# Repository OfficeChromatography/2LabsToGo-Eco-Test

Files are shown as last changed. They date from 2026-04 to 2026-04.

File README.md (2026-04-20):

# 2LabsToGo-Eco

# Important Preliminary Note
<b>In our publication (reference 1) we recommended asking our electronic workshop for a quote on the electronic boards. Unfortunately, that turned out to be very difficult. We therefore recommend contacting Chromnil (https://chromnil.com/), a young start-up also providing the electronic boards or even the 2LabsToGo-Eco ready mounted.<br>
<br>

## 2LabsToGo-Eco combines an analytical (high-performance thin-layer chromatography) and a biological (bioassays) laboratory.

### References:  
<ol>
<li>M.C.O. Romero, K. Jakob, J. Schmidt, T. Nimmerfroh, W. Schwack, G.E.
 Morlock, Consolidating two laboratories into the most sustainable lab of the future: 2LabsToGo-Eco,  Analytica Chimica Acta (2025) 1367, 344103 (https://doi.org/10.1016/j.aca.2025.344103).</li>
<li>A. Haase, W. Schwack, G. Morlock, Humidity control for the 2LabsToGo-Eco, 
Analytica Chimica Acta (2026), 1382, 344811 (https://doi.org/10.1016/j.aca.2025.344811).</li>
<li>W. Schwack, J. Morlock, L. Sing, G. Morlock, Faster Operation of 2LabsToGo-Eco 
 Using Debian 13, Django 5, and Raspberry Pi 5, verified via screening of cannabidiol-containing oils,
 Journal of Planar Chromatography (2026), in revision.</(li>
</ol>
This repository contains the folders for the hardware, firmware, and software for 2LabsToGo-Eco.
For details and instructions consult the given references.

### 1. Raspberry Pi operating system (OS)
The recent Raspberry Pi OS is based on Debain 13 (Trixie, https://www.raspberrypi.com/software/operating-systems/) 
that can be used to install 2LabsToGo-Eco on both the Raspberry Pi 4B and 
the Raspberry Pi 5B (see reference 3).

### 2. Clone the 2LabsToGo-Eco repository
The simplest way to clone a git repository (internet access required!) is opening a new terminal being in the home directory.<br>
Then, copy and paste the next command and press enter.
```bash
git clone https://github.com/OfficeChromatography/2LabsToGo-Eco.git
```
### 3. Installing the software
To install the software, consult this [README](https://github.com/OfficeChromatography/2LabsToGo-Eco/blob/main/2LabsToGo-Eco-Software/README.md).

### 4. Flashing the firmware
Instructions to flash the firmware, can be found [here](https://github.com/OfficeChromatography/2LabsToGo-Eco/blob/main/2LabsToGo-Eco-Firmware/README.md).

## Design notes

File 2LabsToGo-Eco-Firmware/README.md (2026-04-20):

# 2LabsToGo-Eco Firmware 
A Marlin 2.0 3D Printer based Firmware

## Marlin 2.0

Marlin 2.0 takes this popular RepRap firmware to the next level by adding support for much faster 32-bit and ARM-based boards while improving support for 8-bit AVR boards. Read about Marlin's decision to use a "Hardware Abstraction Layer" below.

## Building 2LabsToGo-Eco Firmware

To build the firmware, [PlatformIO](http://docs.platformio.org/en/latest/ide.html#platformio-ide) is preferred. 
Detailed instructions are also available in [Instruction Visual Studio Code](https://github.com/OfficeChromatography/2LabsToGo-Eco/blob/main/2LabsToGo-Eco-Firmware/Instruction%20Visual%20Studio%20Code.pdf).

For building the firmware open the folder 2LabsToGo-Eco-Marlin in Visual Studio Code.
The built firmware.hex file is then saved in 2LabsToGo-Eco-Firmware/2LabsToGo-Eco-Marlin/.pio/build/mega2560.

<b>However, building the firmware is only required, if the Marlin codes have been modified.</b><a>

A pre-built firmware file (firmware_2LabsToGo-Eco.hex) is available in this folder, including files for setting the fuses and flashing the bootloader.
To flash the firmware from the Raspberry Pi onto the Arduino chip of the 2LabsToGo-Eco mainboard, 
use the bash script <u>2LabsToGo-Eco-Firmware/Bullseye/flash_firmware_bullseye.sh</u> or 
<u>2LabsToGo-Eco-Firmware/Trixie/flash_firmware_trixie.sh</u>, depending upon the used Raspberry Pi OS.

For more details on flashing, consult the [2LabsToGo-Eco Assembly guide](https://doi.org/10.1016/j.aca.2025.344103) and reference 3 in this [README](https://github.com/OfficeChromatography/2LabsToGo-Eco/blob/main/README.md).
 
## After firmware update
After a firmware update, both PID tunings must be performed again to save the settings in the firmware.<br>
Consult the [2LabsToGo-Eco Assembly guide](https://doi.org/10.1016/j.aca.2025.344103).

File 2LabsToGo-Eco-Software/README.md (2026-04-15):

# 2LabsToGo-Eco-Software
## Installation
The installation process is really simple. 

2LabsToGo-Eco-Software works fine on a Raspberry Pi 4B or 5B with 4GB RAM memory.

As operation system, Raspberry Pi OS (Debian 13, trixie, 64-bit) is recommended,
installed by the [Raspberry Pi Imager](https://www.raspberrypi.com/software/) (see reference 3 in 
this [README](https://github.com/OfficeChromatography/2LabsToGo-Eco/blob/main/README.md)).

Before the next steps, consult the [checklist](https://github.com/OfficeChromatography/2LabsToGo-Eco/blob/main/2LabsToGo-Update-History/checklist.pdf).

To clone the 2LabsToGo-Eco repository, consult this [README](https://github.com/OfficeChromatography/2LabsToGo-Eco/blob/main/README.md).

### Execute 'install.py'
To install 2LabsToGo-Eco-Software, go to the folder that contains the 2LabsToGo-Eco-Software with

```bash
cd /path/to/your/2LabsToGo-Eco-Software
```
Then execute
```bash
sudo python3 install.py |& tee install-py.log
```

This will install:
```
docker and some software packages
```
After some minutes, 2LabsToGo-Eco-Software is installed in your device.

To start the server execute the run.py file with
```
sudo python3 run.py |& tee run-py.log
```
This process takes a while, when executed the first time. The log files can be consulted in case of any problem.<a>

To quit the Django server, press
```
Ctrl+c 
```

2LabsToGo-Eco-Software was intensively tested with both Chromium and Firefox as browser.

To use the software consult the 2LabsToGo-Eco-Software Manual (see reference 1 in 
this [README](https://github.com/OfficeChromatography/2LabsToGo-Eco/blob/main/README.md)).

### Useful guides

[Docker Commands](https://towardsdatascience.com/15-docker-commands-you-should-know-970ea5203421)

[Remove Migrations](https://simpleisbetterthancomplex.com/tutorial/2016/07/26/how-to-reset-migrations.html)

All commands must be executed inside the docker-compose. To enter to the docker-compose running instance:

In a running container:
```sh
sudo docker-compose exec -ti app bash
```
To initialize and enter the terminal
```sh
sudo docker-compose run -ti app bash
```

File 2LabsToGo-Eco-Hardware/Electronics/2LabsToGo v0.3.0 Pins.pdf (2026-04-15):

2LabsToGo V0.3.0 Pinout List

Arduino Pin Malin Analog Marlin Pin Atmega Port Funktion
22 | 22 | A0 | DHT22 Incubator
23 | 23 | A1 | Heater Bed
24 | 24 | A2 | Heater Incubator
25 | 25 | A3 | Expansion
26 | 26 | A4 | Expansion
27 | 27 | A5 | Expansion
28 | 28 | A6 | Expansion
29 | 29 | A7 | Expansion
53 | 53 | B0 | E0-DIR
52 | 52 | B1 | SPI SCLK
51 | 51 | B2 | SPI MOSI
50 | 50 | B3 | SPI MISO
10 | 10 | B4 | Z-EN
11 | 11 | B5 | Z-STEP
12 | 12 | B6 | Z-DIR
13 | 13 | B7 | LED Backlight
37 | 37 | C0 | HF-Valve
36 | 36 | C1 | 3-WAY-Valve
35 | 35 | C2 | Expansion
34 | 34 | C3 | Expansion
33 | 33 | C4 | Expansion
32 | 32 | C5 | Expansion
31 | 31 | C6 | Expansion
30 | 30 | C7 | Expansion
21 | 21 | D0 | I2C SLC
20 | 20 | D1 | I2C SDA
19 | 19 | D2 | NC
18 | 18 | D3 | NC
| 81 | D4 | NC
| 82 | D5 | NC
| 83 | D6 | NC
38 | 38 | D7 | NC
0 | 0 | E0 | UART RX
1 | 1 | E1 | UART TX
| 78 | E2 | NC
5 | 5 | E3 | UV-LED 1 (265)
2 | 2 | E4 | UV-LED 2 (365)
3 | 3 | E5 | Nebulizer
| 79 | E6 | Y-EN
| 80 | E7 | Y-STEP
A0/54 | A0 54 | F0 | Neopixel
A1/55 | A1 55 | F1
A2/56 | A2 56 | F2
A3/57 | A3 57 | F3 | Expansion
A4/58 | A4 58 | F4 | Expansion
A5/59 | A5 59 | F5 | Expansion
A6/60 | A6 60 | F6 | Expansion
A7/61 | A7 61 | F7 | Expansion
41 | 41 | G0 | Case Light

2LabsToGo V0.3.0 Pinout List

40 | 40 | G1 | PUMPE
39 | 39 | G2 | Expansion
| 71 | G3 | NC
| 70 | G4 | NC
4 | 4 | G5 | NC
17 | 17 | H0 | Y-DIR
16 | 16 | H1 | X-EN
| 84 | H2 | X-STEP
6 | 6 | H3 | X-DIR
7 | 7 | H4 | E0-EN
8 | 8 | H5 | E0-STEP
9 | 9 | H6 | Heater External
| 85 | H7
15 | 15 | J0 | Expansion
14 | 14 | J1 | Expansion
| 72 | J2 | Expansion
| 73 | J3 | Expansion
| 75 | J4 | Expansion
| 76 | J5 | Expansion
| 77 | J6 | Expansion
| 74 | J7 | NC
A8/62 | A8 62 | K0 | Expansion
A9/63 | A9 63 | K1 | Expansion
A10/64 | A10 64 | K2 | Expansion
A11/65 | A11 65 | K3 | Expansion
A12/66 | A12 66 | K4 | Expansion
A13/67 | A13 67 | K5 | Termistor Incubator
A14/68 | A14 68 | K6 | Termistor Bed
A15/69 | A15 69 | K7 | Thermistor External
47 | 49 | L0 | Switch Z-Axis to Syringe Pump
48 | 48 | L1 | Z-MIN (switched)
47 | 47 | L2 | X-MAX
46 | 46 | L3 | X-MIN
45 | 45 | L4 | Y-MAX
42 | 44 | L5 | Y-MIN
41 | 43 | L6 | Z-MAX
42 | 42 | L7 | DHT22 Kammer

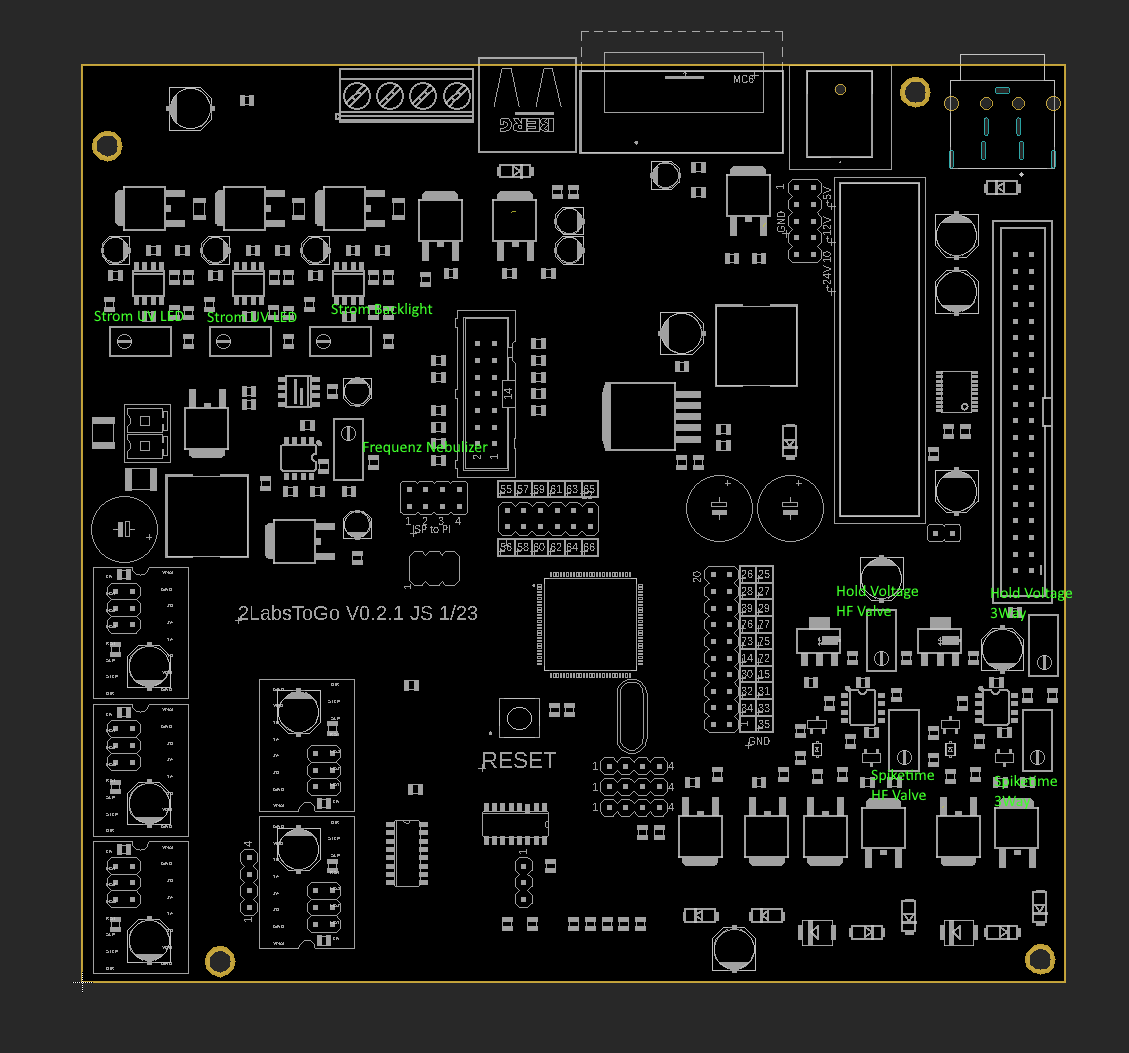
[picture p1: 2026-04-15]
2LabsToGo-Eco-Hardware/Electronics/poti_raw.PNG

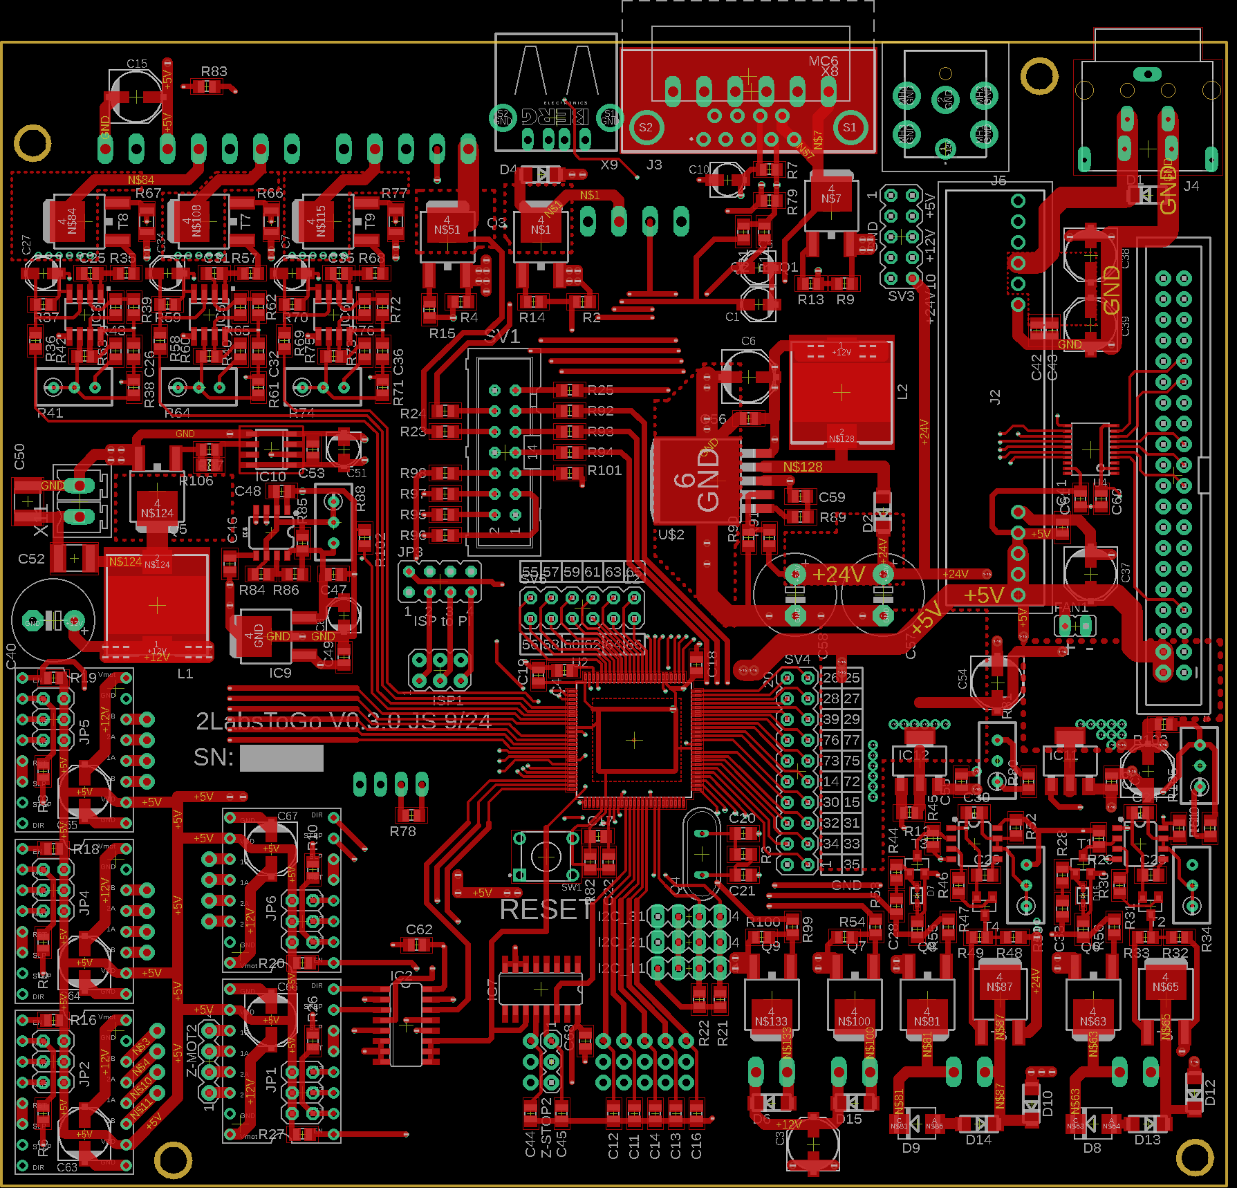
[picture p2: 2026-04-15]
2LabsToGo-Eco-Hardware/Electronics/Mainboard/Layout Top.png

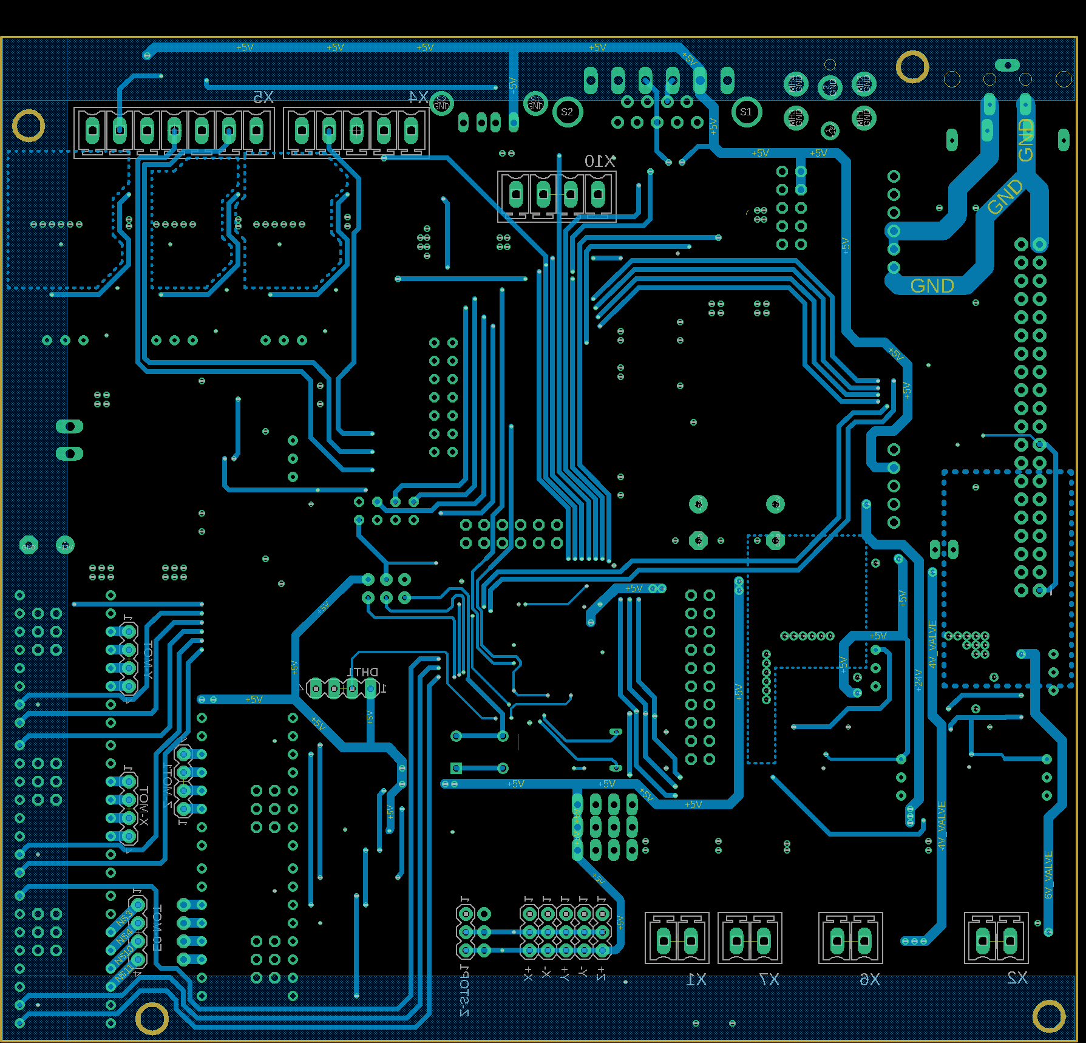
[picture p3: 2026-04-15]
2LabsToGo-Eco-Hardware/Electronics/Mainboard/Layout Bottom.png

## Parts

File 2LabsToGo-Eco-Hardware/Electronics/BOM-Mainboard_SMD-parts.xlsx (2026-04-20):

 | SMD parts
ID | Designator | Qty. | Manufacturer | Manufacturer Part # | Description | Type | Footprint
1 | C2,C3,C6,C15,C37,C38,C39,C54,C63,C64,C65,C66,C67 | 13 | Panasonic | EEE-FK1E101XP | Aluminium Electrolytic Capacitors - SMD 100uF 25V | SMD | PANASONIC_D_334
2 | C9,C11,C12,C13,C14,C16,C17,C18,C19,C23,C24,C25,C26,C29,C31,C32,C35,C36,C4,C41,C42,C43,C44,C45,C47,C49,C53,C55,C56,C60,C61,C62,C68 | 33 | KEMET | C0805C104K5RACTU | Multilayer Ceramic Capacitors MLCC - SMD/SMT 50V 0.1uF X7R 0805 10% | SMD | C0805
3 | C20,C21 | 2 | KEMET | C0805C220K5RACTU | Multilayer Ceramic Capacitors MLCC - SMD/SMT 50V 22pF X7R 0805 10% | SMD | C0805_334
4 | C28,C33 | 2 | KEMET | C0805C681K5RACTU | Multilayer Ceramic Capacitors MLCC - SMD/SMT 50V 680pF X7R 0805 10% | SMD | C0805_334
5 | C30,C46 | 2 | KEMET | C0805C223K5RACTU | Multilayer Ceramic Capacitors MLCC - SMD/SMT 50V 0.022uF X7R 0805 10% | SMD | C0805_334
6 | C1,C5,C7,C8,C10,C27,C34,C51 | 8 | Panasonic | EEE-FK1E100AR | Aluminium Electrolytic Capacitors - SMD 10UF 25V FK SMD | SMD | PANASONIC_B_334
7 | C22,C48 | 2 | KEMET | C0805C101F3HACTU | Multilayer Ceramic Capacitors MLCC - SMD/SMT 25V 100pF X8R 0805 1% | SMD | C0805_334
8 | C50 | 1 | KEMET | C1812C102KHRACTU | Multilayer Ceramic Capacitors MLCC - SMD/SMT 3kV 1000pF X7R 1812 10% | SMD | C1812_334
9 | C52 | 1 | KEMET | C1812C334KCRACTU | Multilayer Ceramic Capacitors MLCC - SMD/SMT 500V 0.33uF X7R 1812 10% | SMD | C1812_334
10 | C59 | 1 | KEMET | C0805C473K5RACTU | Multilayer Ceramic Capacitors MLCC - SMD/SMT 50V 0.047uF X7R 0805 10% | SMD | C0805
11 | D4,D6,D12,D13,D14,D15 | 6 | onsemi | RGF1G | Rectifiers 400V 1a Rectifier Glass Passivated | SMD | DO214AC_210
12 | D7,D16 | 2 | onsemi | 1N4148WS | Small Signal Switching Diodes Small Signal Diode | SMD | SOD-323_11396254
13 | D1,D2,D10 | 3 | Comchip Technology | SS54-HF | Schottky Diodes & Rectifiers DIODE SCHOTTKY 5A 40V SMA | SMD | DO214AC
14 | D8,D9 | 2 | Vishay | SML4757A-E3/61 | Zener Diodes 51 Volt 1.0W 5% | SMD | DO-214AC-2
15 | IC10 | 1 | Microchip Technology | MIC4420ZM-TR | Gate Drivers 8 SOIC 3.90mm(.150in) T/R | SMD | SOIC-8
16 | IC11,IC12 | 2 | onsemi | LM1117MPX-ADJNOPB | LDO Voltage Regulators LM ANA SOT223 800MA LDO | SMD | SOT-223-3
17 | IC2,IC7 | 2 | Nexperia | 74HC4053D,653 | Multiplexer Switch ICs Triple 2-channel analog multiplexer/demultiplexer | SMD | SOIC-16
18 | IC1,IC4 | 2 | Texas Instruments | NE555DR | Timers & Support Products Precision A 595-NE555D | SMD | SOIC-8
19 | IC3,IC5,IC6 | 3 | Texas Instruments | LM358MX/NOPB | Operational Amplifiers - Op Amps LOW PWR DUAL OP AMP A 926-LM358M/NOPB | SMD | SOIC-8
20 | IC8 | 1 | Texas Instruments | SE555DRG4 | Timers & Support Products Prec Timer ALT 595-SE555DR | SMD | SOIC-8
21 | IC9 | 1 | Diodes Incorporated | AS7805ADTR-G1 | Linear Voltage Regulators 1A 3-Term POS Reg Output 1A | SMD | TO-252-2
22 | Q1,Q2,Q3,Q6,Q7,Q8,Q9 | 7 | Infineon Technologies | IRFR3410TRPBF | MOSFETs 100V SINGLE N-CH 39mOhms 37nC | SMD | TO-252-3
23 | Q5 | 1 | Infineon Technologies | IPD60R180P7SAUMA1 | MOSFETs CONSUMER | SMD | TO-252-3
24 | R10,R9,R56,R55,R6,R2,R26,R5,R8,R54,R100,R4,R82 | 13 | YAGEO | RC0805FR-07100KL | Thick Film Resistors - SMD 100 kOhms 125 mW 0805 1% | SMD | R0805_334
25 | R103,R12 | 2 | YAGEO | RC0805FR-13120RL | Thick Film Resistors - SMD 120Ohms 1/8W 0805 1% | SMD | R0805_334
26 | R13,R14,R15,R31,R47,R53,R87,R99,R106 | 9 | YAGEO | RC0805FR-0710RL | Thick Film Resistors - SMD 10 Ohms 125 mW 0805 1% | SMD | R0805_334
27 | R23,R24,R25,R35,R38,R40,R57,R61,R63,R68,R71,R73,R90,R95,R96,R97 | 16 | YAGEO | RC0805FR-071KL | Thick Film Resistors - SMD 1 kOhms 125 mW 0805 1% | SMD | R0805_334
28 | R16,R18,R19,R20,R27,R29,R32,R36,R43,R45,R48,R58,R65,R69,R76,R78,R79 | 17 | YAGEO | RC0805FR-0710KL | Thick Film Resistors - SMD 10 kOhms 125 mW 0805 1% | SMD | R0805_334
29 | R3,R39,R62,R72 | 4 | YAGEO | RC0805FR-071ML | Thick Film Resistors - SMD 1 MOhms 125 mW 0805 1% | SMD | R0805_334
30 | R66,R67,R77 | 3 | YAGEO | RL1206FR-070R1L | Current Sense Resistors - SMD 100 mOhms 250mW 1 % 600 ppm/C | SMD | R1206_334
31 | R1,R7,R11,R21,R22,R33,R37,R49,R59,R70,R102 | 11 | YAGEO | RC0805FR-074K7L | Thick Film Resistors - SMD 4.7 kOhms 125 mW 0805 1% | SMD | R0805_334
32 | R83 | 1 | YAGEO | RC0805FR-07100RL | Thick Film Resistors - SMD 100 Ohms 125 mW 0805 1% | SMD | R0805_334
33 | R84 | 1 | YAGEO | RC0805JR-7W15KL | Thick Film Resistors - SMD 15kOhms 1/8W 0805 5% | SMD | R0805_334
34 | R89 | 1 | YAGEO | RC0805FR-073KL | Thick Film Resistors - SMD 3 kOhms 125 mW 0805 1% | SMD | R0805_334
35 | R91 | 1 | YAGEO | RC0805FR-0718K2L | Thick Film Resistors - SMD 18.2 kOhms 125 mW 0805 1% | SMD | R0805_334
36 | R94,R92,R30,R98,R28,R46,R101,R93,R44 | 9 | YAGEO | RC0805FR-07330RL | Thick Film Resistors - SMD 330 Ohms 125 mW 0805 1% | SMD | R0805_334
37 | T3,T1,T2,T4 | 4 | Nexperia | BC847C,215 | Bipolar Transistors - BJT 45 V, 100 mA NPN general-purpose transistors | SMD | SOT23_3
38 | T5,T6 | 2 | onsemi | MJD128T4G | Darlington Transistors BIP PNP 8A 120V TR | SMD | TO-252-3
39 | T7,T8,T9 | 3 | onsemi | MJD200G | Bipolar Transistors - BJT 5A 25V 12.5W NPN | SMD | TO-252-3
40 | U$2 | 1 | Texas Instruments | LM2577SX-ADJ/NOPB | IC REG BST FLYBACK ADJ 3A TO263 | SMD | TO-263-5
41 | U2 | 1 | Microchip Technology | ATMEGA2560-16AU | AVR AVR® ATmega Mikrocontroller IC 8-Bit 16MHz 256KB (128K x 16) FLASH 100-TQFP (14x14) | SMD | TQFP-100
42 | U4 | 1 | Texas Instruments | TXB0108PWR | Translation - Voltage Levels 8-Bit Bi-directional V-Level Translator A 595-TXB0108PWRG4 | SMD | TSSOP-20
43 | L1 | 1 | Würth Elektronik | 74477020 | FIXED IND 100UH 2.2A 220 MOHM | SMD
44 | L2 | 1 | Würth Elektronik | 744770222 | FIXED IND 220UH 1.3A 390 MOHM | SMD

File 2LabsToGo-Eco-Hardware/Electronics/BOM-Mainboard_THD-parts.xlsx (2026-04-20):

 | Through hole parts (THD)
ID | Designator | Qty. | Manufacturer | Manufacturer Part # | Description | Type | Footprint
1 | C40, C57, C58 | 3 | Panasonic Electronic Components | EEU-FR1V471L | CAP ALUM 470UF 20% 35V RADIAL TH | THD
2 | J4 | 1 | Kycon Inc. | KPJX-4S-S | CONN JACK FMALE 4POS TIN SOLDER | THD
3 | J5 | 2 | Same Sky (Formerly CUI Devices) | PJ-082BH | CONN PWR JACK 2.5X5.5MM SOLDER | THD
4 | J6 | 1 | 3M | Y2540-6002-SH 40P ST HDR 0.112 GF | 3M FOUR-WALL HEADER 2500 SERIES | THD
5 | Q4 | 1 | Abracon LLC | ABL-16.000MHZ-B2 | CRYSTAL 16.0000MHZ 18PF TH | THD
6 | R105 | 1 | Bourns Inc. | 3296W-1-102LF | TRIMMER 1K OHM 0.5W PC PIN TOP | THD
7 | R34, R50 | 2 | Bourns Inc. | 3296W-1-504LF | TRIMMER 500K OHM 0.5W PC PIN TOP | THD
8 | R41, R64, R74 | 3 | Bourns Inc. | 3296W-1-204LF | TRIMMER 200K OHM 0.5W PC PIN TOP | THD
9 | R81 | 1 | Bourns Inc. | 3296W-1-501LF | TRIMMER 500 OHM 0.5W PC PIN TOP | THD
10 | SV1 | 1 | 3M | Y2514-6002-SH 14P ST HDR 0.112 GF | 3M FOUR-WALL HEADER 2500 SERIES | THD
11 | U$1, U$4, U$6, U$7, U$8 | 20 | Amphenol CS (FCI) | 75915-308GLF | CONN RCPT 8POS 0.1 GOLD PCB | THD
12 | X1, X2, X6, X7, X11 | 5 | Phoenix Contact | 1803426 | TERM BLOCK HDR 2POS 3.81MM | THD
13 | X4 | 2 | Phoenix Contact | 1803455 | TERM BLOCK HDR 5POS 3.81MM | THD
14 | X5 | 1 | Phoenix Contact | 1803471 | TERM BLOCK HDR 7POS 3.81MM | THD
15 | X9 | 1 | Amphenol CS (FCI) | 87520-0010BLF | CONN RCPT USB2.0 TYPEA 4POS R/A | THD
16 | I2C_1, I2C_2, I2C_3, Z-MOT1, Z-MOT2, X-MOT, Y-MOT, E0-MOT, Z-STOP1, Z-STOP2, X-, X+, Y-, Y+, Z+, FAN1 | 3 | Amphenol CS (FCI) | 68002-420HLF | CONN HEADER VERT 20POS 2.54MM 1) | THD
17 | JP3 | 1 | Amphenol CS (FCI) | 67996-408HLF | CONN HEADER VERT 8POS 2.54MM | THD
18 | ISP1, JP1, JP2, JP4, JP5, JP6 | 6 | Amphenol CS (FCI) | 67996-406HLF | CONN HEADER VERT 6POS 2.54MM | THD
19 | SV3 | 1 | Amphenol CS (FCI) | 67996-410HLF | CONN HEADER VERT 10POS 2.54MM | THD
20 | SV4 | 1 | Amphenol CS (FCI) | 67996-420HLF | CONN HEADER VERT 20POS 2.54MM | THD
21 | SV5 | 1 | Amphenol CS (FCI) | 67996-412HLF | CONN HEADER VERT 12POS 2.54MM | THD
22 | X8 | 1 | Phoenix Contact | 1876301 | TERM BLOCK HDR 6POS 3.50MM | THD
23 | SW1 | 1 | TE Connectivity ALCOSWITCH Switches | 1825910-6 | SWITCH TACTILE SPST-NO 0.05A 24V | THD
24 | R88 | 1 | Bourns Inc. | 3296W-1-104ALF | TRIMMER 100K OHM 0.5W PC PIN TOP | THD
25 | J2 | 1 | Mean Well USA Inc. | NID65-5 | DC DC CONVERTER 5V 33W | THD
26 | X10 | 1 | Phoenix Contact | 1755752 | TERM BLOCK HDR 4POS 5.08MM | THD
27 | DHT1 | 1 | Molex | 901471104 | CONN RCPT 4POS 0.1 TIN PCB | THD
 | 1) Header to be cut to 2-pin (FAN1), 3-pin (Z-STOP1, Z-STOP2, X-, X+, Y-, Y+, Z+) and 4-pin (I2C_1, I2C_2, I2C_3, Z-MOT1, Z-MOT2, X-MOT, Y-MOT, E0-MOT) parts, respectively

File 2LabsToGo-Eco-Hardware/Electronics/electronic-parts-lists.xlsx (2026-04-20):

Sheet: mainboard
 | SMD parts
ID | Designator | Manufacturer No | Manufacturer | Description | Termination Style | Footprint | Qty.
1 | C2,C3,C6,C15,C37,C38,C39,C54,C63,C64,C65,C66,C67 | EEE-FK1E101XP | Panasonic | Aluminium Electrolytic Capacitors - SMD 100uF 25V | SMD | PANASONIC_D_334 | 13
2 | C9,C11,C12,C13,C14,C16,C17,C18,C19,C23,C24,C25,C26,C29,C31,C32,C35,C36,C4,C41,C42,C43,C44,C45,C47,C49,C53,C55,C56,C60,C61,C62,C68 | C0805C104K5RACTU | KEMET | Multilayer Ceramic Capacitors MLCC - SMD/SMT 50V 0.1uF X7R 0805 10% | SMD | C0805 | 33
3 | C20,C21 | C0805C220K5RACTU | KEMET | Multilayer Ceramic Capacitors MLCC - SMD/SMT 50V 22pF X7R 0805 10% | SMD | C0805_334 | 2
4 | C28,C33 | C0805C681K5RACTU | KEMET | Multilayer Ceramic Capacitors MLCC - SMD/SMT 50V 680pF X7R 0805 10% | SMD | C0805_334 | 2
5 | C30,C46 | C0805C223K5RACTU | KEMET | Multilayer Ceramic Capacitors MLCC - SMD/SMT 50V 0.022uF X7R 0805 10% | SMD | C0805_334 | 2
6 | C1,C5,C7,C8,C10,C27,C34,C51 | EEE-FK1E100AR | Panasonic | Aluminium Electrolytic Capacitors - SMD 10UF 25V FK SMD | SMD | PANASONIC_B_334 | 8
7 | C22,C48 | C0805C101F3HACTU | KEMET | Multilayer Ceramic Capacitors MLCC - SMD/SMT 25V 100pF X8R 0805 1% | SMD | C0805_334 | 2
8 | C50 | C1812C102KHRACTU | KEMET | Multilayer Ceramic Capacitors MLCC - SMD/SMT 3kV 1000pF X7R 1812 10% | SMD | C1812_334 | 1
9 | C52 | C1812C334KCRACTU | KEMET | Multilayer Ceramic Capacitors MLCC - SMD/SMT 500V 0.33uF X7R 1812 10% | SMD | C1812_334 | 1
10 | C59 | C0805C473K5RACTU | KEMET | Multilayer Ceramic Capacitors MLCC - SMD/SMT 50V 0.047uF X7R 0805 10% | SMD | C0805 | 1
11 | D4,D6,D12,D13,D14,D15 | RGF1G | onsemi | Rectifiers 400V 1a Rectifier Glass Passivated | SMD | DO214AC_210 | 6
12 | D7,D16 | 1N4148WS | onsemi | Small Signal Switching Diodes Small Signal Diode | SMD | SOD-323_11396254 | 2
13 | D1,D2,D10 | SS54-HF | Comchip Technology | Schottky Diodes & Rectifiers DIODE SCHOTTKY 5A 40V SMA | SMD | DO214AC | 3
14 | D8,D9 | SML4757A-E3/61 | Vishay | Zener Diodes 51 Volt 1.0W 5% | SMD | DO-214AC-2 | 2
15 | IC10 | MIC4420ZM-TR | Microchip Technology | Gate Drivers 8 SOIC 3.90mm(.150in) T/R | SMD | SOIC-8 | 1
16 | IC11,IC12 | LM1117MPX-ADJNOPB | onsemi | LDO Voltage Regulators LM ANA SOT223 800MA LDO | SMD | SOT-223-3 | 2
17 | IC2,IC7 | 74HC4053D,653 | Nexperia | Multiplexer Switch ICs Triple 2-channel analog multiplexer/demultiplexer | SMD | SOIC-16 | 2
18 | IC1,IC4 | NE555DR | Texas Instruments | Timers & Support Products Precision A 595-NE555D | SMD | SOIC-8 | 2
19 | IC3,IC5,IC6 | LM358MX/NOPB | Texas Instruments | Operational Amplifiers - Op Amps LOW PWR DUAL OP AMP A 926-LM358M/NOPB | SMD | SOIC-8 | 3
20 | IC8 | SE555DRG4 | Texas Instruments | Timers & Support Products Prec Timer ALT 595-SE555DR | SMD | SOIC-8 | 1
21 | IC9 | AS7805ADTR-G1 | Diodes Incorporated | Linear Voltage Regulators 1A 3-Term POS Reg Output 1A | SMD | TO-252-2 | 1
22 | Q1,Q2,Q3,Q6,Q7,Q8,Q9 | IRFR3410TRPBF | Infineon Technologies | MOSFETs 100V SINGLE N-CH 39mOhms 37nC | SMD | TO-252-3 | 7
23 | Q5 | IPD60R180P7SAUMA1 | Infineon Technologies | MOSFETs CONSUMER | SMD | TO-252-3 | 1
24 | R10,R9,R56,R55,R6,R2,R26,R5,R8,R54,R100,R4,R82 | RC0805FR-07100KL | YAGEO | Thick Film Resistors - SMD 100 kOhms 125 mW 0805 1% | SMD | R0805_334 | 13
25 | R103,R12 | RC0805FR-13120RL | YAGEO | Thick Film Resistors - SMD 120Ohms 1/8W 0805 1% | SMD | R0805_334 | 2
26 | R13,R14,R15,R31,R47,R53,R87,R99,R106 | RC0805FR-0710RL | YAGEO | Thick Film Resistors - SMD 10 Ohms 125 mW 0805 1% | SMD | R0805_334 | 9
27 | R23,R24,R25,R35,R38,R40,R57,R61,R63,R68,R71,R73,R90,R95,R96,R97 | RC0805FR-071KL | YAGEO | Thick Film Resistors - SMD 1 kOhms 125 mW 0805 1% | SMD | R0805_334 | 16
28 | R16,R18,R19,R20,R27,R29,R32,R36,R43,R45,R48,R58,R65,R69,R76,R78,R79 | RC0805FR-0710KL | YAGEO | Thick Film Resistors - SMD 10 kOhms 125 mW 0805 1% | SMD | R0805_334 | 17
29 | R3,R39,R62,R72 | RC0805FR-071ML | YAGEO | Thick Film Resistors - SMD 1 MOhms 125 mW 0805 1% | SMD | R0805_334 | 4
30 | R66,R67,R77 | RL1206FR-070R1L | YAGEO | Current Sense Resistors - SMD 100 mOhms 250mW 1 % 600 ppm/C | SMD | R1206_334 | 3
31 | R1,R7,R11,R21,R22,R33,R37,R49,R59,R70,R102 | RC0805FR-074K7L | YAGEO | Thick Film Resistors - SMD 4.7 kOhms 125 mW 0805 1% | SMD | R0805_334 | 11
32 | R83 | RC0805FR-07100RL | YAGEO | Thick Film Resistors - SMD 100 Ohms 125 mW 0805 1% | SMD | R0805_334 | 1
33 | R84 | RC0805JR-7W15KL | YAGEO | Thick Film Resistors - SMD 15kOhms 1/8W 0805 5% | SMD | R0805_334 | 1
34 | R89 | RC0805FR-073KL | YAGEO | Thick Film Resistors - SMD 3 kOhms 125 mW 0805 1% | SMD | R0805_334 | 1
35 | R91 | RC0805FR-0718K2L | YAGEO | Thick Film Resistors - SMD 18.2 kOhms 125 mW 0805 1% | SMD | R0805_334 | 1
36 | R94,R92,R30,R98,R28,R46,R101,R93,R44 | RC0805FR-07330RL | YAGEO | Thick Film Resistors - SMD 330 Ohms 125 mW 0805 1% | SMD | R0805_334 | 9
37 | T3,T1,T2,T4 | BC847C,215 | Nexperia | Bipolar Transistors - BJT 45 V, 100 mA NPN general-purpose transistors | SMD | SOT23_3 | 4
38 | T5,T6 | MJD128T4G | onsemi | Darlington Transistors BIP PNP 8A 120V TR | SMD | TO-252-3 | 2
39 | T7,T8,T9 | MJD200G | onsemi | Bipolar Transistors - BJT 5A 25V 12.5W NPN | SMD | TO-252-3 | 3
40 | U$2 | LM2577SX-ADJ/NOPB | Texas Instruments | Switching Voltage Regulators Step-Up Vtg Reg A 926-LM2577S-ADJ/NOPB | SMD | TO-263-5 | 1
41 | U2 | ATMEGA2560-16AU | Microchip Technology | AVR AVR® ATmega Mikrocontroller IC 8-Bit 16MHz 256KB (128K x 16) FLASH 100-TQFP (14x14) | SMD | TQFP-100 | 1
42 | U4 | TXB0108PWR | Texas Instruments | Translation - Voltage Levels 8-Bit Bi-directional V-Level Translator A 595-TXB0108PWRG4 | SMD | TSSOP-20 | 1
43 | L1 | 74477020 | Wurth Electronic | Power Inductors - SMD WE-PD 100uH 2.2A DCR=220mOhms AEC-Q200 | surface mount | WE-CHSA_1212_14076700 | 1
44 | L2 | 744770222 | Wurth Electronic | Power Inductors - SMD WE-PD 220uH 1.3A DCR=390mOhms AEC-Q200 | surface mount | WE-CHSA_1212_14076700 | 1
 | Through hole parts
ID | Designator | Manufacturer No | Manufacturer | Description | Termination Style | Footprint | Qty.
1 | C40,C58,C57 | EEU-FR1V471L | Panasonic | Aluminium Electrolytic Capacitors - Radial Leaded 35VDC 470uF 8x20mm LS5mm | Through Hole | E5-10,5_334 | 3
2 | J2 | NID65-5 | MEAN WELL | Non-Isolated DC/DC Converters 32.5W 24Vin 5Vout Non-Iso Reg SIP | Through Hole | SIP-11 | 1
3 | J4 | KPJX-4S-S | Kycon | DC Power Connectors 4P JACK SKT SHIELDED SNAP AND LOCK | Through Hole | KYCON_KPJX-4S-S | 1
4 | J5 | PJ-082BH | Same Sky (https://www.mouser.de/manufacturer/same-sky/) | DC Power Connectors 2.5mm x 5.5mm horz | Through Hole | PJ082BH_vf.QJzKeZqrQ1Gobk2092XC6w | 1
5 | J6 | Y2540-6002-SH 40P ST HDR 0.112 GF | 3M | Headers & Wire Housings 3M Four-Wall Header 2500 Series, 40 Pin Straight Header, 0.112 Tail Length, Gold Flash | Through Hole | 2X20_SHROUDED_513 | 1
6 | Q4 | ABL-16.000MHZ-B2 | ABRACON | Crystals Xtal HC-49/US 3.5mm Height 16MHz Tol +/-20ppm Stab +/-50ppm -20°C ~ 70°C 18pF 40 Ohms | Through Hole | QS_367 | 1
7 | R105 | 3296W-1-102LF | Bourns | Trimmer Resistors - Through Hole 3/8" 1Kohms Sealed Vertical Adjust | Through Hole | RTRIM3296W | 1
8 | R34,R50 | 3296W-1-504LF | Bourns | Trimmer Resistors - Through Hole 3/8" 500Kohms Sealed Vertical Adjust | Through Hole | RTRIM3296W | 2
9 | R74,R64,R41 | 3296W-1-204LF | Bourns | Trimmer Resistors - Through Hole 3/8" 200Kohms Sealed Vertical Adjust | Through Hole | RTRIM3296W | 3
10 | R81 | 3296W-1-501LF | Bourns | Trimmer Resistors - Through Hole 3/8IN 500 OHM Sealed Vertical Adjust | Through Hole | RTRIM3296W | 1
11 | R88 | 3296W-1-104ALF | YAGEO | Trimmer Resistors - Through Hole 3/8" 100Kohms Sealed Vertical Adjust | Through Hole | RTRIM3296W | 1
12 | SV1 | Y2514-6002-SH 14P ST HDR 0.112 GF | 3M | Headers & Wire Housings 3M Four-Wall Header 2500 Series, 14 Pin Straight Header, 0.112 Tail Length, Gold Flash | Through Hole | ML14_149 | 1
13 | SW1 | 1825910-6 | TE Connectivity | Tactile Switches FSM4JH=6MM TACT SWITCH, HIGH TEMP | Through Hole | 1825910-6_11396471 | 1
14 | U$4,U$1,U$6,U$8,U$7 | 535541-6 | TE Connectivity | Headers & Wire Housings VERT RECPT 8 POS | Through Hole | A4988BREAKOUT | 5x2
15 | X10 | 1757268 | Phoenix Contact | Pluggable Terminal Blocks 4 Pos 5.08mm pitch Through Hole Header | Through Hole | MCV4 | 1
16 | X11,X2,X7,X1,X6 | 1803426 | Phoenix Contact | Pluggable Terminal Blocks 2 Pos 3.81mm pitch Through Hole Header | Through Hole | MCV2 | 5
17 | X4 | 1803455 | Phoenix Contact | Pluggable Terminal Blocks 5 Pos 3.81mm pitch Through Hole Header | Through Hole | MCV5 | 1
18 | X5 | 1803471 | Phoenix Contact | Pluggable Terminal Blocks 7 Pos 3.81mm pitch Through Hole Header | Through Hole | MCV7 | 1
19 | X8 | 1876301 | Phoenix Contact | Pluggable Terminal Blocks 6 Pos 3.5mm pitch Through Hole Header | Through Hole | MC6 | 1
20 | X9 | 87520-0010BLF | Amphenol FCI | USB Connectors USB S/D RECEPT | Through Hole | PN87520-S_130 | 1
21 | I2C_3,I2C_1,I2C_2 | 68002-420HLF | Amphenol FCI | Headers & Wire Housings 20P SR UNSHRD HRD TIN OVER NI | Through Hole | MA04-1 | 3
22 | FAN1 | see 21 |  |  | Through Hole | Ma02-1
23 | Z-MOT2,Y-MOT0,X-MOT0,E0-MOT0,Z-MOT1 | see 21 |  |  | Through Hole | MA04-1
24 | Z-STOP2,Y-0,X-0,X+0,Z-STOP1,Z+0,Y+0 | see 21 |  |  | Through Hole | MA03-1
25 | JP3 | 67996-408HLF | Amphenol FCI | Headers & Wire Housings 8P DR UNSHRD HRD TIN OVER NI | Through Hole | MA04_2, 2x4 pins | 1
26 | SV3 | 67996-410HLF | Amphenol FCI | Headers & Wire Housings 10P DR UNSHRD HRD TIN OVER NI | Through Hole | MA05-2, 2x5 pins | 1
27 | SV4 | 67996-420HLF | Amphenol FCI | Headers & Wire Housings 20P DR UNSHRD HRD TIN OVER NI | Through Hole | MA10-2, 2x10 pins | 1
28 | SV5 | 67996-412HLF | Amphenol FCI | Headers & Wire Housings 12P DR UNSHRD HRD TIN OVER NI | Through Hole | MA06-2, 2x6 pins | 1
 | DHT1?
 | Extern buttom??

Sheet: mainboard-smd
 | SMD parts
ID | Designator | Manufacturer No | Manufacturer | Description | Termination Style | Footprint | Qty.
1 | C2,C3,C6,C15,C37,C38,C39,C54,C63,C64,C65,C66,C67 | EEE-FK1E101XP | Panasonic | Aluminium Electrolytic Capacitors - SMD 100uF 25V | SMD | PANASONIC_D_334 | 13
2 | C9,C11,C12,C13,C14,C16,C17,C18,C19,C23,C24,C25,C26,C29,C31,C32,C35,C36,C4,C41,C42,C43,C44,C45,C47,C49,C53,C55,C56,C60,C61,C62,C68 | C0805C104K5RACTU | KEMET | Multilayer Ceramic Capacitors MLCC - SMD/SMT 50V 0.1uF X7R 0805 10% | SMD | C0805 | 33
3 | C20,C21 | C0805C220K5RACTU | KEMET | Multilayer Ceramic Capacitors MLCC - SMD/SMT 50V 22pF X7R 0805 10% | SMD | C0805_334 | 2
4 | C28,C33 | C0805C681K5RACTU | KEMET | Multilayer Ceramic Capacitors MLCC - SMD/SMT 50V 680pF X7R 0805 10% | SMD | C0805_334 | 2
5 | C30,C46 | C0805C223K5RACTU | KEMET | Multilayer Ceramic Capacitors MLCC - SMD/SMT 50V 0.022uF X7R 0805 10% | SMD | C0805_334 | 2
6 | C1,C5,C7,C8,C10,C27,C34,C51 | EEE-FK1E100AR | Panasonic | Aluminium Electrolytic Capacitors - SMD 10UF 25V FK SMD | SMD | PANASONIC_B_334 | 8
7 | C22,C48 | C0805C101F3HACTU | KEMET | Multilayer Ceramic Capacitors MLCC - SMD/SMT 25V 100pF X8R 0805 1% | SMD | C0805_334 | 2
8 | C50 | C1812C102KHRACTU | KEMET | Multilayer Ceramic Capacitors MLCC - SMD/SMT 3kV 1000pF X7R 1812 10% | SMD | C1812_334 | 1
9 | C52 | C1812C334KCRACTU | KEMET | Multilayer Ceramic Capacitors MLCC - SMD/SMT 500V 0.33uF X7R 1812 10% | SMD | C1812_334 | 1
10 | C59 | C0805C473K5RACTU | KEMET | Multilayer Ceramic Capacitors MLCC - SMD/SMT 50V 0.047uF X7R 0805 10% | SMD | C0805 | 1
11 | D4,D6,D12,D13,D14,D15 | RGF1G | onsemi | Rectifiers 400V 1a Rectifier Glass Passivated | SMD | DO214AC_210 | 6
12 | D7,D16 | 1N4148WS | onsemi | Small Signal Switching Diodes Small Signal Diode | SMD | SOD-323_11396254 | 2
13 | D1,D2,D10 | SS54-HF | Comchip Technology | Schottky Diodes & Rectifiers DIODE SCHOTTKY 5A 40V SMA | SMD | DO214AC | 3
14 | D8,D9 | SML4757A-E3/61 | Vishay | Zener Diodes 51 Volt 1.0W 5% | SMD | DO-214AC-2 | 2
15 | IC10 | MIC4420ZM-TR | Microchip Technology | Gate Drivers 8 SOIC 3.90mm(.150in) T/R | SMD | SOIC-8 | 1
16 | IC11,IC12 | LM1117MPX-ADJNOPB | onsemi | LDO Voltage Regulators LM ANA SOT223 800MA LDO | SMD | SOT-223-3 | 2
17 | IC2,IC7 | 74HC4053D,653 | Nexperia | Multiplexer Switch ICs Triple 2-channel analog multiplexer/demultiplexer | SMD | SOIC-16 | 2
18 | IC1,IC4 | NE555DR | Texas Instruments | Timers & Support Products Precision A 595-NE555D | SMD | SOIC-8 | 2
19 | IC3,IC5,IC6 | LM358MX/NOPB | Texas Instruments | Operational Amplifiers - Op Amps LOW PWR DUAL OP AMP A 926-LM358M/NOPB | SMD | SOIC-8 | 3
20 | IC8 | SE555DRG4 | Texas Instruments | Timers & Support Products Prec Timer ALT 595-SE555DR | SMD | SOIC-8 | 1
21 | IC9 | AS7805ADTR-G1 | Diodes Incorporated | Linear Voltage Regulators 1A 3-Term POS Reg Output 1A | SMD | TO-252-2 | 1
22 | Q1,Q2,Q3,Q6,Q7,Q8,Q9 | IRFR3410TRPBF | Infineon Technologies | MOSFETs 100V SINGLE N-CH 39mOhms 37nC | SMD | TO-252-3 | 7
23 | Q5 | IPD60R180P7SAUMA1 | Infineon Technologies | MOSFETs CONSUMER | SMD | TO-252-3 | 1
24 | R10,R9,R56,R55,R6,R2,R26,R5,R8,R54,R100,R4,R82 | RC0805FR-07100KL | YAGEO | Thick Film Resistors - SMD 100 kOhms 125 mW 0805 1% | SMD | R0805_334 | 13
25 | R103,R12 | RC0805FR-13120RL | YAGEO | Thick Film Resistors - SMD 120Ohms 1/8W 0805 1% | SMD | R0805_334 | 2
26 | R13,R14,R15,R31,R47,R53,R87,R99,R106 | RC0805FR-0710RL | YAGEO | Thick Film Resistors - SMD 10 Ohms 125 mW 0805 1% | SMD | R0805_334 | 9
27 | R23,R24,R25,R35,R38,R40,R57,R61,R63,R68,R71,R73,R90,R95,R96,R97 | RC0805FR-071KL | YAGEO | Thick Film Resistors - SMD 1 kOhms 125 mW 0805 1% | SMD | R0805_334 | 16
28 | R16,R18,R19,R20,R27,R29,R32,R36,R43,R45,R48,R58,R65,R69,R76,R78,R79 | RC0805FR-0710KL | YAGEO | Thick Film Resistors - SMD 10 kOhms 125 mW 0805 1% | SMD | R0805_334 | 17
29 | R3,R39,R62,R72 | RC0805FR-071ML | YAGEO | Thick Film Resistors - SMD 1 MOhms 125 mW 0805 1% | SMD | R0805_334 | 4
30 | R66,R67,R77 | RL1206FR-070R1L | YAGEO | Current Sense Resistors - SMD 100 mOhms 250mW 1 % 600 ppm/C | SMD | R1206_334 | 3
31 | R1,R7,R11,R21,R22,R33,R37,R49,R59,R70,R102 | RC0805FR-074K7L | YAGEO | Thick Film Resistors - SMD 4.7 kOhms 125 mW 0805 1% | SMD | R0805_334 | 11
32 | R83 | RC0805FR-07100RL | YAGEO | Thick Film Resistors - SMD 100 Ohms 125 mW 0805 1% | SMD | R0805_334 | 1
33 | R84 | RC0805JR-7W15KL | YAGEO | Thick Film Resistors - SMD 15kOhms 1/8W 0805 5% | SMD | R0805_334 | 1
34 | R89 | RC0805FR-073KL | YAGEO | Thick Film Resistors - SMD 3 kOhms 125 mW 0805 1% | SMD | R0805_334 | 1
35 | R91 | RC0805FR-0718K2L | YAGEO | Thick Film Resistors - SMD 18.2 kOhms 125 mW 0805 1% | SMD | R0805_334 | 1
36 | R94,R92,R30,R98,R28,R46,R101,R93,R44 | RC0805FR-07330RL | YAGEO | Thick Film Resistors - SMD 330 Ohms 125 mW 0805 1% | SMD | R0805_334 | 9
37 | T3,T1,T2,T4 | BC847C,215 | Nexperia | Bipolar Transistors - BJT 45 V, 100 mA NPN general-purpose transistors | SMD | SOT23_3 | 4
38 | T5,T6 | MJD128T4G | onsemi | Darlington Transistors BIP PNP 8A 120V TR | SMD | TO-252-3 | 2
39 | T7,T8,T9 | MJD200G | onsemi | Bipolar Transistors - BJT 5A 25V 12.5W NPN | SMD | TO-252-3 | 3
40 | U$2 | LM2577SX-ADJ/NOPB | Texas Instruments | Switching Voltage Regulators Step-Up Vtg Reg A 926-LM2577S-ADJ/NOPB | SMD | TO-263-5 | 1
41 | U2 | ATMEGA2560-16AU | Microchip Technology | AVR AVR® ATmega Mikrocontroller IC 8-Bit 16MHz 256KB (128K x 16) FLASH 100-TQFP (14x14) | SMD | TQFP-100 | 1
42 | U4 | TXB0108PWR | Texas Instruments | Translation - Voltage Levels 8-Bit Bi-directional V-Level Translator A 595-TXB0108PWRG4 | SMD | TSSOP-20 | 1
43 | L1 | 74477020 | Wurth Electronic | Power Inductors - SMD WE-PD 100uH 2.2A DCR=220mOhms AEC-Q200 | surface mount | WE-CHSA_1212_14076700 | 1
44 | L2 | 744770222 | Wurth Electronic | Power Inductors - SMD WE-PD 220uH 1.3A DCR=390mOhms AEC-Q200 | surface mount | WE-CHSA_1212_14076700 | 1

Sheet: status led board
ID | Designator | Manufacturer No | Manufacturer | Description | Termination Style | Footprint | Qty.
1 | LED1, LED2, LED3 | APT2012SGC | Kingbright | LED green | SMD | CHIP-LED0805 | 3
2 | LED4, LED5, LED6, LED8, LED9, LED10 | APT2012SURCK | Kingbright | LED red | SMD | CHIP-LED0805 | 6
3 | LED7, LED11 | APT2012SYCK | Kingbright | LED yellow | SMD | CHIP-LED0805 | 3
4 | SV1 | Y2514-6002-SH 14P ST HDR 0.112 GF | 3M |  | Through Hole | ML14_149 | 1

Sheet: UV led boards
UV led board 265 nm
ID | Designator | Manufacturer No | Manufacturer | Seller | Description | Termination Style | Footprint | Qty.
1 | R1206 | ERJ-8BQF4R3V | Panasonic | Mouser, Digikey | Current Sense Resistors - SMD 1206 4.3ohm 1% Curr Sense AEC-Q200 | SMD |  | 4
2 | UV-LED | PKC-H10-F35 | Photon Wave | Lasercomponents | UVC-LED, 265nm +/-5nm, typ. 18mW, SMD3535 | SMD3535 |  | 4
UV led board 365 nm
ID | Designator | Manufacturer No | Manufacturer | Seller | Description | Termination Style | Footprint | Qty.
1 | R1206 | CRM1206-FX-20R0ELF | Bourns | Mouser, Digikey | Current Sense Resistors - SMD CHIP RESISTOR Low Value | SMD |  | 4
2 | UV-LED | IN-C33CTNU2 | Inolux | Digikey | Ultraviolet (UV) Emitter 365nm ~ 370nm 3.5V 1A 120° 1414 (3535 Metric) | SMD3535 |  | 4

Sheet: plugs and cables
Plugs and cables
ID | Designator | Manufacturer No | Manufacturer | Description | Qty.
1 | jumper 2x3, motor driver ports | 69145-206LF | Amphenol FCI | 6 (2 x 3) Position Shunt Connector Black Open Top 0.100" (2.54mm) Gold or Gold, GXT™ | 5
2 | jumper 2x4, ISP to Pi | 69145-108LF | Amphenol FCI | 8 (2 x 4) Position Shunt Connector Black Open Top 0.100" (2.54mm) Gold or Gold, GXT™ | 1
3 | Raspberry Pi GPIO cable | IDSD-20-D-02.00 | Samtec | 40 Position Cable Assembly Rectangular Socket to Socket 0.167' (50.80mm, 2.00") | 1
4 | cable status LED board | IDSS-14-D-05.00 | Samtec | 14 Position Cable Assembly Rectangular Socket to Socket | 1
5 | plug external port | TJ0451560000G | Amphenol Anytek | 4 Position Terminal Block Plug, Female Sockets 0.200" (5.08mm) 180° Free Hanging (In-Line) | 1
6 | plug plate holder power | 1803604 | Phoenix Contact | 5 Position Terminal Block Plug, Female Sockets 0.150" (3.81mm) 180° Free Hanging (In-Line) | 1
7 | plug LED's power | 1803620 | Phoenix Contact | 7 Position Terminal Block Plug, Female Sockets 0.150" (3.81mm) 180° Free Hanging (In-Line) | 1
8 | plug micro pump, 3-way valve, dispensing valve, case light, nebulizer | 1803578 | Phoenix Contact | 2 Position Terminal Block Plug, Female Sockets 0.150" (3.81mm) 180° Free Hanging (In-Line) | 5
9 | plug mini-incubator | 1840405 | Phoenix Contact | 6 Position Terminal Block Plug, Female Sockets 0.138" (3.50mm) 180° Free Hanging (In-Line) | 1

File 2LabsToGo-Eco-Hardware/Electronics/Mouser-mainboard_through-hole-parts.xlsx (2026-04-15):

SHOPPING BASKET
This is not an invoice
02-Jun-25 07:16:33
 | Mouser No | Mfr. No | Manufacturer | Customer No | Description | RoHS | Lifecycle | Order Qty. | Price (EUR) | Ext.: (EUR)
1 | 667-EEU-FR1V471L | EEU-FR1V471L | Panasonic |  | Aluminium Electrolytic Capacitors - Radial Leaded 35VDC 470uF 8x20mm LS5mm | RoHS Compliant |  | 3 | 0,684 € | 2,05 €
2 | 709-NID65-5 | NID65-5 | MEAN WELL |  | Non-Isolated DC/DC Converters 32.5W 24Vin 5Vout Non-Iso Reg SIP | RoHS Compliant |  | 1 | 12,42 € | 12,42 €
3 | 651-1876301 | 1876301 | Phoenix Contact |  | Pluggable Terminal Blocks 6 Pos 3.5mm pitch Through Hole Header | RoHS Compliant |  | 2 | 2,22 € | 4,44 €
4 | 806-KPJX-4S-S | KPJX-4S-S | Kycon |  | DC Power Connectors 4P JACK SKT SHIELDED SNAP AND LOCK | RoHS Compliant |  | 1 | 2,22 € | 2,22 €
5 | 490-PJ-082BH | PJ-082BH | Same Sky |  | DC Power Connectors 2.5mm x 5.5mm horz | RoHS Compliant |  | 1 | 1,69 € | 1,69 €
6 | 517-2540-600240ST112 | Y2540-6002-SH 40P ST HDR 0.112 GF | 3M |  | Headers & Wire Housings 3M Four-Wall Header 2500 Series, 40 Pin Straight Header, 0.112 Tail Length, Gold Flash | RoHS Compliant | New Product | 1 | 2,31 € | 2,31 €
7 | 710-74477020 | 74477020 | Wurth Elektronik |  | Power Inductors - SMD WE-PD 100uH 2.2A DCR=220mOhms AEC-Q200 | RoHS Compliant |  | 1 | 1,91 € | 1,91 €
8 | 710-744770222 | 744770222 | Wurth Elektronik |  | Power Inductors - SMD WE-PD 220uH 1.3A DCR=390mOhms AEC-Q200 | RoHS Compliant |  | 2 | 2,20 € | 4,40 €
9 | 815-ABL-16-B2 | ABL-16.000MHZ-B2 | ABRACON |  | Crystals Xtal HC-49/US 3.5mm Height 16MHz Tol +/-20ppm Stab +/-50ppm -20°C ~ 70°C 18pF 40 Ohms | RoHS Compliant |  | 1 | 0,304 € | 0,30 €
10 | 652-3296W-1-102LF | 3296W-1-102LF | Bourns |  | Trimmer Resistors - Through Hole 3/8" 1Kohms Sealed Vertical Adjust | RoHS Compliant By Exemption |  | 1 | 1,95 € | 1,95 €
11 | 652-3296W-1-504LF | 3296W-1-504LF | Bourns |  | Trimmer Resistors - Through Hole 3/8" 500Kohms Sealed Vertical Adjust | RoHS Compliant By Exemption |  | 2 | 1,95 € | 3,90 €
12 | 652-3296W-1-204LF | 3296W-1-204LF | Bourns |  | Trimmer Resistors - Through Hole 3/8" 200Kohms Sealed Vertical Adjust | RoHS Compliant By Exemption |  | 3 | 1,95 € | 5,85 €
13 | 652-3296W-1-501LF | 3296W-1-501LF | Bourns |  | Trimmer Resistors - Through Hole 3/8IN 500 OHM Sealed Vertical Adjust | RoHS Compliant |  | 1 | 1,95 € | 1,95 €
14 | 652-3296W-1-104ALF | 3296W-1-104ALF | Bourns |  | Trimmer Resistors - Through Hole 3/8" 100Kohms Sealed Vertical Adjust | RoHS Compliant By Exemption |  | 1 | 3,11 € | 3,11 €
15 | 517-2514-600214ST112 | Y2514-6002-SH 14P ST HDR 0.112 GF | 3M |  | Headers & Wire Housings 3M Four-Wall Header 2500 Series, 14 Pin Straight Header, 0.112 Tail Length, Gold Flash | RoHS Compliant | New Product | 1 | 1,25 € | 1,25 €
16 | 650-1825910-6 | 1825910-6 | TE Connectivity |  | Tactile Switches FSM4JH=6MM TACT SWITCH, HIGH TEMP | RoHS Compliant By Exemption | New At Mouser | 1 | 0,124 € | 0,12 €
17 | 571-5355416 | 535541-6 | TE Connectivity |  | Headers & Wire Housings VERT RECPT 8 POS | No |  | 10 | 1,42 € | 14,20 €
18 | 651-1757268 | 1757268 | Phoenix Contact |  | Pluggable Terminal Blocks 4 Pos 5.08mm pitch Through Hole Header | RoHS Compliant |  | 1 | 1,20 € | 1,20 €
19 | 651-1803426 | 1803426 | Phoenix Contact |  | Pluggable Terminal Blocks 2 Pos 3.81mm pitch Through Hole Header | RoHS Compliant |  | 5 | 0,713 € | 3,57 €
20 | 651-1803455 | 1803455 | Phoenix Contact |  | Pluggable Terminal Blocks 5 Pos 3.81mm pitch Through Hole Header | RoHS Compliant |  | 1 | 1,91 € | 1,91 €
21 | 651-1803471 | 1803471 | Phoenix Contact |  | Pluggable Terminal Blocks 7 Pos 3.81mm pitch Through Hole Header | RoHS Compliant |  | 1 | 2,57 € | 2,57 €
22 | 649-87520-0010BLF | 87520-0010BLF | Amphenol |  | USB Connectors USB S/D RECEPT | RoHS Compliant |  | 1 | 0,941 € | 0,94 €
23 | 649-68002-420HLF | 68002-420HLF | Amphenol |  | Headers & Wire Housings 20P SR UNSHRD HRD TIN OVER NI | RoHS Compliant |  | 3 | 0,922 € | 2,77 €
24 | 649-67996-408HLF | 67996-408HLF | Amphenol |  | Headers & Wire Housings 8P DR UNSHRD HRD TIN OVER NI | RoHS Compliant |  | 1 | 0,295 € | 0,30 €
25 | 649-67996-410HLF | 67996-410HLF | Amphenol |  | Headers & Wire Housings 10P DR UNSHRD HRD TIN OVER NI | RoHS Compliant |  | 1 | 1,25 € | 1,25 €
26 | 649-67996-420HLF | 67996-420HLF | Amphenol |  | Headers & Wire Housings 20P DR UNSHRD HRD TIN OVER NI | RoHS Compliant |  | 1 | 0,675 € | 0,68 €
27 | 649-67996-412HLF | 67996-412HLF | Amphenol |  | Headers & Wire Housings 12P DR UNSHRD HRD TIN OVER NI | RoHS Compliant |  | 1 | 0,295 € | 0,30 €
By submitting your order you agree to these terms and conditions. (https://www.mouser.de/saleterms) |  |  |  |  |  |  |  |  | Merchandise: | 79,56 €
Prices are reflected at the date and time shown. |  |  |  |  |  |  |  |  | Delivery Charge: | 0,00 €
 |  |  |  |  |  |  |  |  | Back-order Delivery: | 0,00 €

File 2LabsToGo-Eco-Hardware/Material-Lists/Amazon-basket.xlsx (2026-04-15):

Amazon products
 | Amazon Product No. | Quantity | Unit price | Net
Nema16 Linear Stepper Motor 16HSL3404 12 V 0.01 Step 100 mm |  | 2 | 14.44 | 28.88
https://www.amazon.de/gp/product/B072JGWTG6/ref=ppx_yo_dt_b_asin_title_o01_s00?ie=UTF8&psc=1 | B072JGWTG6
UPERFECT Portable Monitor, 15.6 Inch Portable Monitor Display 1920 x 1080P Full HD |  | 1 | 126.04 | 126.04
https://www.amazon.de/gp/product/B09P143FD6/ref=ppx_yo_dt_b_asin_title_o02_s03?ie=UTF8&psc=1 | B09P143FD6
Logitech MK220 Wireless Keyboard and Mouse set |  | 1 | 21.46 | 21.46
https://www.amazon.de/gp/product/B006YYNGNY/ref=ppx_yo_dt_b_asin_title_o01_s00?ie=UTF8&psc=1 | B006YYNGNY
SBS® Neodymium Magnets, Pack of 20, Super Magnets with Extreme Hold Disc Magnet 8 x 3 mm |  | 1 | 4.95 | 4.95
https://www.amazon.de/gp/product/B0187JGP1I/ref=ppx_yo_dt_b_asin_title_o02_s02?ie=UTF8&psc=1 | B0187JGP1I
15 x cube magnets, neodymium magnet in 5 mm x 5 mm |  | 1 | 3.78 | 3.78
https://www.amazon.de/gp/product/B005PKWZVW/ref=ppx_yo_dt_b_asin_title_o00_s00?ie=UTF8&psc=1 | B005PKWZVW
3D Printer Mechanical Limit Switch, MakerBot 4 pins, pack of 6, with cables |  | 1 | 5.56 | 5.56
https://www.amazon.de/gp/product/B097436BBZ/ref=ppx_yo_dt_b_asin_title_o02_s01?ie=UTF8&psc=1 | B097436BBZ
3D Printer Optical Limit Switch, pack of 5, with cables |  | 1 | 5.64 | 5.64
https://www.amazon.de/gp/product/B07CQWPLWB/ref=ppx_yo_dt_b_asin_title_o02_s02?ie=UTF8&psc=1 | B07CQWPLWB
60mm bubble spirit level |  | 1 | 7.13 | 7.13
https://www.amazon.de/gp/product/B08882Y16G/ref=ox_sc_act_title_1?smid=A21312XZUBAZON&psc=1 | B08882Y16G
3M 9088 Double-Sided Tape, 6 mm |  | 1 | 5.63 | 5.63
https://www.amazon.de/-/en/Double-Sided-Extra-Sticky-Polyethylene-Terephthalate-Available/dp/B00G6SCZ9Y/ | B00G6SCZ9Y
 |  |  | total | 209.07
 |  |  | incl. VAT | 248.80

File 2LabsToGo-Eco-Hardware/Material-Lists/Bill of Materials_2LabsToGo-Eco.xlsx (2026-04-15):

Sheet: publication
Instuction S2 - Bill of materials
Mechanics1 | Amount | Exemplary seller | Net costs (Euro)
Aluminum Profile 20x20L - 1N - I-Type Groove 5, 270 mm, machining both sides M5 (70502-Z) | 2 | www.dold-mechatronik.de | 7.60
Aluminum Profile 20x20L - 1N - I-Type Groove 5, 215 mm, , machining both sides M5 (70502-Z) | 3 | www.dold-mechatronik.de | 10.44
Aluminum Profile 20x20L - 1N - I-Type Groove 5, 210 mm, , machining both sides M5 (70502-Z) | 2 | www.dold-mechatronik.de | 6.89
Aluminum Profile 20x20L - 2N-90° - I-Type Groove 5, 270 mm, machining both sides M5 (70526-Z) | 2 | www.dold-mechatronik.de | 7.60
Aluminum Profile 20x20L - 2N-90° - I-Type Groove 5, 215 mm, machining both sides M5 (70526-Z) | 2 | www.dold-mechatronik.de | 6.96
Aluminum Profile 20x20L - 2N-90° - I-Type Groove 5, 210 mm, machining both sides M5 (70526-Z) | 4 | www.dold-mechatronik.de | 13.78
Aluminum Profile 20x20L I-Type Groove 5, 270 mm (62002-Z) | 1 | www.dold-mechatronik.de | 1.61
Aluminum Profile 20x20L I-Type Groove 5, 210 mm (62002-Z) | 1 | www.dold-mechatronik.de | 1.30
Corner angle 20 I-type groove 5 and cover square (61395-AE) | 8 | www.dold-mechatronik.de | 33.19
Angle 20 I-type groove 5 (F093W203N05S03) | 2 | www.dold-mechatronik.de | 1.50
Bright steel, round 8mm, 290 mm (C45+SL-h6-D8-Z) | 2 | www.dold-mechatronik.de | 4.74
Bright steel, round 8mm, 205 mm (C45+SL-h6-D8-Z) | 2 | www.dold-mechatronik.de | 3.60
Bright steel round 6mm, 97 mm (C45+SL-h6-D6-Z) | 1 | www.dold-mechatronik.de | 1.08
Bright steel round 6mm, 93 mm (C45+SL-h6-D6-Z) | 2 | www.dold-mechatronik.de | 2.08
drylin® R Slide bearings without housing RJ4JP-01-08 / d1 = 8 / d2 = 15 / B = 24 (RJ4JP-01-08) | 4 | www.dold-mechatronik.de | 11.73

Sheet: workshop
Parts | Amount | Exemplary seller | Euro (+VAT)
Mechanics
Project 2LabsToGo (aluminum profiles, connectors, bearings, rods, screws and nuts, screwing tools) | 1 | dold-mechatronik.de/ | 221.04
Parts for movements
Pololu Stepper Motor Nema 14 Bipolar 200 Steps/Rev 35x36mm 2.7V 1A/Phase (Pololu No. 1209) | 2 | www.pololu.com, www.exp-tech.de/en | 50.82
Stepper motor driver Stepsticks A4988, black edition (Pololu No. 2981) | 4 | www.pololu.com, www.exp-tech.de/en | 62.40
Mechanical endstop boards kit, 39 x 15 mm, 2 needed (pack of 6) | 1 | Amazon | 7.00
Optical endstop boards, 32 x 10 mm, 2 needed (pack of 5) | 1 | Amazon | 7.00
Stepper motor Nema 17 with integrated lead screw (Tr8x8, 300 mm), MK3 stepper motor Z-axis Right | 1 | www.prusa3D.com | 32.68
Trapezoidal leadscrew nut - TR 8x8, POM, Prusa Trapezoid nut (i3, MK4) (1 needed) | 1 | www.prusa3D.com | 5.86
Timing belt 2GT Y-axis MK3S, 650 mm | 1 | www.prusa3D.com | 4.87
Timing belt 2GT X-axis MINI | 1 | www.prusa3D.com | 3.35
Timing pulley T16-2GT | 2 | www.prusa3D.com | 5.18
Linear stepper motor ACT 16HSL3404 (new ACT product number: 39BYGHL) | 2 | act-motor.com or Amazon | 28.87
Magnets, Ø 8 mm x 3 mm, pack of 20 | 1 | Amazon | 6.00
cube magnets, neodymium magnet in 5 mm x 5 mm, paxk of 15 | 1 | Amazon | 3.78
Multifunctional plateholder
aluminum plate, 100 x 95 x 2 mm | 1 | xometry.eu/en/ | 5.90
TRU COMPONENTS Polymide heating foil, 12 V/DC, 48 W, 60 mm x 60 mm | 1 | conrad.de | 7.13
NTC Thermistor, 100 kΩ, DigiKey No. 495-2143-ND | 1 | Digikey | 3.00
screws + nuts (included in Dold project)
Magnets, Ø 8 mm x 3 mm, 4 needed (see Parts for movements)
Cubic magnets, 5 mm x 5 mm x 5 mm, 4 needed (see Parts for movements)
Glass plates 200 mm x 200 mm x 1 mm | 1 | ebay (glasludwig) | 4.20
60mm bubble spirit level | 1 | Amazon | 7.13
Backlight plateholder
Inspired LED 12V-MB-CW-12M, cool white, cut tape, DigiKey No. 1647-12V-MB-CW-12MCT-ND | 8 | Digikey | 2.56
Plexiglas Satinice CLEAR 0D010 DF, 200 x 100 x 3 mm | 1 | www.plexiglas-shop.com | 10.30
Plexiglas LED CLEAR 0E010 SM for edge lighting, 200 x 100 x 4 mm | 1 | www.plexiglas-shop.com | 10.30
Magnets, Ø 8 mm x 3 mm, 4 needed (see parts for movements)
cubic magnets, 5 mm x 5 mm x 5 mm, 4 needed (see parts for movement)
Panels - Alupanel aluminum brushed 3 mm
10.2 cm x 21.0 cm (sides front), upload dxf file | 2 | www.kunststoffplattenonline.de | 10.00
14.8 cm x 21.0 cm (sides back), upload dxf file | 2 | www.kunststoffplattenonline.de | 10.00
21.5 cm x 19.0 cm (back), upload dxf file | 1 | www.kunststoffplattenonline.de | 5.41
10.2 cm x 21.5 cm (top front), upload dxf file | 1 | www.kunststoffplattenonline.de | 5.00
21.5 cm x 19.0 cm (front), upload dxf file | 1 | www.kunststoffplattenonline.de | 5.40
bottom plate, upload dxf file | 1 | www.kunststoffplattenonline.de | 11.76
Raspberry Pi
Raspberry Pi 4 Model B, 4 GB SDRAM (8 or 4 GB??) | 1 | www.rasppishop.de | 56.22
Raspberry Pi 4 heat sinks | 1 | www.rasppishop.de | 3.10
SanDisk Ultra A1 microSD 64GB | 1 | www.rasppishop.de | 9.80
Raspberry Pi HDMI cable, 2 m | 1 | www.rasppishop.de | 8.50
Raspberry Pi 12 MP HQ Camera?? | 1 | www.rasppishop.de | 53.12
Wide Angle Lens for Raspberry Pi HQ Camera?? | 1 | www.rasppishop.de | 25.00
Raspberry Pi Camera Module 3 (option) | 1 | www.rasppishop.de |  | 24.50
Camera cable 500 mm | 1 | www.rasppishop.de | 2.93
UPERFECT Portable Monitor, 15.6 Inch, 5 V | 1 | Amazon | 126.04
Wireless keyboard and mouse, Logitech MK220 | 1 | Amazon | 25.97
Philips screw M2.5x6 (for Raspberry Pi and HQ Camera) | 8 | local workshop/ebay | 2.00 | rc-schrauben!
Philips screw M2x6 (for the optional Model 3 Camera) | 4 | local workshop/ebay |  | rc-schrauben!
Power supply
Power supply, Meanwell GST160A12-R7B, 12 V, 160 W | 1 | https://www.meanwell-web.com | 49.90
Power Cord Black CEE 7/7 To IEC 320-C13, 18 AWG (0.8 mm2), Digikey No. 993-1038-ND | 1 | Digikey | 5.49
Cables
Premium Jumper Wires, 30 cm, black, pack of 10, Pololu item #: 1840 | 2 | www.pololu.com, www.exp-tech.de/en | 3.00
Premium Jumper Wires, 30 cm, blue, pack of 10, Pololu item #: 1846 | 1 | www.pololu.com, www.exp-tech.de/en | 3.00
Premium Jumper Wires, 30 cm, red, pack of 10, Pololu item #: 1842 | 2 | www.pololu.com, www.exp-tech.de/en | 3.00
Premium Jumper Wires, 30 cm, green, pack of 10, Pololu item #: 1845 | 1 | www.pololu.com, www.exp-tech.de/en | 3.00
0.1" (2.54mm) Crimp Connector Housing: 1x12-Pin, pack of 5, Pololu item #: 1919 | 1 | www.pololu.com, www.exp-tech.de/en | 2.45
Fluidics
Force Sensor FX29K0-100A-0010-L | 1 | DigiKey | 40.50
Screw M2x10 DIN 912, stain less steel | 4 | rc-schrauben.de
Screw M2x25 DIN 912, stain less steel | 2 | rc-schrauben.de
Lee components |  |  |  |  |  | x 105%
LFR Series solenoid valve 3-way, FFKM, Manifold Mount ( LFRA1252370D) | 1 | www.theleeco.com/products/ | 213.41 | 213.41 | 213.41 | 224.0805
062 Female MINSTAC – Female Luer Lock Adapter, PEEK ( TMDA3203950Z) | 1 | www.theleeco.com/products/ | 18.05 | 18.05 | 18.05 | 18.9525
125/156 Female MINSTAC – Male Luer Lock Adapter, PEEK (TMRA9503950Z) | 1 | www.theleeco.com/products/ | 21.30 | 21.3 | 21.3 | 22.365
Safety Screen - 062 MINSTAC, 12 µm, PEEK ( INMX0350000A) | 4 | www.theleeco.com/products/ | 181.44 | 45.36 | 181.44 | 190.512
Torque Wrench ( TTTA3201243A) | 1 | www.theleeco.com/products/ | 28.03 | 28.03 | 28.03 | 29.4315
VHS Series solenoid valve, FFKM (INKX0514100A) | 1 | www.theleeco.com/products/ | 397.89 | 397.89 | 397.89 | 417.7845
Micropump LPL2, 50 µL, 12V, EPDM ( LPLX0509650B) | 1 | www.theleeco.com/products/ | 159.44 | 159.44 | 159.44 | 167.412
062 Female MINSTAC – Female Luer Lock Adapter, PEEK ( TMRA3202950Z) | 2 | www.theleeco.com/products/ | 36.10 | 18.05 | 36.1 | 37.905
062 Male MINSTAC – Female Luer Lock Adapter, PEEK ( TMRA3201950Z) | 1 | www.theleeco.com/products/ | 18.05 | 18.05 | 18.05 | 18.9525
062 MINSTAC nozzle with jeweled orifice, orifice ID 0.002" (0.05 mm) (INZA4620928T) | 1 | www.theleeco.com/products/ | 45.87 | 45.87 | 45.87 | 48.1635
062 MINSTAC nozzle with jeweled orifice, orifice ID 0.003" (0.08 mm) (INZA4630912T) | 1 | www.theleeco.com/products/ | 45.87 | 45.87 | 45.87 | 48.1635
062 MINSTAC airless atomizing nozzle (IAZA1200167K) | 1 | www.theleeco.com/products/ | 57.28 | 57.28 | 57.28 | 60.144
PTFE tubing, 2 fittings 062 MINSTAC, ID 0.8 mm, L 20 cm (TUTC3216920L) | 1 | www.theleeco.com/products/ | 32.86 | 32.86 | 32.86 | 34.503
PTFE tubing, 2 fittings 062 MINSTAC, ID 0.8 mm, L 15 cm (TUTC3216915L) | 3 | www.theleeco.com/products/ | 97.71 | 32.57 | 97.71 | 102.5955
Hotend PTFE tube | 1 | www.prusa3D.com | 2.58
Timing pulley T16-2GT | 2 | www.prusa3D.com | 6.16
Timing belt 2GT, MK3 X-axis, 850 mm | 1 | www.prusa3D.com | 5.80
Timing belt 2GT, MINI X-axis, 650 mm | 1 | www.prusa3D.com | 5.80
LED illumination
PCB for UV 265 nm LEDs (see Eagle files) | 2 | ibr-leiterplatten.de | 6.40
PCB for UV 365 nm LEDs (see Eagle files) | 2 | ibr-leiterplatten.de | 8.00
UV 265 nm LED PKC-H10-F35, 18 mW, SMD3535 | 4 | www.lasercomponents.com/de-en/ | 13.28
UV 365 nm LED, Inolux IN-C33CTNU2, SMD3535 | 4 | Digikey | 25.48
NeoPixel Stick - 8 x 5050 RGBW LEDs - Cool White, DigiKey No. 1528-1595-ND | 2 | DigiKey | 15.08
Screw M2x10 DIN 912, stain less steel (Neopixel) | 4 | local workshop/ebay/rc-schrauben.de
Hebo-Filter
Hebo-Filter
Inspired LED 12V-MB-CW-12M, cool white, cut tape, DigiKey No. 1647-12V-MB-CW-12MCT-ND | 8 | Digikey | 2.56 | case light
Electronics
Electronic board (see Eagle file) | 1 | Elektronik Werkstatt JLU | 300.00
DHT22 AM2302 Temperature and humidity sensor | 1 | az-delivery.de/en | 6.71
6 (2 x 3) Position Shunt Connector Black Open Top 0.100" (2.54mm) Gold | 5 | Digikey | 4.50
8 (2 x 4) Position Shunt Connector Black Open Top 0.100" (2.54mm) Gold | 1 | Digikey | 1.22
Motor driver heatsinks | 5 | Amazon | 1.50
Mini-Incubator
Aluminum plates, 110 x 110 x 2 mm | 2 | xometry.eu/en/ | 4.72
Thermo TECH Polyester Heating foil self-adhesive, 12 V/DC, 12 V/AC, 15 W, Ø 90 mm | 2 | www.conrad.de | 30.24
NTC Thermistor, 100 kΩ, DigiKey No. 495-2143-ND | 1 | Digikey | 2.61
DHT22 AM2302 Temperature and humidity sensor | 1 | az-delivery.de/en | 6.71
7 Leiter Mehrleiter Kabel Schwarz 22 AWG 3,28' (1,00m), DigiKey No. T1422-1-ND | 1 | Digikey | 4.71
6-Position terminal block plug, pitch 0.138" (3.50 mm), Plug Wire Entry 180°, DigiKey No. WM7736-ND | 1 | Digikey | 2.26
JST XH crimp socket, DigiKey No. 455-1135-1-ND | 3 | Digikey | 0.27
JST XHP-4 female socket, DigiKey No. 455-2268-ND | 1 | Digikey | 0.10
Through connector max. 4 mm², 2 conductors (Reichelt No. WAGO 221-2411) | 2 | www.reichelt.de | 0.94
 |  |  | 52.56
Nebulizer
Glass plate 200 mm x 100 mm x 1 mm | 1 | used HPTLC plate
Ultrasonic Piezo Atomizer 16 mm 108 kHz 5 µm pore size | 50 | piezoelements.com1) | 130 | MOQ of 50
Ultrasonic Piezo Atomizer 16 mm 108 kHz 11 µm pore size | 50 | piezoelements.com1) | 130
JST PH 2 Pin cable male header 2, DigiKey-No. 1528-2617-ND | 1 | DigiKey | 0.69
 |  |  | 260.69
3D Print
Filaments |  |  | 124.00
Print service |  |  | 540.00
 |  | Total | 4008.85
 |  |  | 4770.53 | incl. Tax
Options
Mini-Shaker |  |  |  |  |  | Teilnehmer
Modelcraft gear motor RB350050-0A101R, 12 V 1:50, 120 rpm (Conrad No. 227552) | 1 | conrad.de | 17.64
TRU COMPONENTS 1587515 rocker switch TC-R13-66A-02 (Conrad No. 857475210) | 1 | conrad.de | 0.39
DC Chassis Mount Socket, 5.5/2.5 mm (Digikey No. CP-6-ND) | 1 | Digikey | 1.67
Screw M3x8, DIN 7984 | 15 | dold-mechatronik.de/ local workshop | 2.65 | genug da aus Dold-Paket? |  | Nein!
Screw M3x10, DIN 7984 | 14 | dold-mechatronik.de / local workshop | 2.47 | genug da aus Dold-Paket? |  | Nein!
Screw M3x16, DIN 7984 | 4 | dold-mechatronik.de / local workshop | 1.11 | genug da aus Dold-Paket? |  | Nein!
Nut M3 | 6 | dold-mechatronik.de / local workshop | 0.48
Ball bearings 8 mm x 22 mm x 7 mm, pack of 10 (Amazon No. B07XHTFJ3V), 5 needed | 1 | amazon.de | 6.55
Extension spring, 50 mm => 200 mm (Sodemann No. E02400182000S) | 2 | sodemann-federn.de | 11.40
3M Self-adhesive device foot (Ø x H) 8 mm x 2.8 mm, Conrad No. 525731 | 4 | conrad.de | 0.72
Heatable hood
Thermo TECH Polyester Heizfolie selbstklebend 12 V/DC, 12 V/AC 15 W Schutzart IPX4 (Ø) 90 mm (Conrad No. 189177 ) | 1 | www.conrad.de | 15.12
DEBO XH-W1209 T Developer Boards - Thermostat, 12 V, digital, W1209 | 1 | www.reichelt.de | 3.15
ONPIRA Power distributor, 8 A, 2 x 6 positions (Amazon No. B077BQW5Q5) | 1 | amazon.de | 3.25
SUN EE40101S1-1 Axial fan, 40x40x10 mm, 12V, 13,9m³/h, 28,2dBA | 1 | www.reichelt.de | 1.60
Receptacle, 5 poles female to 22 AWG leads 50 cm (Digikey No. WM21514-ND) | 1 | Digikey | 5.98
5-Pin plug male to 22 AWG wire leads 50 cm (Digikey No. 839-10-04495-ND) | 1 | Digikey | 10.05
Eurostyle terminal strip with screws, 12 positions, 0.5 - 1.5 mm2 | 1 | conrad.de / local workshop | 2.09
 |  | Total | 86.32
 |  |  | 102.72 | incl. Tax
2 Circuit 0.315" (8.00mm) Eurostyle Terminal Strip Connector Screws (Digikey No. ED2995-ND) | 1 |  | 0.77
3 Circuit 0.315" (8.00mm) Eurostyle Terminal Strip Connector Screws Digikey No. ED2996-ND) | 1 |  | 0.90
Parcel for shipping | 1
Attachments
DigiKey basket
Dold basket
Amazon basket
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

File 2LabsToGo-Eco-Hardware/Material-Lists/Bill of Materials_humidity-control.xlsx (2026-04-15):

Parts | Amount | Exemplary seller | Euro (+VAT)
Fan MECHATRONICS MD4028V12B-RSR, 12VDC, 40mm L x 40mm H, 24.3cfm (0.680m³/min) (Digikey No. 1570-1126-ND) | 1 | Digikey | 11.31
Jumper Wire Male to Female 12.00" (304.80mm) 26 AWG, pack of 10, diff. colors (Digikey No. 2183-4567-ND) | 1 | Digikey | 2.81
Plexiglas 215 mm x 190 mm x 3 mm (front_215x190.dxf) | 1 | kunstoffplattenonline.de | 5.00
Round magnets, Ø 8 mm x 3 mm | 10 | supermagnete.de | 4.45
Superglue | 1 | local workshop | 4.90
Screw M3x40 | 4 | local workshop | 0.80
Nut M3 | 4 | local workshop | 0.60
Double-Sided Adhesive Tape tape, 6 mm, 50 cm needed | 1 | local workshop | 6.50
Eurostyle terminal strip with screws, 0.5 - 1.5 mm2 | 1 | local workshop | 2.00
 |  |  | 38.37

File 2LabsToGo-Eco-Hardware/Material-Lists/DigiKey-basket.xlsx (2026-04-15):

Quantity | DigiKey Part number | Manufacturer | Manufacturer part number | Short description | Unit price | Amount | Total price EUR
2 | 495-2143-ND | EPCOS - TDK Electronics | B57861S0104F040V24 | THERM NTC 100KOHM 4540K BEAD | 2.61 | 2 | 5.22 | mini-incubator
16 | 1647-12V-MB-CW-12MCT-ND | Inspired LED, LLC | 12V-MB-CW-12M | LED ENG CW 3LEDS 6000K 12M REEL | 0.33 | 16 | 5.28 | 8 for backlight, 8 for caselight
1 | 223-FX29K0-100A-0010-L-ND | TE Connectivity Measurement Specialties | FX29K0-100A-0010-L | 10LBF COMPRESSION LOAD CELL, I2C | 40.42 | 1 | 40.42
4 | 1830-1187-1-ND | Inolux | IN-C33CTNU2 | TOP VIEW 3535 3.5X3.5X2.0 | 6.36 | 4 | 25.44
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

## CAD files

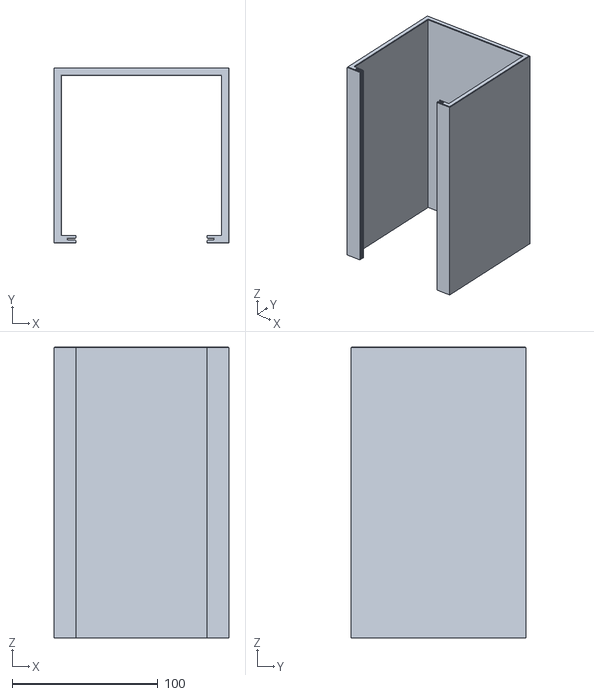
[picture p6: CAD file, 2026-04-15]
2LabsToGo-Eco-Hardware/3D-Parts/STL/nebulizer/nebulizer_chamber_main.stl
120.0 x 120.0 x 200.0

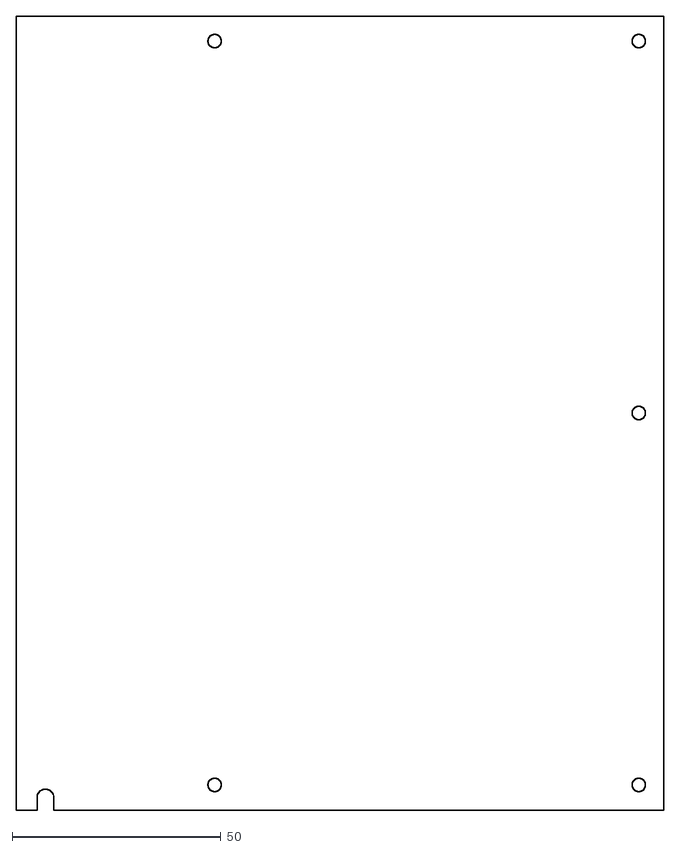
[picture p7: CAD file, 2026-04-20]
2LabsToGo-Eco-Hardware/3D-Parts/DXF-panels/back_humidity-control.dxf
155.0 x 190.0

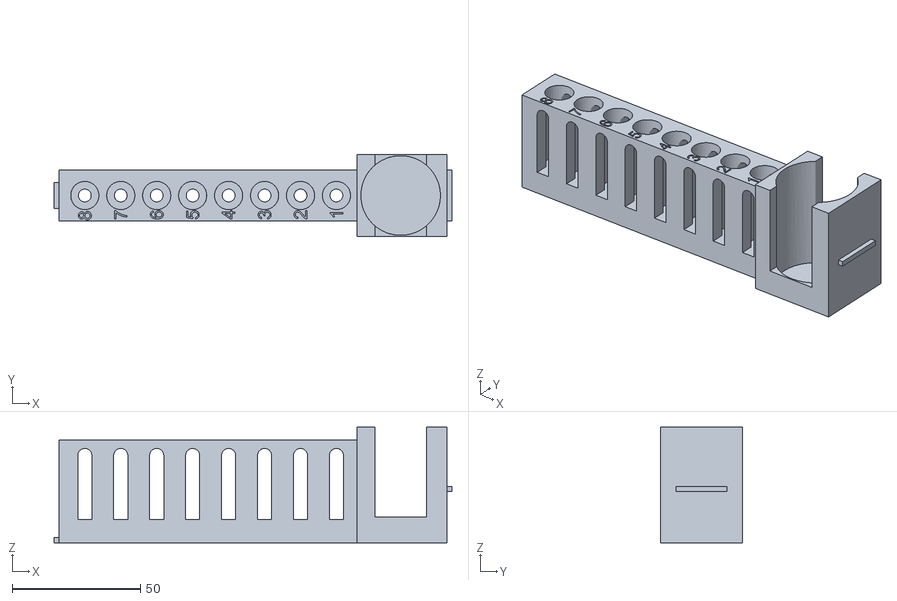
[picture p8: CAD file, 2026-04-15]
2LabsToGo-Eco-Hardware/3D-Parts/STL/autosampler/autosampler_vialrack_ver2.stl
155.0 x 32.0 x 45.0

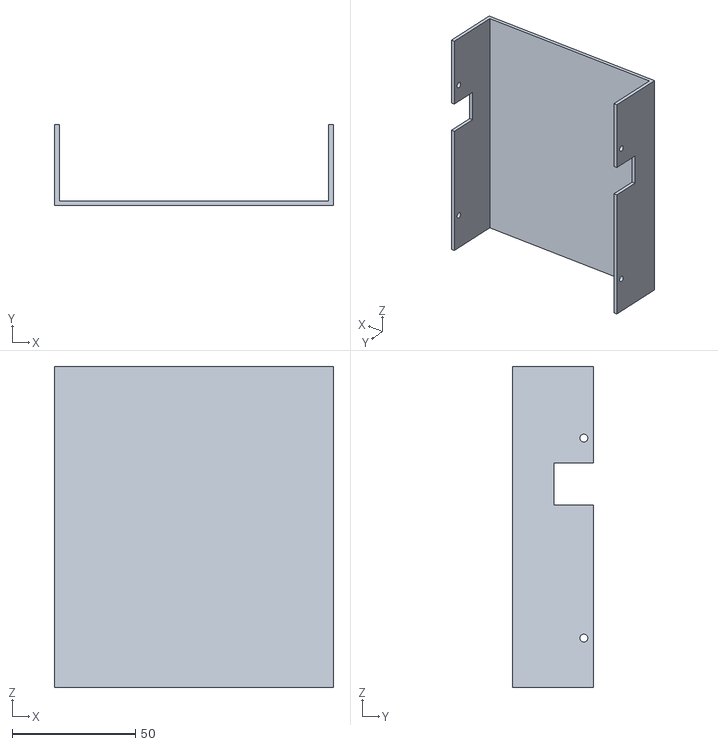
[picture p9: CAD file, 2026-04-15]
2LabsToGo-Eco-Hardware/3D-Parts/STL/camera_cabinet/camera_cabinet_facing.stl
113.0 x 33.0 x 130.0

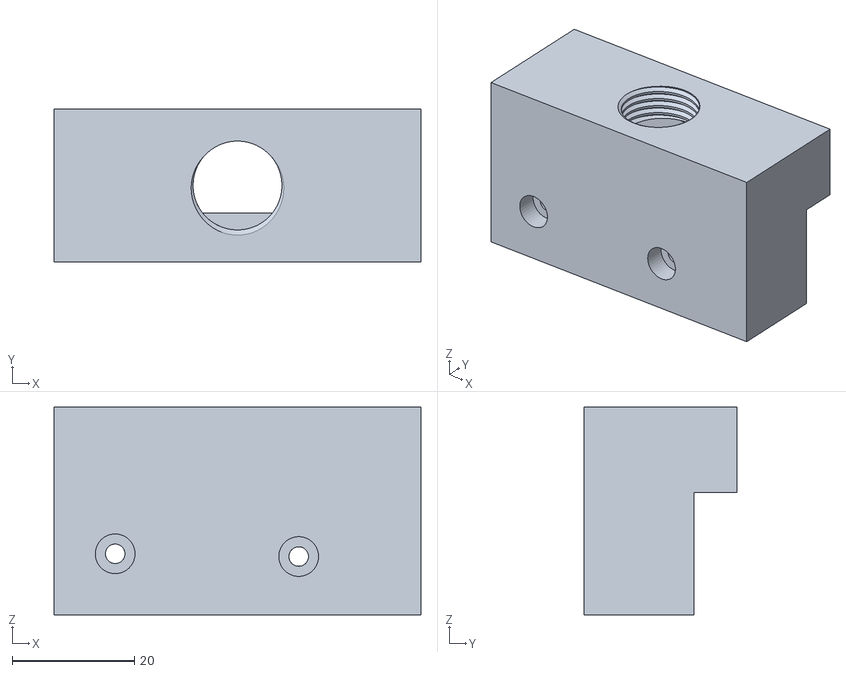
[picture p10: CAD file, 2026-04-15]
2LabsToGo-Eco-Hardware/3D-Parts/STL/DC-power-jacket_housing/Dc-power-jacket-housing.stl
60.0 x 25.0 x 34.0

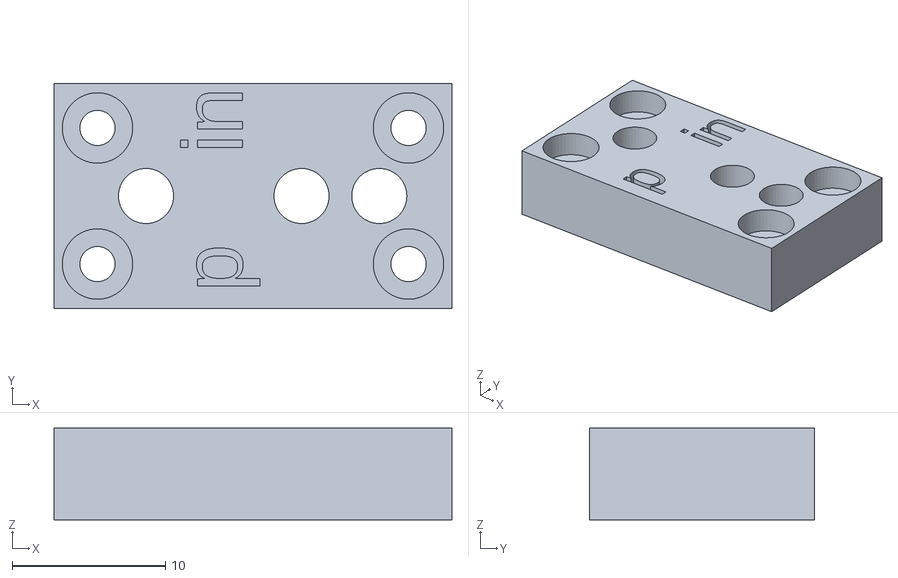
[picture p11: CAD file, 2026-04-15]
2LabsToGo-Eco-Hardware/3D-Parts/STL/e-axis/3way-valve_manifold_drill-aid.stl
26.0 x 14.7 x 6.00

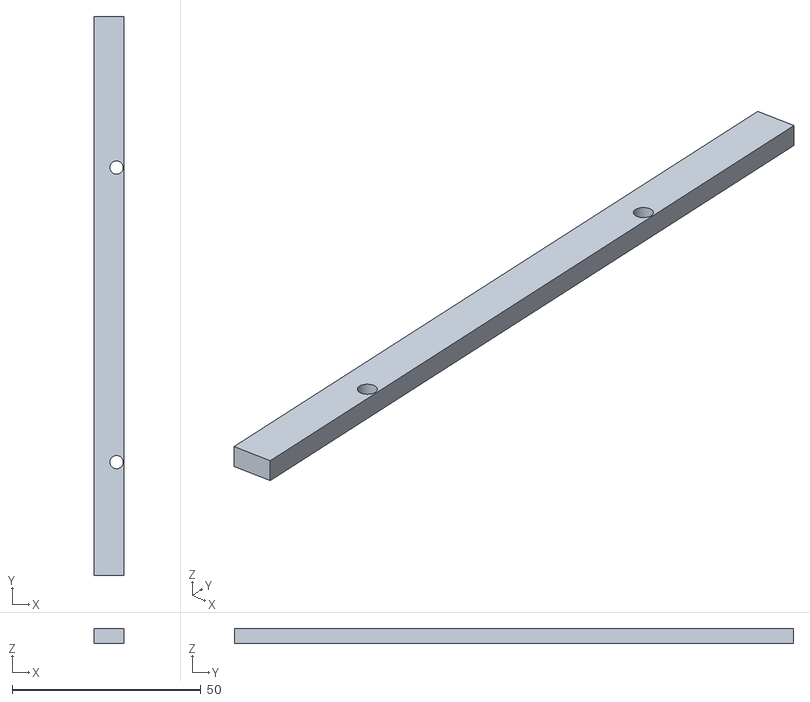
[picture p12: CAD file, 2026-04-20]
2LabsToGo-Eco-Hardware/3D-Parts/STL/electronic-box/electronic_box_frame-part2.stl
8.00 x 148.0 x 4.00

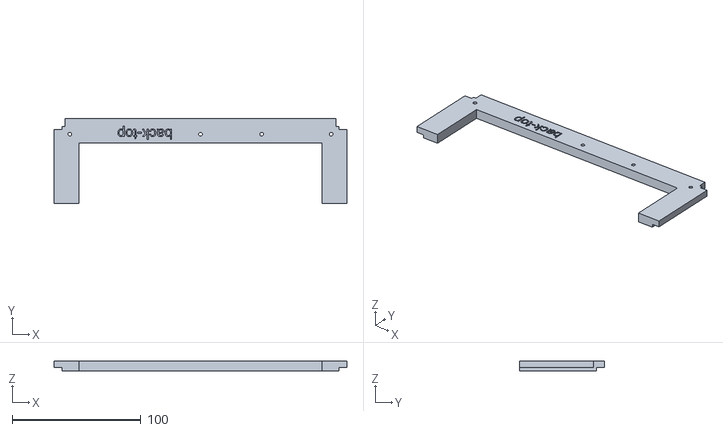
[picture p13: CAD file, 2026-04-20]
2LabsToGo-Eco-Hardware/3D-Parts/STL/frames/frame_back_top.stl
227.6 x 66.3 x 7.50

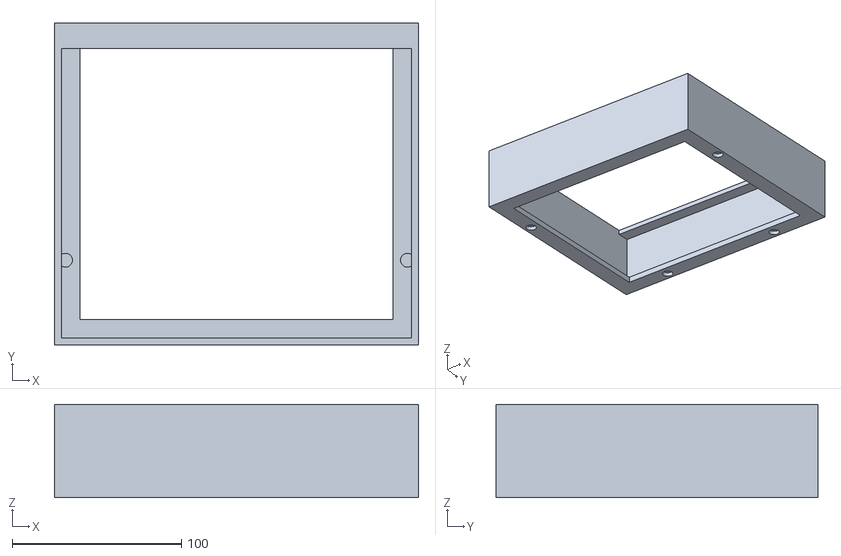
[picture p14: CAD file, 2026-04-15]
2LabsToGo-Eco-Hardware/3D-Parts/STL/humidity-control/front-extension.stl
215.0 x 190.0 x 55.0

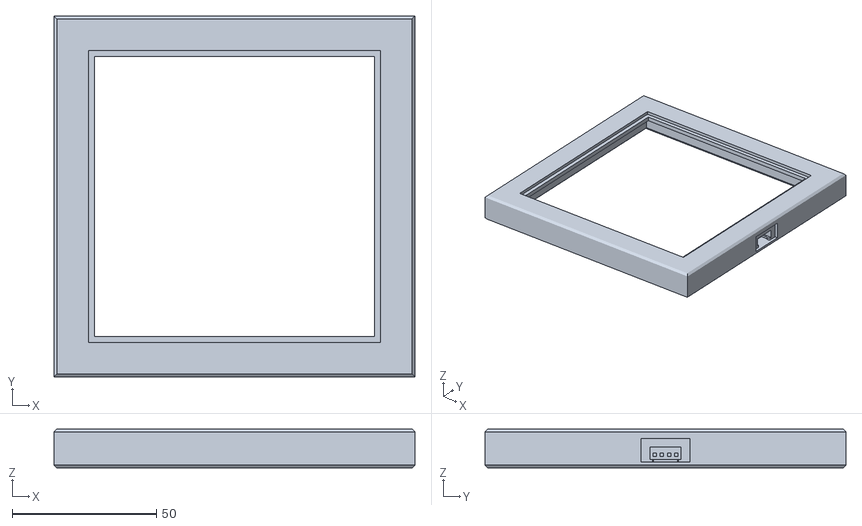
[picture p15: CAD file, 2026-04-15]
2LabsToGo-Eco-Hardware/3D-Parts/STL/mini-incubator/mini-incubator_inner_bottom.stl
125.0 x 125.0 x 13.5

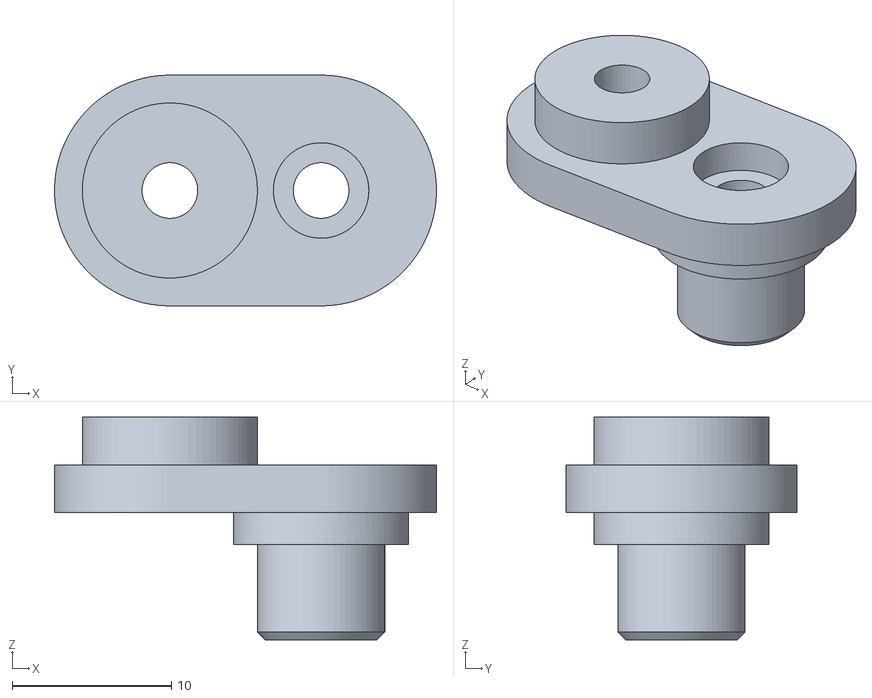
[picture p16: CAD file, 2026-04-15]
2LabsToGo-Eco-Hardware/3D-Parts/STL/mini-shaker/mini-shaker_excenter.stl
24.0 x 14.5 x 14.0

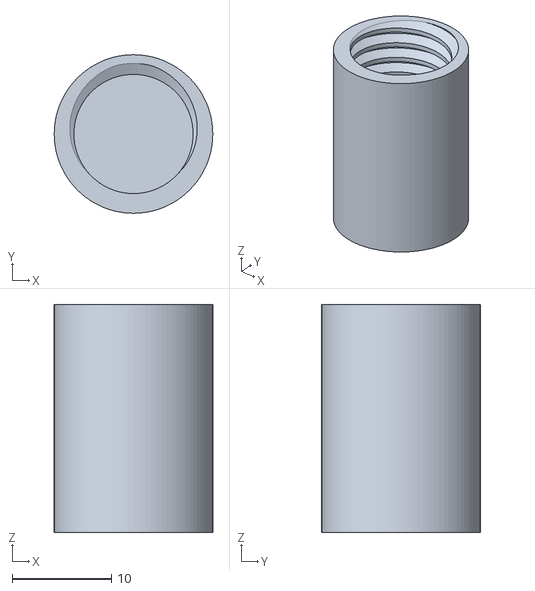
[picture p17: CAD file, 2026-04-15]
2LabsToGo-Eco-Hardware/3D-Parts/STL/panels/leg_outside.stl
16.0 x 16.0 x 23.0

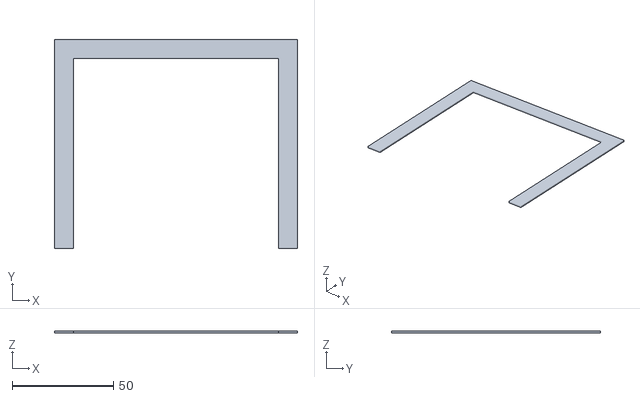
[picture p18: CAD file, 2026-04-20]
2LabsToGo-Eco-Hardware/3D-Parts/STL/plate-holder/multifunctional_plate_holder-cover_development_glass-plate_cover.stl
120.0 x 103.4 x 1.00

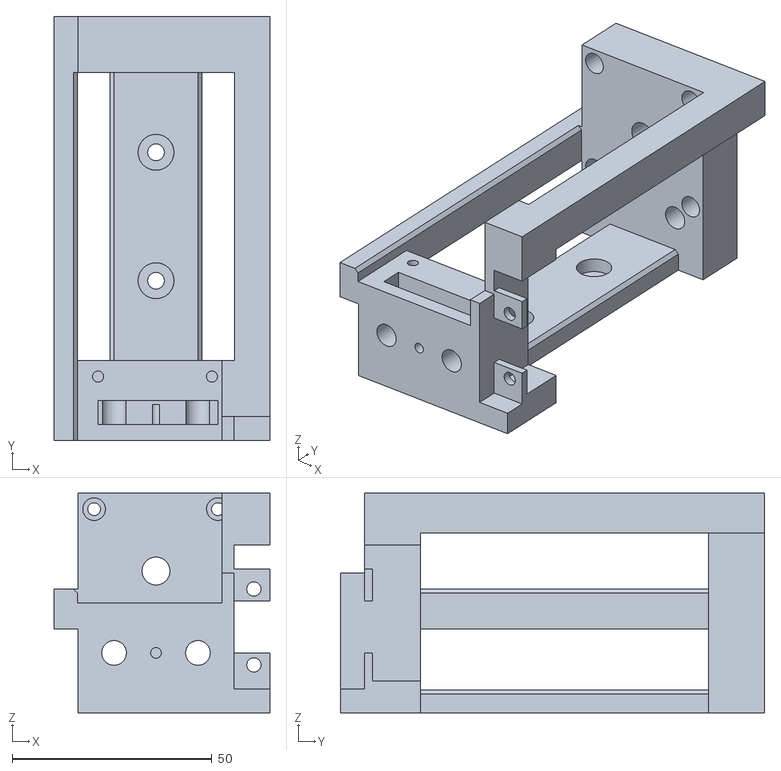
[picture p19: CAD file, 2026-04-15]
2LabsToGo-Eco-Hardware/3D-Parts/STL/syringe-pump/syringe-pump_body.stl
54.0 x 106.2 x 55.0

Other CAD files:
2LabsToGo-Eco-Hardware/3D-Parts/STL/tools/tool_ miniature_ball_ bearings.stl
2LabsToGo-Eco-Hardware/3D-Parts/STL/x-axis/x-axis_cart-tensioner.stl
2LabsToGo-Eco-Hardware/3D-Parts/STL/y-axis/y-axis_tensioner.stl
2LabsToGo-Eco-Hardware/3D-Parts/openSCAD/DC-power-housing/DC-power-jacket-housing_5pin-socket.scad
2LabsToGo-Eco-Hardware/3D-Parts/openSCAD/electronic_box/electronic-box_mainboard.scad
2LabsToGo-Eco-Hardware/3D-Parts/openSCAD/autosampler/motor_holder_mounting_profile.scad
2LabsToGo-Eco-Hardware/3D-Parts/openSCAD/e-axis/e-axis_motor_holder.scad
2LabsToGo-Eco-Hardware/3D-Parts/Aluminum-plates/alu-plate_plate-holder.step
2LabsToGo-Eco-Hardware/3D-Parts/Autodesk Fusion/DC-power-jacket-housing.f3d
2LabsToGo-Eco-Hardware/3D-Parts/Autodesk Fusion/atomizer.f3d
2LabsToGo-Eco-Hardware/3D-Parts/Autodesk Fusion/autosampler.f3d
2LabsToGo-Eco-Hardware/3D-Parts/Autodesk Fusion/e-axis.f3d
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

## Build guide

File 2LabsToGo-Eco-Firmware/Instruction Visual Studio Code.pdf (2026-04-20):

Instruction Visual Studio Code

On the Raspberry Pi, start Visual Studio Code.
Therefore, click the raspberry (top left) and select Programming -> Visual Studio Code

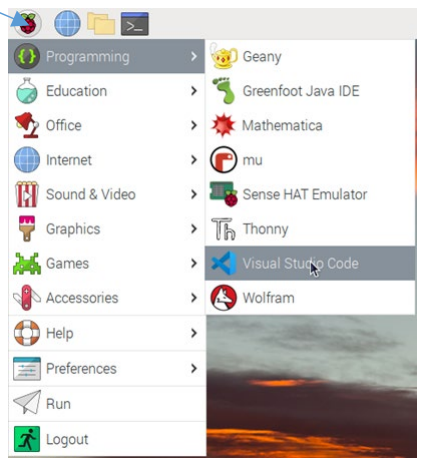
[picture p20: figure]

In Visual Studio Code, install Platformio IDE, if not already done. Click “Extensions”, search for platformio, and install Platformio IDE.

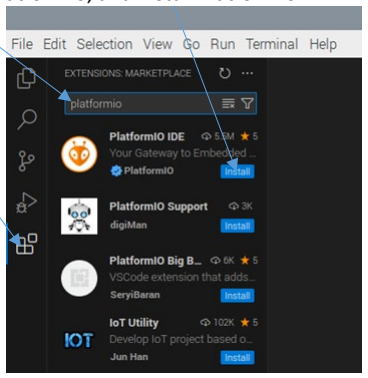
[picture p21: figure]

On the Welcome page, click Open Folder

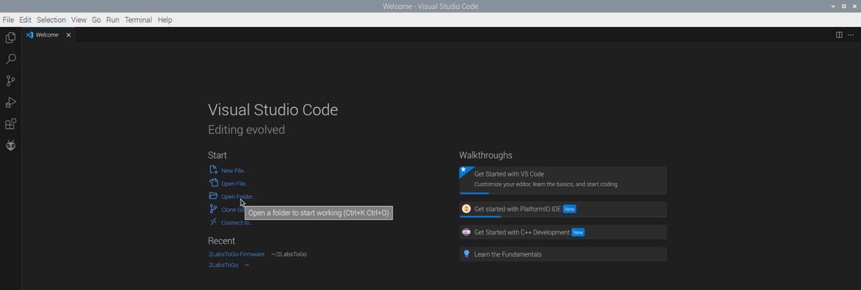
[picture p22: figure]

and select the folder .../2LabsToGo-Eco/2LabsToGo-Eco-Firmware/2LabsToGo-Eco-Marlin.

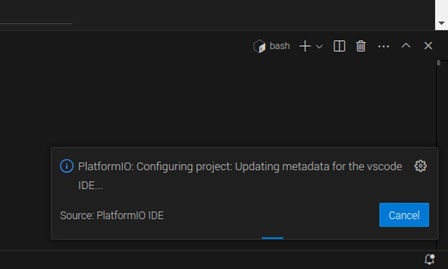
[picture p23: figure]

Wait for finishing the Platformio configuration (bottom right).

Click PlatformIO.

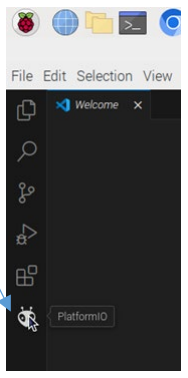
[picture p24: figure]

In the new menu PROJECT TASKS, expand “mega2560” and “General”, and click “Build”.

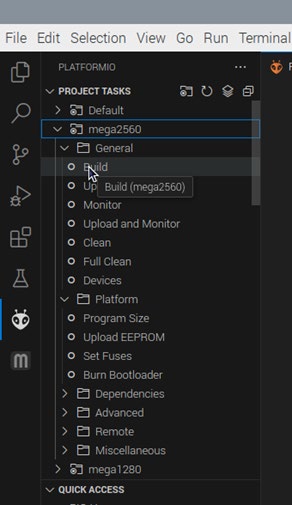
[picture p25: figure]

Building the firmware will start and will take some minutes. The progress can be followed in the terminal and should end with a “Success” message.

The firmware.hex file can be found in …/2LabsToGo-Eco/2LabsToGo-Eco-Firmware/2LabsToGo-Eco-Marlin/.pio/build/mega2560.

Open a new Linux Terminal and copy the firmware.hex file to the folder …/2LabsToGo-Eco/2LabsToGo-Eco-Firmware, while renaming it, for example, to my-firmware.hex:
cd ~/2LabsToGo-Eco/2LabsToGo-Eco-Firmware/2LabsToGo-Eco-Marlin
ls -a [to make the hidden files visible]
sudo cp .pio/build/mega2560/firmware.hex ~/2LabsToGo-Eco/2LabsToGo-Eco-Firmware/my-firmware.hex

Then open the file …/2LabsToGo-Eco-Firmware/flash_firmware.sh with Geany (right click) and correct the firmware filename:
#!/bin/bash

#read -p "Enter your username: " user

#echo "You entered $user"

#sudo avrdude -p atmega2560 -C avrdude_gpio.conf -c 2LabsToGo -v -U lfuse:w:0xff:m -U hfuse:w:0xd8:m -U efuse:w:0xfd:m

sudo avrdude -p atmega2560 -C avrdude_gpio.conf -c 2LabsToGo -v -U lfuse:w:0xff:m -U hfuse:w:0xd8:m -U efuse:w:0xfd:m
#sudo avrdude -p atmega2560 -C avrdude_gpio.conf -c 2LabsToGo -v -U flash:w:ArduinoISP.ino.hex:i

sudo avrdude -p atmega2560 -C avrdude_gpio.conf -c 2LabsToGo -v -U flash:w:ArduinoISP.ino.hex:i
#sudo avrdude -p atmega2560 -C avrdude_gpio.conf -c 2LabsToGo -v -U flash:w:firmware_2LabsToGo-Eco.hex:i sudo avrdude -p atmega2560 -C avrdude_gpio.conf -c 2LabsToGo -v -U flash:w:firmware_2LabsToGo-Eco.hex:i as to my-firmware. Keep the extension “.hex:i”(!) and save the file.

To flash the firmware, place the 4x2 jumper onto the ISP To Pi pins (center of the mainboard).
In the still open Linux Terminal (folder 2LabsToGo-Eco-Marlin), type
sudo chmod +x flash_firmware.sh [to make the file executable, if not done already before] and start flashing with
./flash_firmware.sh

The caselight will be switched off, and the flashing process will take some minutes, ending with the message “Thank you!”.

Remove the 4x2 jumper from the mainboard, when the firmware starts immediately (caselight on and homing the x-axis).

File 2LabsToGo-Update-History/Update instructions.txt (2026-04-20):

Update instructions

1. Firmware update
Follow the instructions under 2LabsToGo-Eco-Firmware/ReadMe

2. Software update
The following instructions assume that the folder 2LabsToGo-Eco is located in the home directory.

2.1. Perform a back-up of the software folder!

2.2. Update procedure
* Disconnect the board (“Connection” tab in browser) and close all tabs.
* Stop the server with “Ctrl+c” in the running terminal.
* In the terminal, change to the 2LabsToGo-Eco directory
	cd ~/2LabsToGo-Eco
[The following commands require internet connection!]
* Then type
	git config pull.rebase false
  followed by
	git pull
=> All changes in the GitHub repository will be merged with the local Installation, but locally modified files will be maintained.

2.3 Start the software
* In the terminal, change to the software directory
	cd ~/2LabsToGo-Eco/2LabsToG-Eco-Software
  followed by 
    python3 run.py (or use the defined alias)

2.4 Open the browser and delete the cache to prevent loading old Java scripts.
* Open the browser’s menu and click on “Settings”.
* Search for “cache” and select ”Delete browsing data”.
* Select “All time” and “Cached images and files”.
* Click “Delete data”.

2.5 In a new browser tab, open the software (address: 127.0.0.1:8000).

3. Updates concern gcodegenerator.py and/or detections.js
If the update concerns the file GcodeGenerator.py, copy the data INIT_POINT_X and INIT_POINT_Y and the vial positions from the old software (back-up) to the updated software.
If the update concerns the file detection.js, copy the photo position from the old software (back-up) to the updated software.

3.1 INIT_POINT_X, INIT_POINT_Y points, and vial positions
To correct INIT_POINT_X and INIT_POINT_Y and the vial positions, open the file
	2LabsToGo-Software/app/finecontrol/gcode/GcodeGenerator.py
with Geany, overwrite the below exemplarily listed values by the values of the back-up file and save the file.

	INIT_POINT_X = 20
	INIT_POINT_Y = 3.5

	class GcodeGenerator:
		# set these values according to each machine!!!
		pos_common= "G0Z"
		vial_9= "145" #rinse bottle
		vial_8= "267.5" #vial 8
		vial_7= "253.5" #vial 7
		vial_6= "239.5" #vial 6
		vial_5= "225.5" #vial 5
		vial_4= "211.5" #vial 4
		vial_3= "197.5" #vial 3
		vial_2= "183.5" #vial 2
		vial_1= "169.5" #vial 1
		rin_bot= "145" #rinse bottle

3.2 Photo position 
To correct the photo position, open the file
	2LabsToGo-Software/app/templates/js/oclab/detection.js
with Geany and overwrite the Y value by the value of the back-up file and save the file.

	gcode = 'G1X90\nG28YZ\nG1Y158Z270F3000' //Y value depends on each system

4. In case of a complete new 2LabsToGo-Eco Installation (install.py and run.py have been executed), import the old database (methods and images) and the media folder (images, gcode files).
* Disconnect the board (“Connection” tab in browser) and close all tabs.
* Stop the server with “Ctrl+c” in the running terminal.
* Then execute in the terminal 
	cd app  (change to the directory 2LabsToGo-Eco/2LabsToGoEco-Software/app)
  followed by the next command
	python3 db-import.py
	
The Python script will rename the newly created and empty database db.sqlite3 to db-new.sqlite3	and rename the media folder to media-new.
Additionally, the Python script will delete all 0001_initial.py in migrations of sampleapp, finecontrol, development, and detection.

* From the backup, copy the old database (/app/db.sqlite3) and the media folder (/app/media) to the 2LabsToGo-Eco-Software/app folder of the new installation.

Executing python3 run.py will now perform the new migrations and load the old database.
	cd ..  (go back to the folder 2LabsToGo-Eco-Software)
	python3 run.py  (or type the created alias)

5. Special upgrade procedure if the database structure was modified
For this purpose, a Python script (update_db.py) will be available in the app folder, to be executed with 
	cd 2LabsToGo-Eco/2LabsToGo-Eco-Software/app
followed by
	python3 update_db.py
	
In Update history.txt, information concerning the changes are given.
The Python script will modify the database and also will delete all 0001_initial.py in migrations of sampleapp, finecontrol, development, and detection.

Executing python3 run.py will now perform the new migrations and load the modified database.
	cd ..  (go back to the folder 2LabsToGo-Eco-Software)
	python3 run.py  (or type the created alias)

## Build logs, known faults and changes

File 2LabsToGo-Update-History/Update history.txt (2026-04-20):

Update history

Date: 05-10-2025
Done: General software update
Concerned: many files

Date: 06-03-2025
Done: Update for humidity-control
Concerned: 
2LabsToGo-Eco-Hardware/3D-parts (openSCAD, STL), 
2LabsToGo-Eco-Hardware/Materials-Lists (Bill of Materials_humidity-control, additional baskets),
2LabsToGo-Eco-Firmware (Marlin, firmware hex file)

Date: 07-25-2025
Done: Sample tables updated (application pattern changes without erasing the sample table)
Concerned:
2LabsToGo-Eco-Software/app/templates/js/oclab/sample.js
2LabsToGo-Eco-Software/app/templates/js/oclab/samplesp.js
2LabsToGo-Eco-Software/app/templates/modules/loadlist/loadlist.js
2LabsToGo-Eco-Software/app/templates/modules/sampleapp/table/table.js
2LabsToGo-Eco-Software/app/templates/modules/sampleappsp/tablesp/tablesp.js

Date: 08-22-2025
Done: Method Finecontrol/Dispensing valve corrected
Concerned:
2LabsToGo-Eco-Software/app/templates/modules/dispensevalve/dispensevalve.js

Date: 09-08-2025
Done: Electronic box modified for humidity Control; two-parted frame added to support the old model
Concerned:
2LabsToGo-Eco-Hardware/3D-Parts/Autodesk Fusion/electronic box.3fd
2LabsToGo-Eco-Hardware/3D-Parts/STL/electronic-box/electronic_box.stl
2LabsToGo-Eco-Hardware/3D-Parts/STL/electronic-box/electronic_box_frame-part1.stl
2LabsToGo-Eco-Hardware/3D-Parts/STL/electronic-box/electronic_box_frame-part2.stl

Date: 09-20-2025
Done: README in main updated
Done: Instruction Visual Studio Code corrected

Date: 09-22-205
Done: Humidity Control updated (Firmware and Software), now allowing both drying and humidifying the 2LabsToGo-Eco before development.
Concerned:
2LabsToGo-Eco-Firmware (Marlin; firmware_2LabsToGo-Eco.hex)
2LabsToGo-Eco-Software/app/templates/modules/humiditycontrol/humiditycontrol.html
2LabsToGo-Eco-Software/app/templates/modules/humiditycontrol/humiditycontrol.js

Date: 10-13-2025
Done: README in main updated
Concerned: Raspberry Pi operating system "bullseye" 

Date: 11-18-2025
Done: Some files have been cleaned up.
Concerned: migrations, update is not required

Date: 12-02-2025
Done:  Java scripts updated, now better working
Concerned: drypump.js, dispensvalve.js, wayvalve.js

Date: 03-03-2026
Done: Updates to Django 5, Debian 13 (Trixie), and Raspberry Pi 5B
Concerned: Man files, but not GcodeGenerator.py and detection.js

Date: 03-03-2026
Done: 3D files atomizer optimized
Concerned: atomizer.f3d (Fusion file), nebulizer_atomizer_part-1.stl, nebulizer_atomizer_part-2.stl, nebulizer_atomizer_washer.stl

Date: 04-03-2026
Done: Operational qualification updated
Concerned: Different folders Operational_qualificaction added (Pi4-bullseye, P4-trixie, P5-trixie)

Date: 04-05-2026
Done: Electronics updated
Concerned: 2LabsToGo-Eco-Hardware/Electronics

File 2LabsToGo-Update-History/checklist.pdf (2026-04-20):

### checklist

Before installing the software, please note the following points.

Git clone, updates and installation of software packages require internet access!

- Static IP address for LAN connection was entered in the Raspberry Pi (ask your IT service how to apply for an IP address).

[Alternatively, wireless LAN was configured: Connect Raspberry Pi to WiFi: Step-by-Step Guide.] (https://linuxconfig.org/connecting-your-raspberry-pi-to-wi-fi-a-how-to)

- Firmware was successfully flashed.

Then open a Linux terminal

and execute the follwing commands:

cd /home/to-my-folder/2LabsToGo-Eco/2LabsToGo-Eco-Software

sudo python3 install.py |& tee install-py.txt

This will update and upgrade the operating system, follwed by the installation of software packages. All procedures are logged in install-py.txt.

sudo python3 run.py |& tee run-py.txt

- The first run.py takes a while!

This will install the docker image and create the docker containers, perform the Django migrations and connect to the Django server.
With the terminal message “Quit the server with CONTROL-C.”, the software is ready to go.
- Open a browser and enter “127.0.0.1:8000” in the address field.

The connection tab will be opened followed by opening the user management.

- Register a new user.

Thereafter, the software is ready to be used.

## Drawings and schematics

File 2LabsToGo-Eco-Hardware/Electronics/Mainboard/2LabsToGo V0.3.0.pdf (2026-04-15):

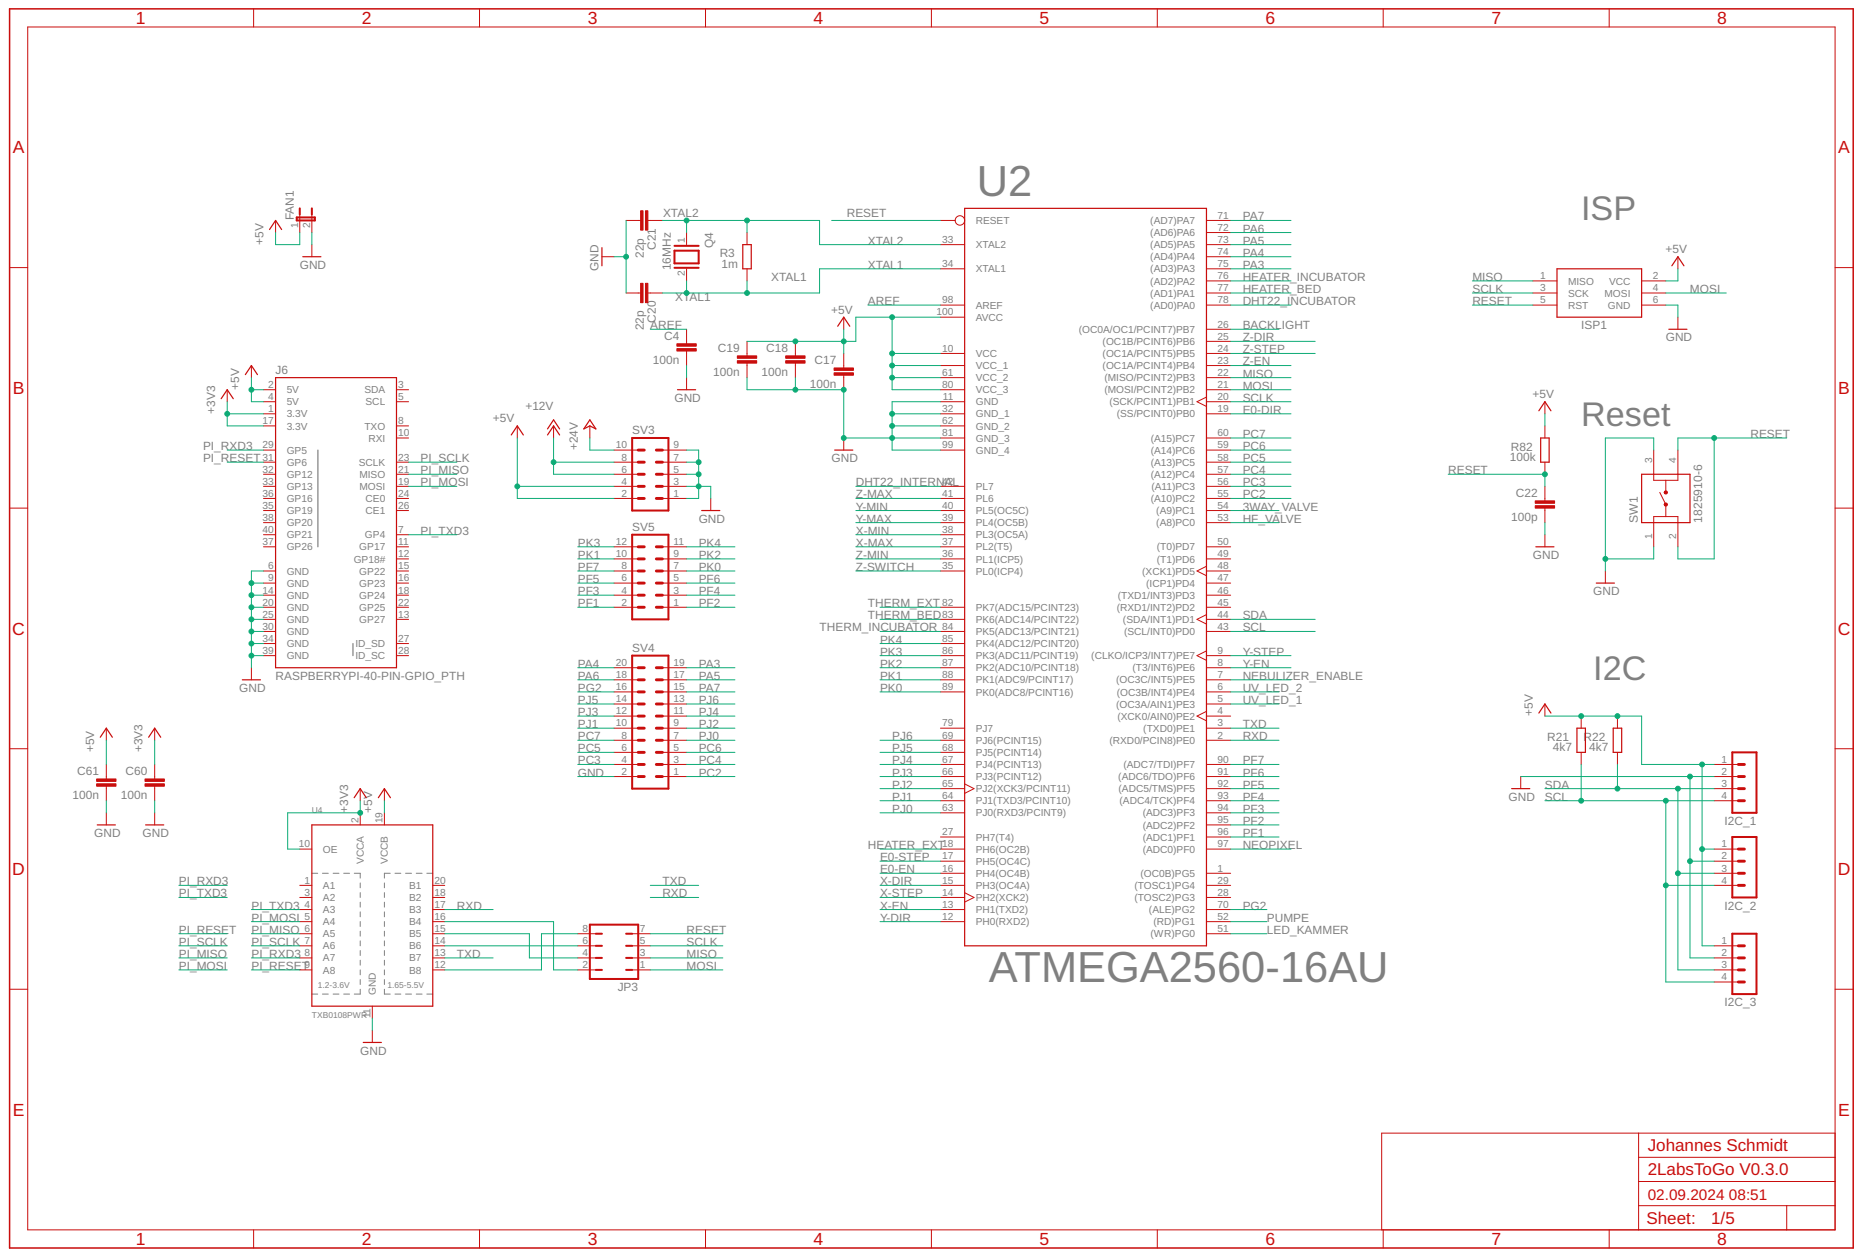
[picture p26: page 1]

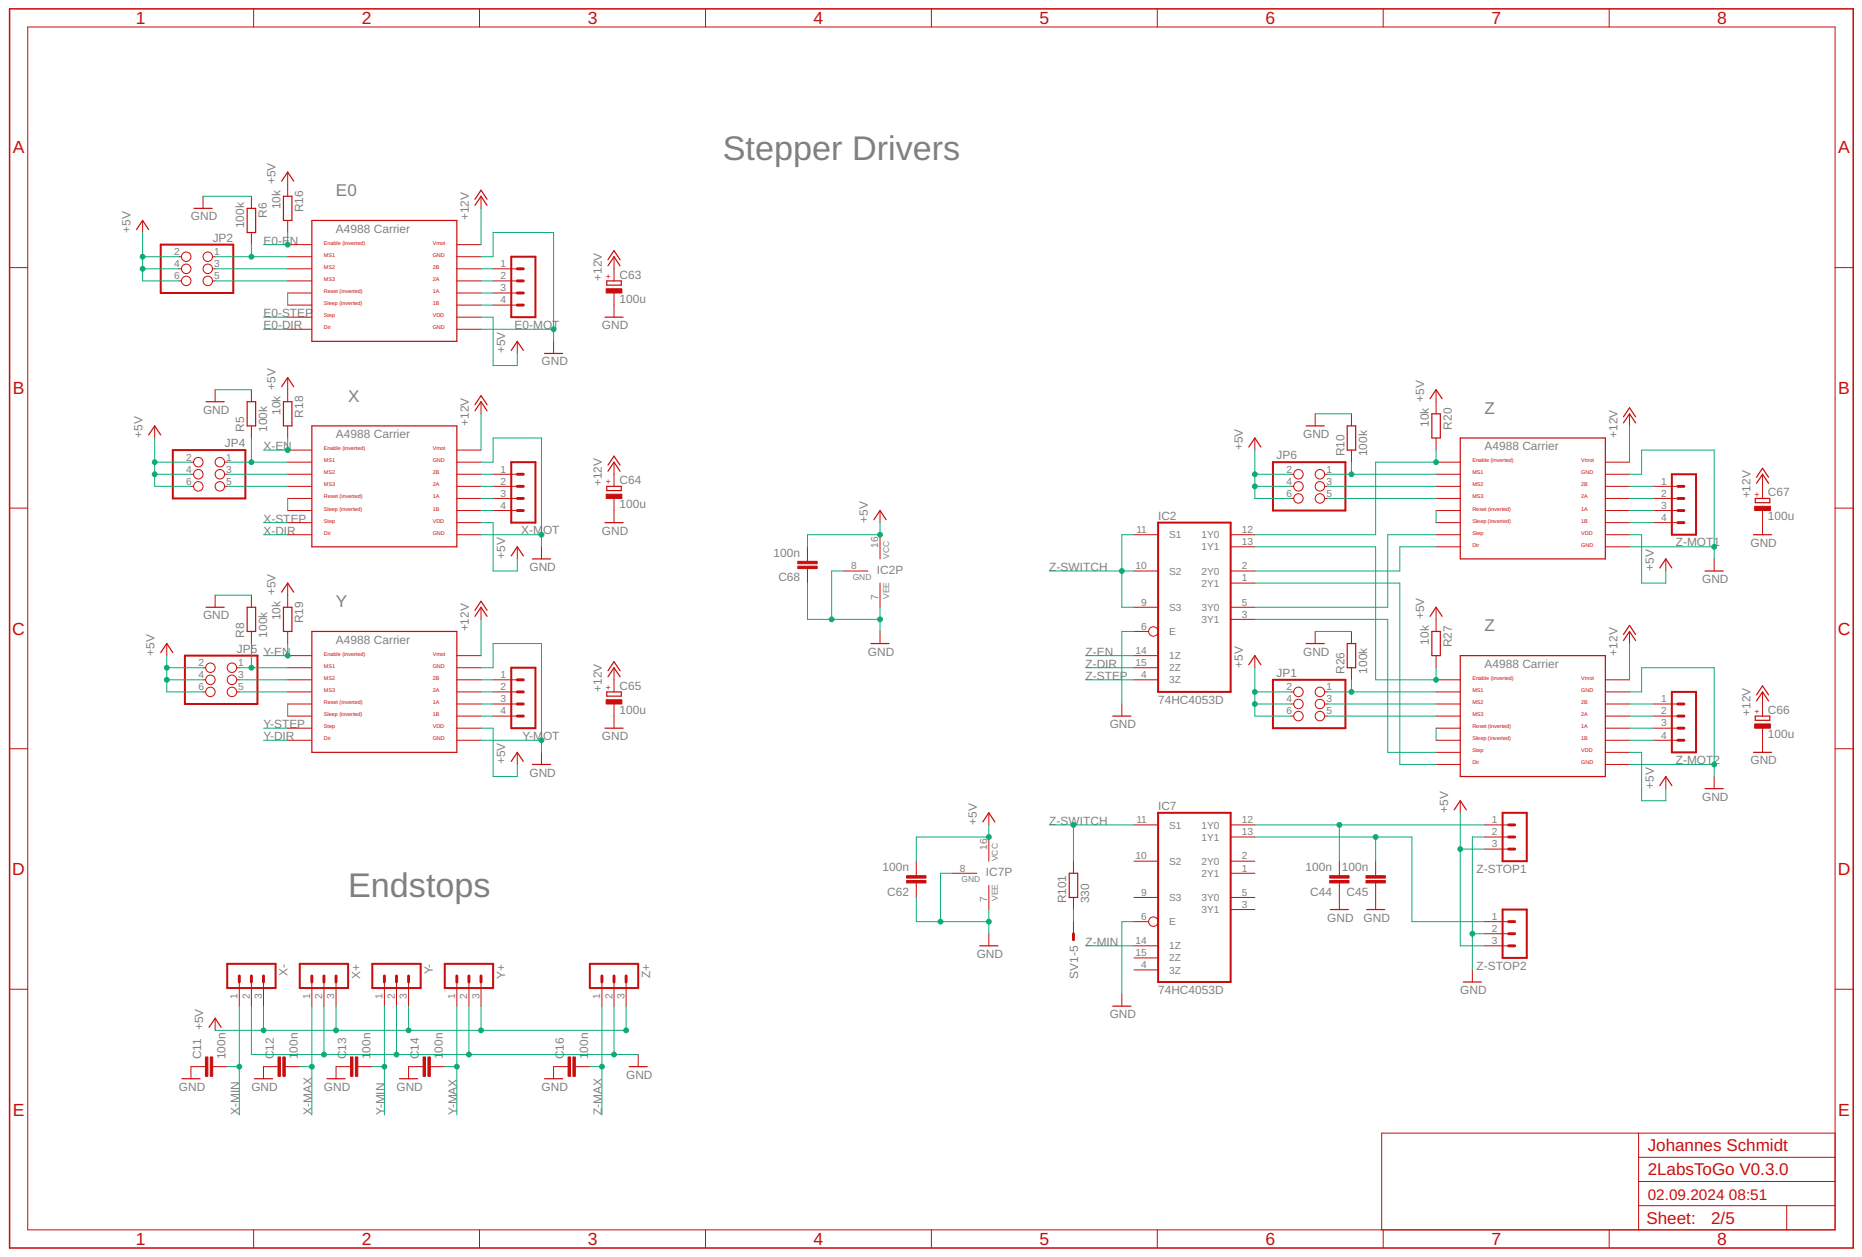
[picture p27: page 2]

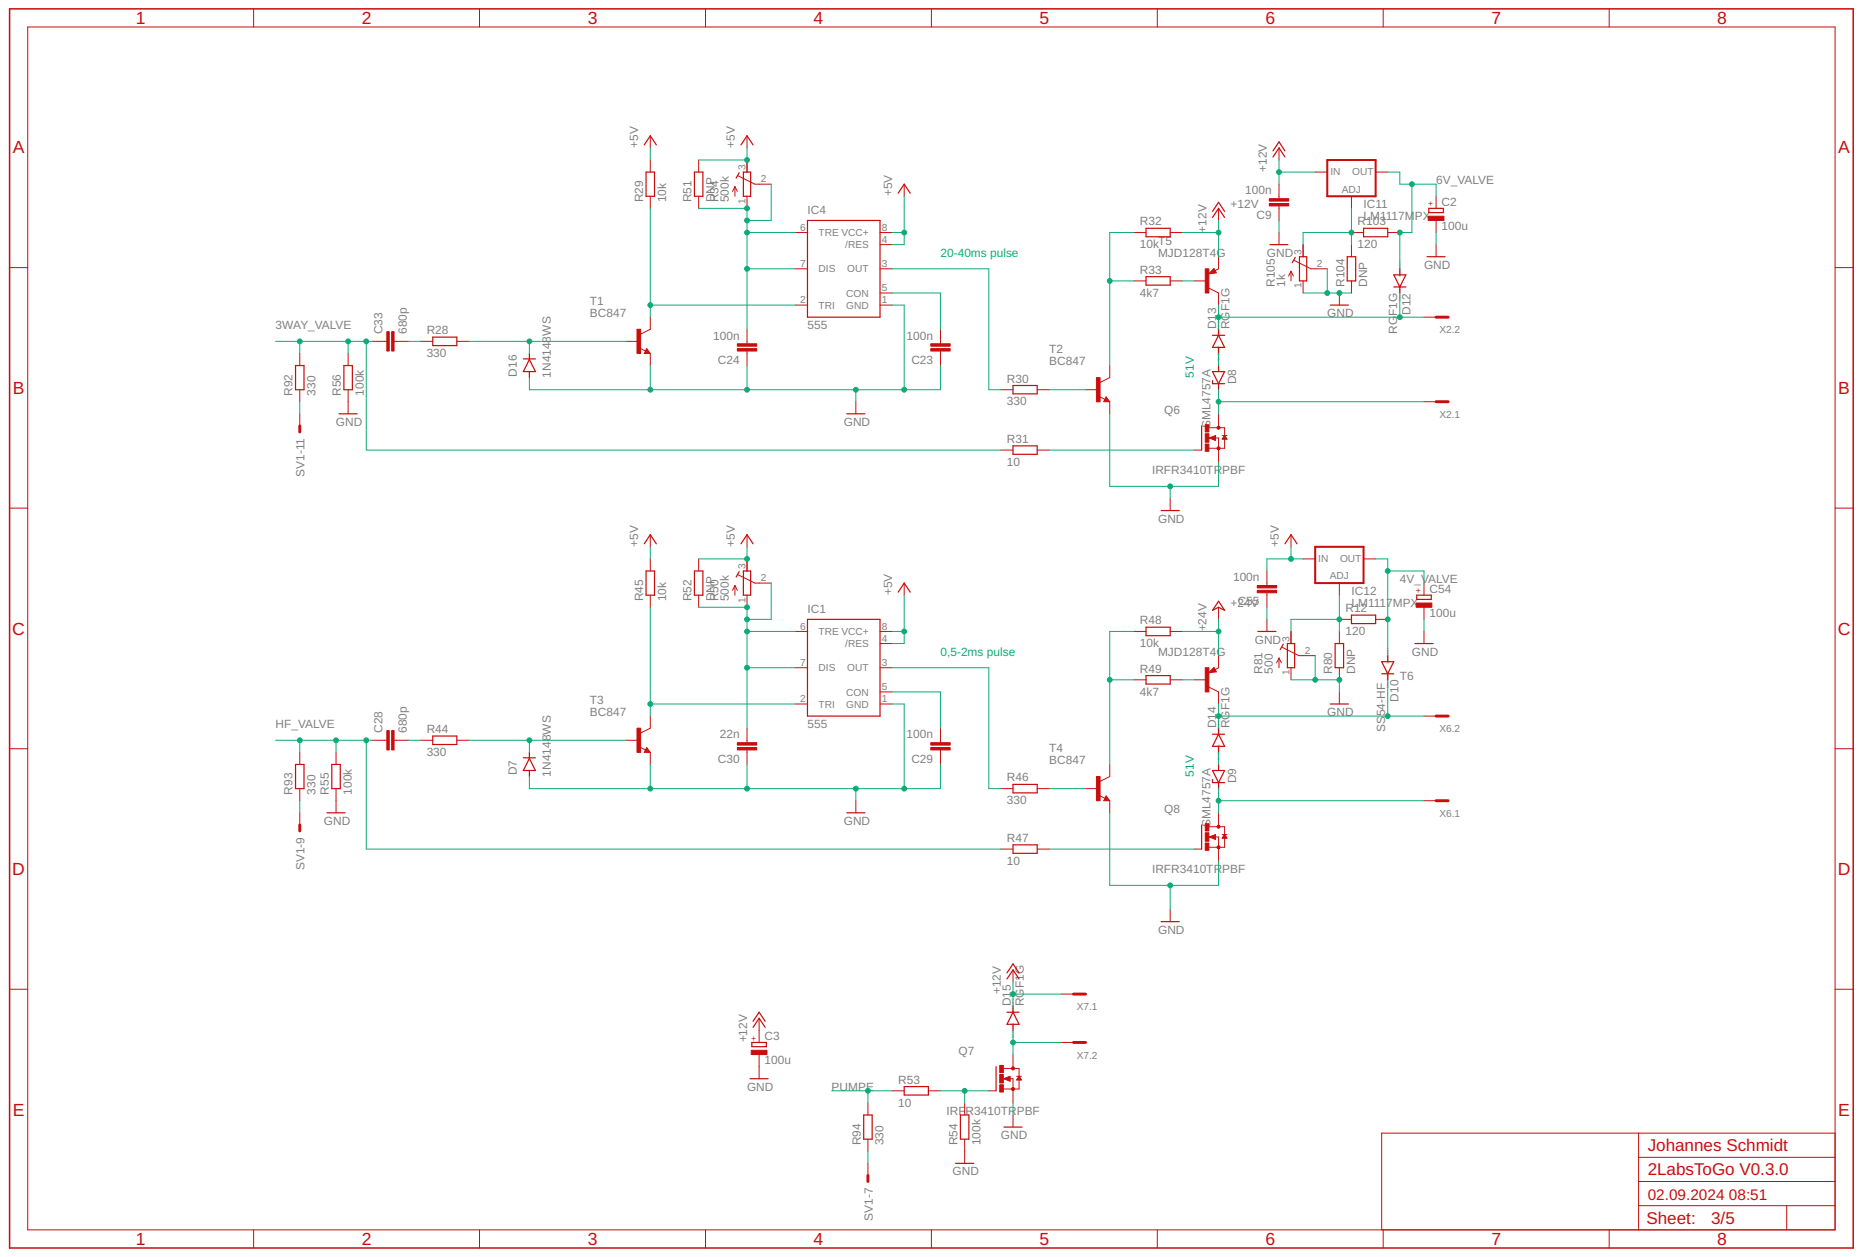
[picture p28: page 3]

SpiceOrder 1 SpiceOrder 2 SpiceOrder 1 SpiceOrder 2 SpiceOrder 1 SpiceOrder 2 SpiceOrder 1 SpiceOrder 2 SpiceOrder 1 SpiceOrder 2 330 10k 330 10 10k 4k7 680p 100n 100n GND GND 500k +5V +5V +5V IRFR3410TRPBF BC847 BC847 555 +12V 330 10k 330 10 10k 4k7 680p 22n 100n GND GND 500k +5V +5V +5V IRFR3410TRPBF BC847 BC847 555 +24V MJD128T4G MJD128T4G DNP DNP IRFR3410TRPBF 10 100k 100k 100k GND GND GND GND +12V +5V 120DNP 500 GND SML4757A SML4757A SS54-HF RGF1G RGF1G RGF1G RGF1G 330 330 330 +12V GND100u 100u GND 100nGND 1N4148WS 1N4148WS 120DNP 1k 100u GND 100nGND GND +12V LM1117MPX LM1117MPX R28 R29 R30 R31 R32 R33 C33 C24 C23 1 3 2 R34 Q6 T1 T2 TRE 6 OUT 3 DIS 7 TRI 2 VCC+ 8 GND 1 CON 5 /RES 4 IC4 R44 R45 R46 R47 R48 R49 C28 C30 C29 1 3 2 R50 Q8 T3 T4 TRE 6 OUT 3 DIS 7 TRI 2 VCC+ 8 GND 1 CON 5 /RES 4 IC1 T5 T6 R51 R52 Q7 R53 R54 R55 R56 R12 R80 1 3 2 R81 D8 D9 D10 D12 D13 D14 D15 R92 R93 R94 C3 SV1-11 X2.1 X2.2 X6.1 X6.2 X7.1 X7.2 C54 C55 D7 D16 SV1-9 SV1-7 R103 R104 1 3 2 R105 C2 C9 ADJ IN OUTIC11 ADJ IN OUTIC12 +12V 3WAY_VALVE +24V PUMPE 4V_VALVE HF_VALVE 6V_VALVE Johannes Schmidt Sheet: ABCDE 1 2 3 4 5 6 7 8 ABCDE 1 2 3 4 5 6 7 8 2LabsToGo V0.3.0 02.09.2024 08:51 3/5 + + + 0,5-2ms pulse 20-40ms pulse 51V 51V

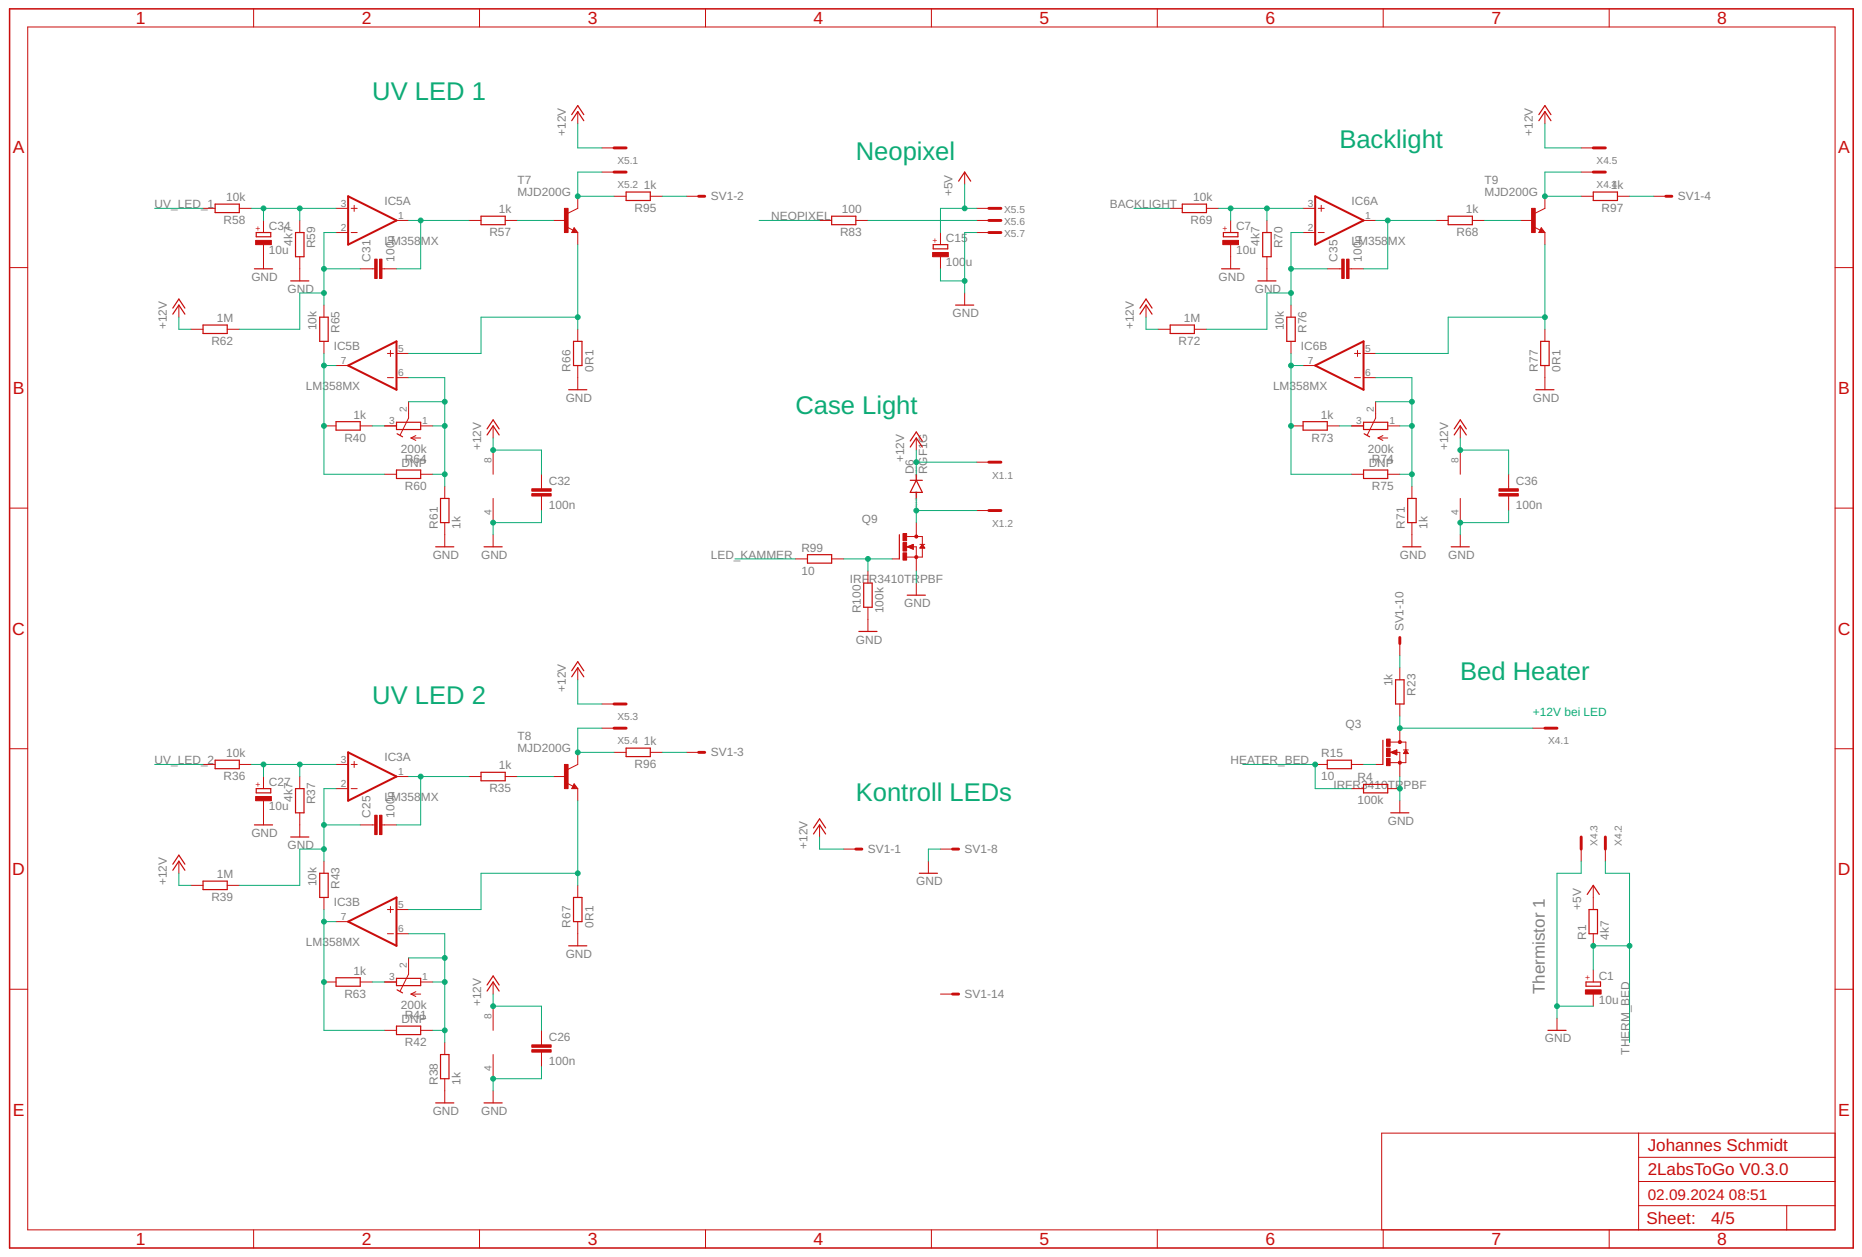
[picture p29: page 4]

SpiceOrder 1 SpiceOrder 2 LM358MX LM358MX 100n 100n 1k 10k 4k7 1k 1M GND 200k DNP 10k +12V 10uGND GND GND +12V 0R1 MJD200GGND +12V LM358MX LM358MX 100n 100n 1k 10k 4k7 1k 1M GND 200k DNP 10k +12V 10uGND GND GND +12V 0R1 MJD200GGND +12V LM358MX LM358MX 100n 100n 1k 10k 4k7 1k 1M GND 200k DNP 10k +12V GND GND GND +12V 0R1 MJD200GGND +12V 100 GND +5V 100u 1k1k 1k IRFR3410TRPBF 10 100k GND GND +12V RGF1G +12V GND GND 100k 10 1k 4k7 GND 10u 10u IRFR3410TRPBF +5V 1k1k 1k 23 1 IC5A65 7 IC5B C31 C32 R57 R58 R59 R61 R62 3 1 2 R64 R60 R65 C34 8 4 R66 T7 23 1 IC3A65 7 IC3B C25 C26 R35 R36 R37 R38 R39 3 1 2 R41 R42 R43 C27 8 4 R67 T8 23 1 IC6A65 7 IC6B C35 C36 R68 R69 R70 R71 R72 3 1 2 R74 R75 R76 8 4 R77 T9 R83 C15 R95 R96 R97 Q9 R99 R100 D6 SV1-1 SV1-2 SV1-3 SV1-4 SV1-8 SV1-14 R4 R15 R23 R1 C1 X5.1 X5.2 X5.3 X5.4 X5.5 X5.6 X5.7 X1.1 X1.2 X4.1 X4.2 X4.3 X4.4 X4.5 C7 Q3 SV1-10 R40 R63 R73 UV_LED_1 UV_LED_2 NEOPIXEL LED_KAMMER HEATER_BED THERM_BED BACKLIGHT Johannes Schmidt + + Sheet: ABCDE 1 2 3 4 5 6 7 8 ABCDE 1 2 3 4 5 6 7 8 2LabsToGo V0.3.0 02.09.2024 08:51 4/5 + + + UV LED 1 UV LED 2 Backlight Neopixel Case Light Kontroll LEDs +12V bei LED Bed Heater Thermistor 1

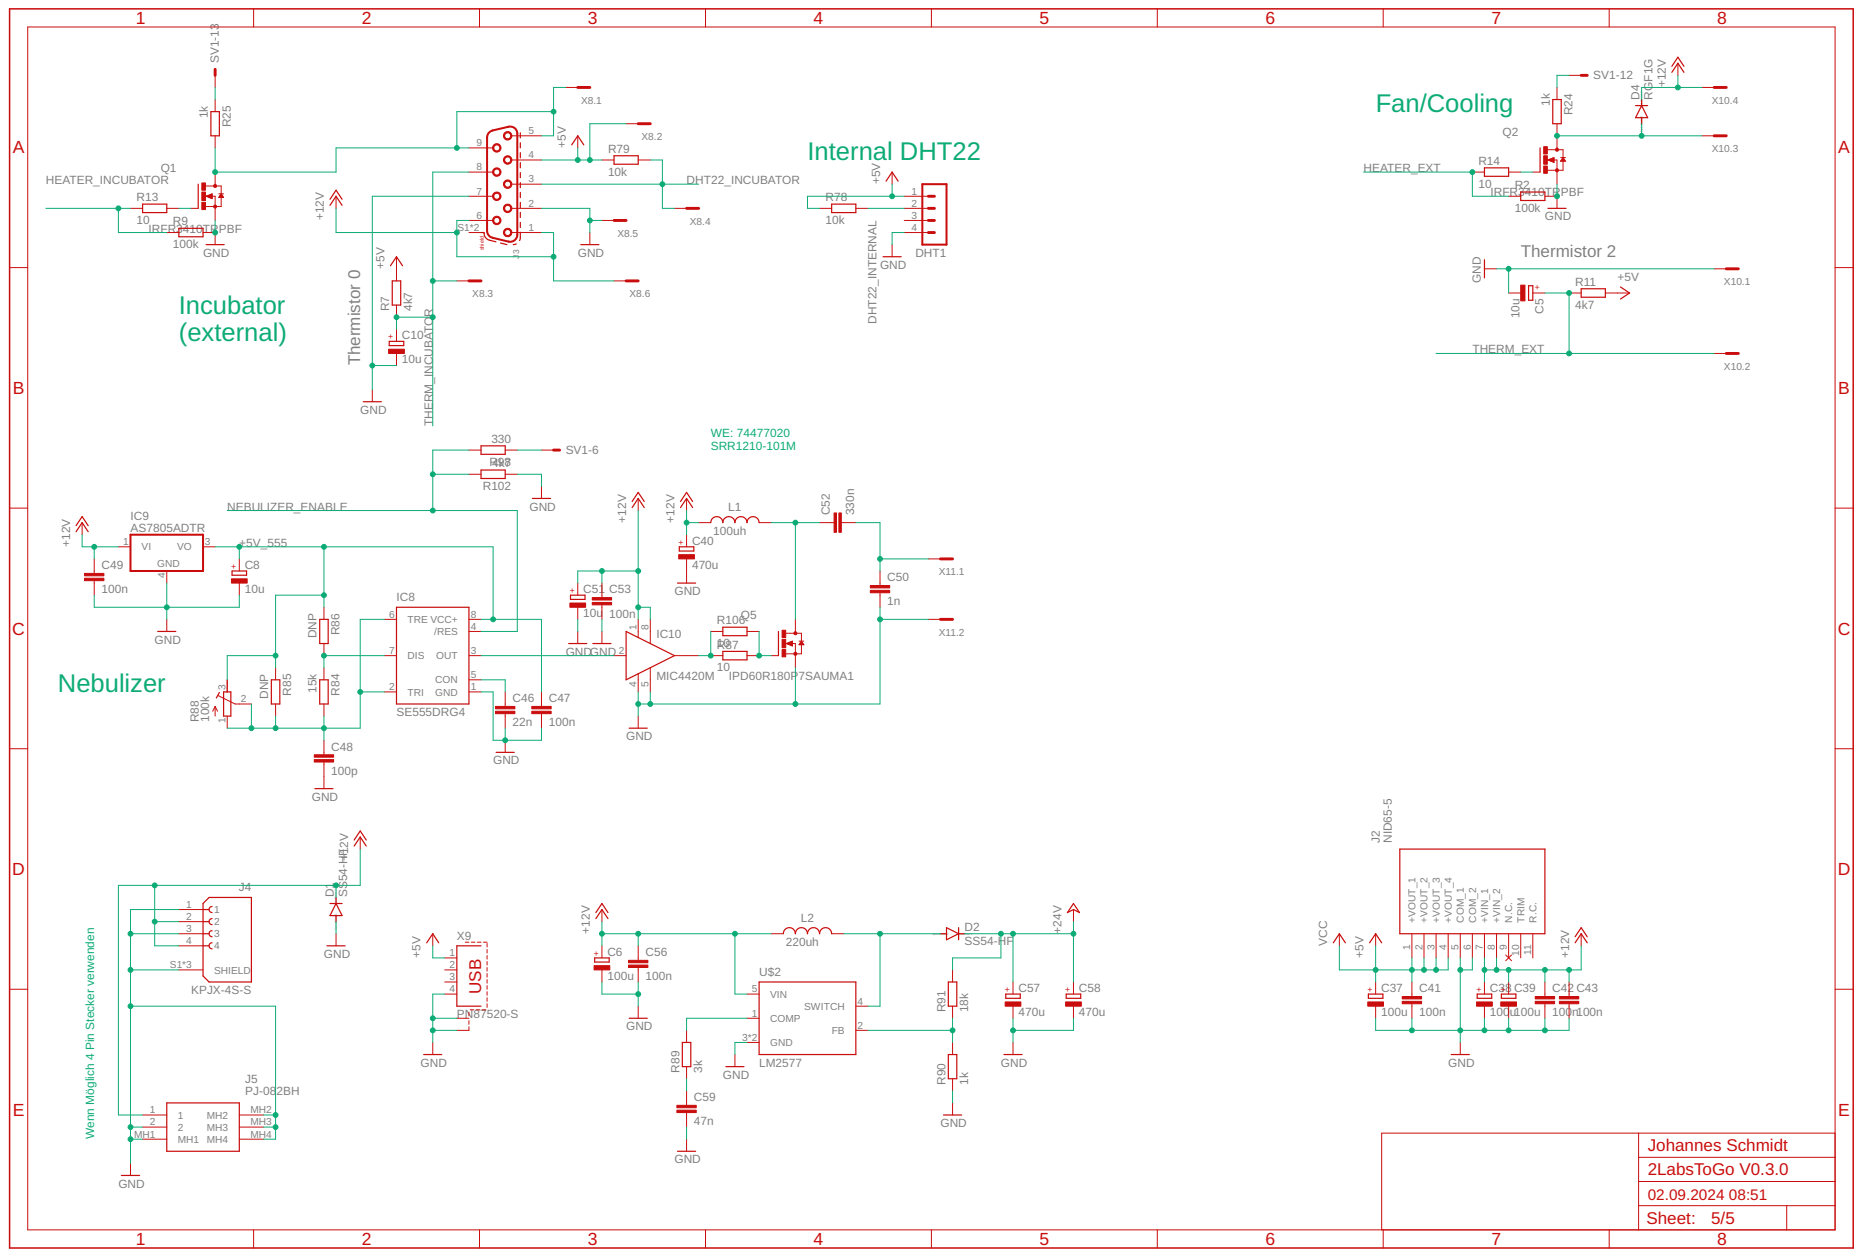
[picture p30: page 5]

Wenn Möglich 4 Pin Stecker verwenden

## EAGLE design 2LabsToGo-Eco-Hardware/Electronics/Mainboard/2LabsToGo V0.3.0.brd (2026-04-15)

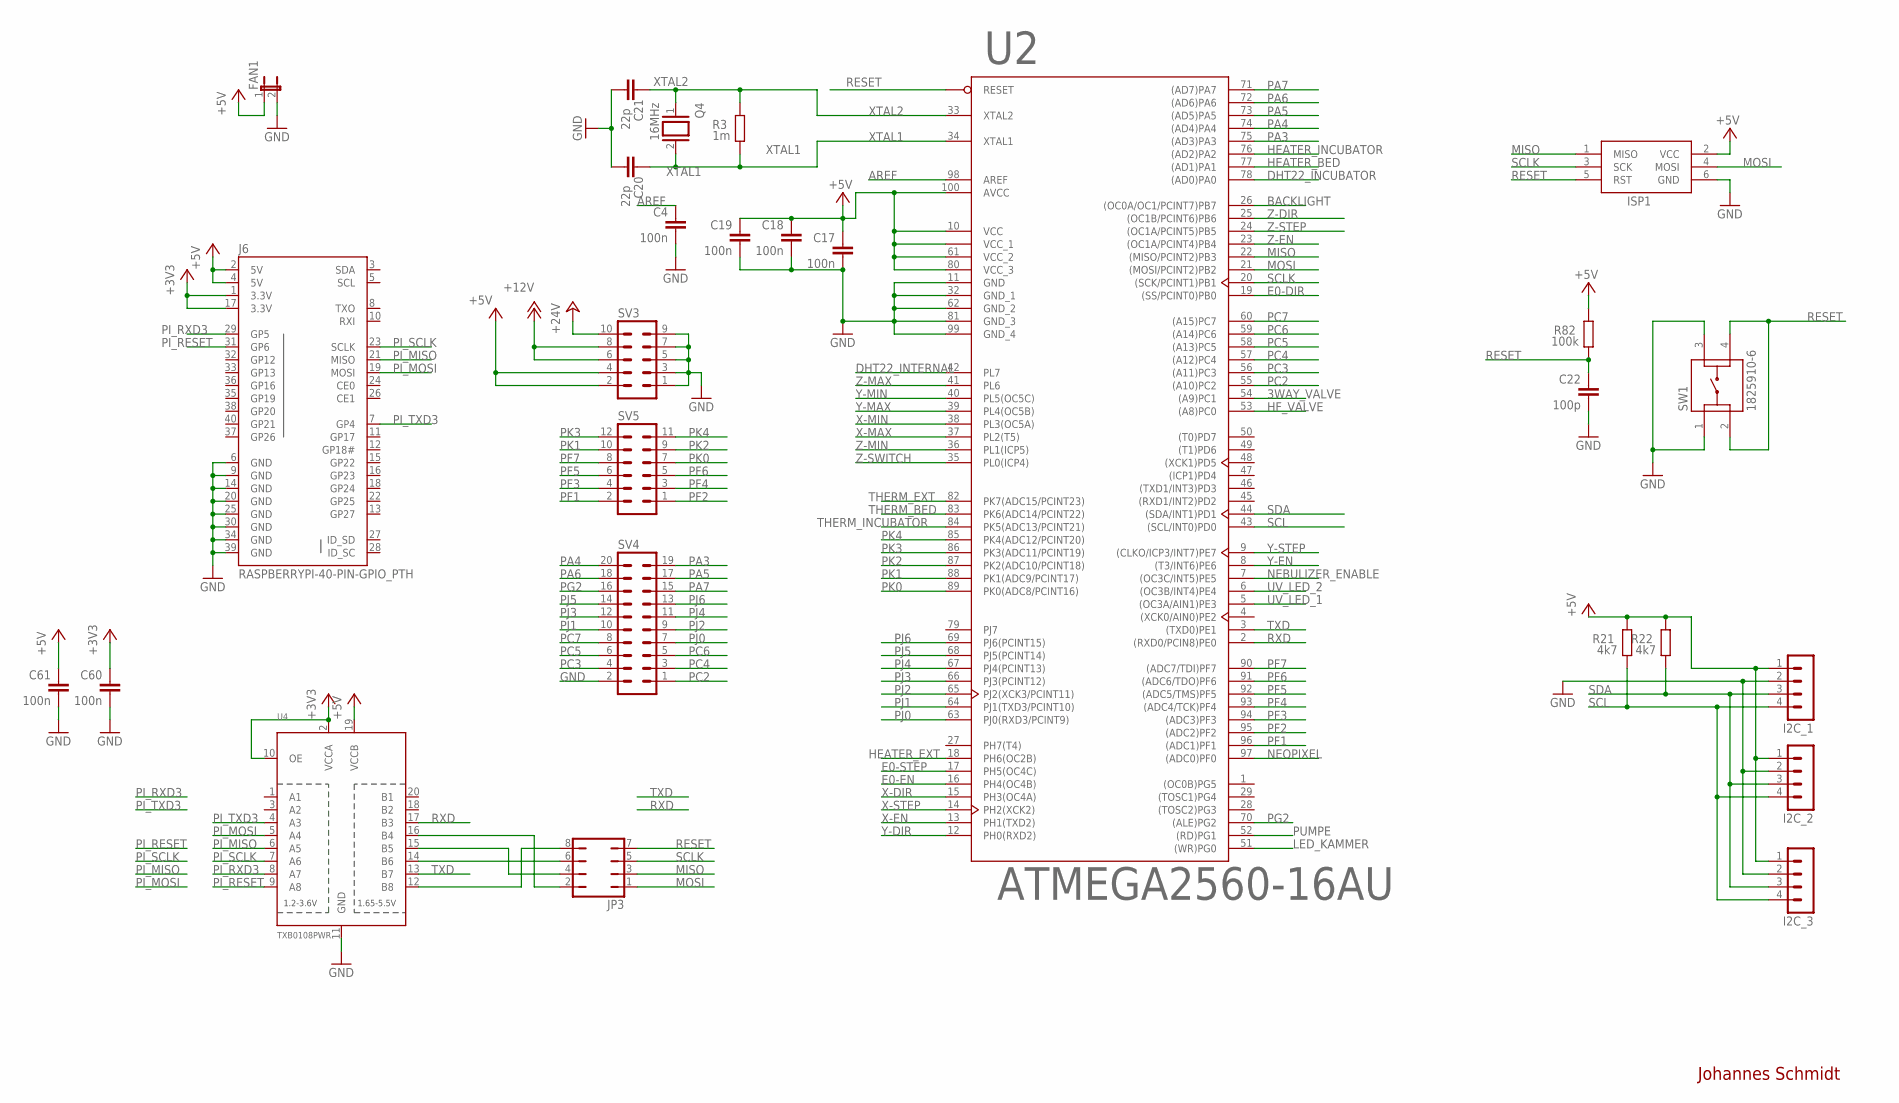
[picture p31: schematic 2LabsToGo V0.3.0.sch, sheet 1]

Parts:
C4, C17, C18, C19, C60, C61: 100n; C0805
C20, C21: 22p; C0805
C22: 100p; C0805
FAN1: JP1E; JP1
I2C_1, I2C_2, I2C_3: MA04-1
ISP1: AVRISP-6; AVRISP
J6: RASPBERRYPI-40-PIN-GPIO_PTH; 2X20_SHROUDED
JP3: JP4Q
Q4: 16MHz; QS
R3: 1m; R0805
R21, R22: 4k7; R0805
R82: 100k; R0805
SV3: MA05-2
SV4: MA10-2
SV5: MA06-2
SW1: 1825910-6
U2: ATMEGA2560-16AU; TQFP-100
U4: TXB0108PWR; TSSOP20

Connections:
3WAY_VALVE: U2.54 ((A9)PC1); also elsewhere on the board
+3V3: C60.1, J6.1 (3.3V), J6.17 (3.3V), U4.2 (VCCA), U4.10 (OE)
+5V: C17.1, C18.1, C19.1, C61.1, FAN1.1, I2C_1.1, I2C_2.1, I2C_3.1, ISP1.2 (VCC), J6.2 (5V), J6.4 (5V), R21.2, R22.2, R82.2, SV3.2, SV3.4, U2.10 (VCC), U2.31 (VCC_1), U2.61 (VCC_2), U2.80 (VCC_3), U2.100 (AVCC), U4.19 (VCCB); also elsewhere on the board
+12V: SV3.6, SV3.8; also elsewhere on the board
+24V: SV3.10; also elsewhere on the board
AREF: C4.1, U2.98 (AREF)
BACKLIGHT: U2.26 ((OC0A/OC1/PCINT7)PB7); also elsewhere on the board
DHT22_INCUBATOR: U2.78 ((AD0)PA0); also elsewhere on the board
DHT22_INTERNAL: U2.42 (PL7); also elsewhere on the board
E0-DIR: U2.19 ((SS/PCINT0)PB0); also elsewhere on the board
E0-EN: U2.16 (PH4(OC4B)); also elsewhere on the board
E0-STEP: U2.17 (PH5(OC4C)); also elsewhere on the board
GND: C4.2, C17.2, C18.2, C19.2, C20.1, C21.1, C22.2, C60.2, C61.2, FAN1.2, I2C_1.2, I2C_2.2, I2C_3.2, ISP1.6 (GND), J6.6 (GND), J6.9 (GND), J6.14 (GND), J6.20 (GND), J6.25 (GND), J6.30 (GND), J6.34 (GND), J6.39 (GND), SV3.1, SV3.3, SV3.5, SV3.7, SV3.9, SV4.2, SW1.1, SW1.3, U2.11 (GND), U2.32 (GND_1), U2.62 (GND_2), U2.81 (GND_3), U2.99 (GND_4), U4.11 (GND); also elsewhere on the board
HEATER_BED: U2.77 ((AD1)PA1); also elsewhere on the board
HEATER_EXT: U2.18 (PH6(OC2B)); also elsewhere on the board
HEATER_INCUBATOR: U2.76 ((AD2)PA2); also elsewhere on the board
HF_VALVE: U2.53 ((A8)PC0); also elsewhere on the board
LED_KAMMER: U2.51 ((WR)PG0); also elsewhere on the board
MISO: ISP1.1 (MISO), JP3.3, U2.22 ((MISO/PCINT2)PB3)
MOSI: ISP1.4 (MOSI), JP3.1, U2.21 ((MOSI/PCINT2)PB2)
unnamed: JP3.2, U4.16 (B4)
unnamed: JP3.8, U4.12 (B8)
unnamed: JP3.6, U4.14 (B6)
unnamed: JP3.4, U4.15 (B5)
NEBULIZER_ENABLE: U2.7 ((OC3C/INT5)PE5); also elsewhere on the board
NEOPIXEL: U2.97 ((ADC0)PF0); also elsewhere on the board
PA3: SV4.19, U2.75 ((AD3)PA3)
PA4: SV4.20, U2.74 ((AD4)PA4)
PA5: SV4.17, U2.73 ((AD5)PA5)
PA6: SV4.18, U2.72 ((AD6)PA6)
PA7: SV4.15, U2.71 ((AD7)PA7)
PC2: SV4.1, U2.55 ((A10)PC2)
PC3: SV4.4, U2.56 ((A11)PC3)
PC4: SV4.3, U2.57 ((A12)PC4)
PC5: SV4.6, U2.58 ((A13)PC5)
PC6: SV4.5, U2.59 ((A14)PC6)
PC7: SV4.8, U2.60 ((A15)PC7)
PF1: SV5.2, U2.96 ((ADC1)PF1)
PF2: SV5.1, U2.95 ((ADC2)PF2)
PF3: SV5.4, U2.94 ((ADC3)PF3)
PF4: SV5.3, U2.93 ((ADC4/TCK)PF4)
PF5: SV5.6, U2.92 ((ADC5/TMS)PF5)
PF6: SV5.5, U2.91 ((ADC6/TDO)PF6)
PF7: SV5.8, U2.90 ((ADC7/TDI)PF7)
PG2: SV4.16, U2.70 ((ALE)PG2)
PI_MISO: J6.21 (MISO), U4.6 (A5)
PI_MOSI: J6.19 (MOSI), U4.5 (A4)
PI_RESET: J6.31 (GP6), U4.9 (A8)
PI_RXD3: J6.29 (GP5), U4.8 (A7)
PI_SCLK: J6.23 (SCLK), U4.7 (A6)
PI_TXD3: J6.7 (GP4), U4.4 (A3)
PJ0: SV4.7, U2.63 (PJ0(RXD3/PCINT9))
PJ1: SV4.10, U2.64 (PJ1(TXD3/PCINT10))
PJ2: SV4.9, U2.65 (PJ2(XCK3/PCINT11))
PJ3: SV4.12, U2.66 (PJ3(PCINT12))
PJ4: SV4.11, U2.67 (PJ4(PCINT13))
PJ5: SV4.14, U2.68 (PJ5(PCINT14))
PJ6: SV4.13, U2.69 (PJ6(PCINT15))
PK0: SV5.7, U2.89 (PK0(ADC8/PCINT16))
PK1: SV5.10, U2.88 (PK1(ADC9/PCINT17))
PK2: SV5.9, U2.87 (PK2(ADC10/PCINT18))
PK3: SV5.12, U2.86 (PK3(ADC11/PCINT19))
PK4: SV5.11, U2.85 (PK4(ADC12/PCINT20))
PUMPE: U2.52 ((RD)PG1); also elsewhere on the board
RESET: C22.1, ISP1.5 (RST), JP3.7, R82.1, SW1.2, SW1.4, U2.30 (RESET)
RXD: U2.2 ((RXD0/PCIN8)PE0), U4.17 (B3)
SCL: I2C_1.4, I2C_2.4, I2C_3.4, R21.1, U2.43 ((SCL/INT0)PD0)
SCLK: ISP1.3 (SCK), JP3.5, U2.20 ((SCK/PCINT1)PB1)
SDA: I2C_1.3, I2C_2.3, I2C_3.3, R22.1, U2.44 ((SDA/INT1)PD1)
THERM_BED: U2.83 (PK6(ADC14/PCINT22)); also elsewhere on the board
THERM_EXT: U2.82 (PK7(ADC15/PCINT23)); also elsewhere on the board
THERM_INCUBATOR: U2.84 (PK5(ADC13/PCINT21)); also elsewhere on the board
TXD: U2.3 ((TXD0)PE1), U4.13 (B7)
UV_LED_1: U2.5 ((OC3A/AIN1)PE3); also elsewhere on the board
UV_LED_2: U2.6 ((OC3B/INT4)PE4); also elsewhere on the board
X-DIR: U2.15 (PH3(OC4A)); also elsewhere on the board
X-EN: U2.13 (PH1(TXD2)); also elsewhere on the board
X-MAX: U2.37 (PL2(T5)); also elsewhere on the board
X-MIN: U2.38 (PL3(OC5A)); also elsewhere on the board
X-STEP: U2.14 (PH2(XCK2)); also elsewhere on the board
XTAL1: C20.2, Q4.2, R3.1, U2.34 (XTAL1)
XTAL2: C21.2, Q4.1, R3.2, U2.33 (XTAL2)
Y-DIR: U2.12 (PH0(RXD2)); also elsewhere on the board
Y-EN: U2.8 ((T3/INT6)PE6); also elsewhere on the board
Y-MAX: U2.39 (PL4(OC5B)); also elsewhere on the board
Y-MIN: U2.40 (PL5(OC5C)); also elsewhere on the board
Y-STEP: U2.9 ((CLKO/ICP3/INT7)PE7); also elsewhere on the board
Z-DIR: U2.25 ((OC1B/PCINT6)PB6); also elsewhere on the board
Z-EN: U2.23 ((OC1A/PCINT4)PB4); also elsewhere on the board
Z-MAX: U2.41 (PL6); also elsewhere on the board
Z-MIN: U2.36 (PL1(ICP5)); also elsewhere on the board
Z-STEP: U2.24 ((OC1A/PCINT5)PB5); also elsewhere on the board
Z-SWITCH: U2.35 (PL0(ICP4)); also elsewhere on the board

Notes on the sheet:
Johannes Schmidt

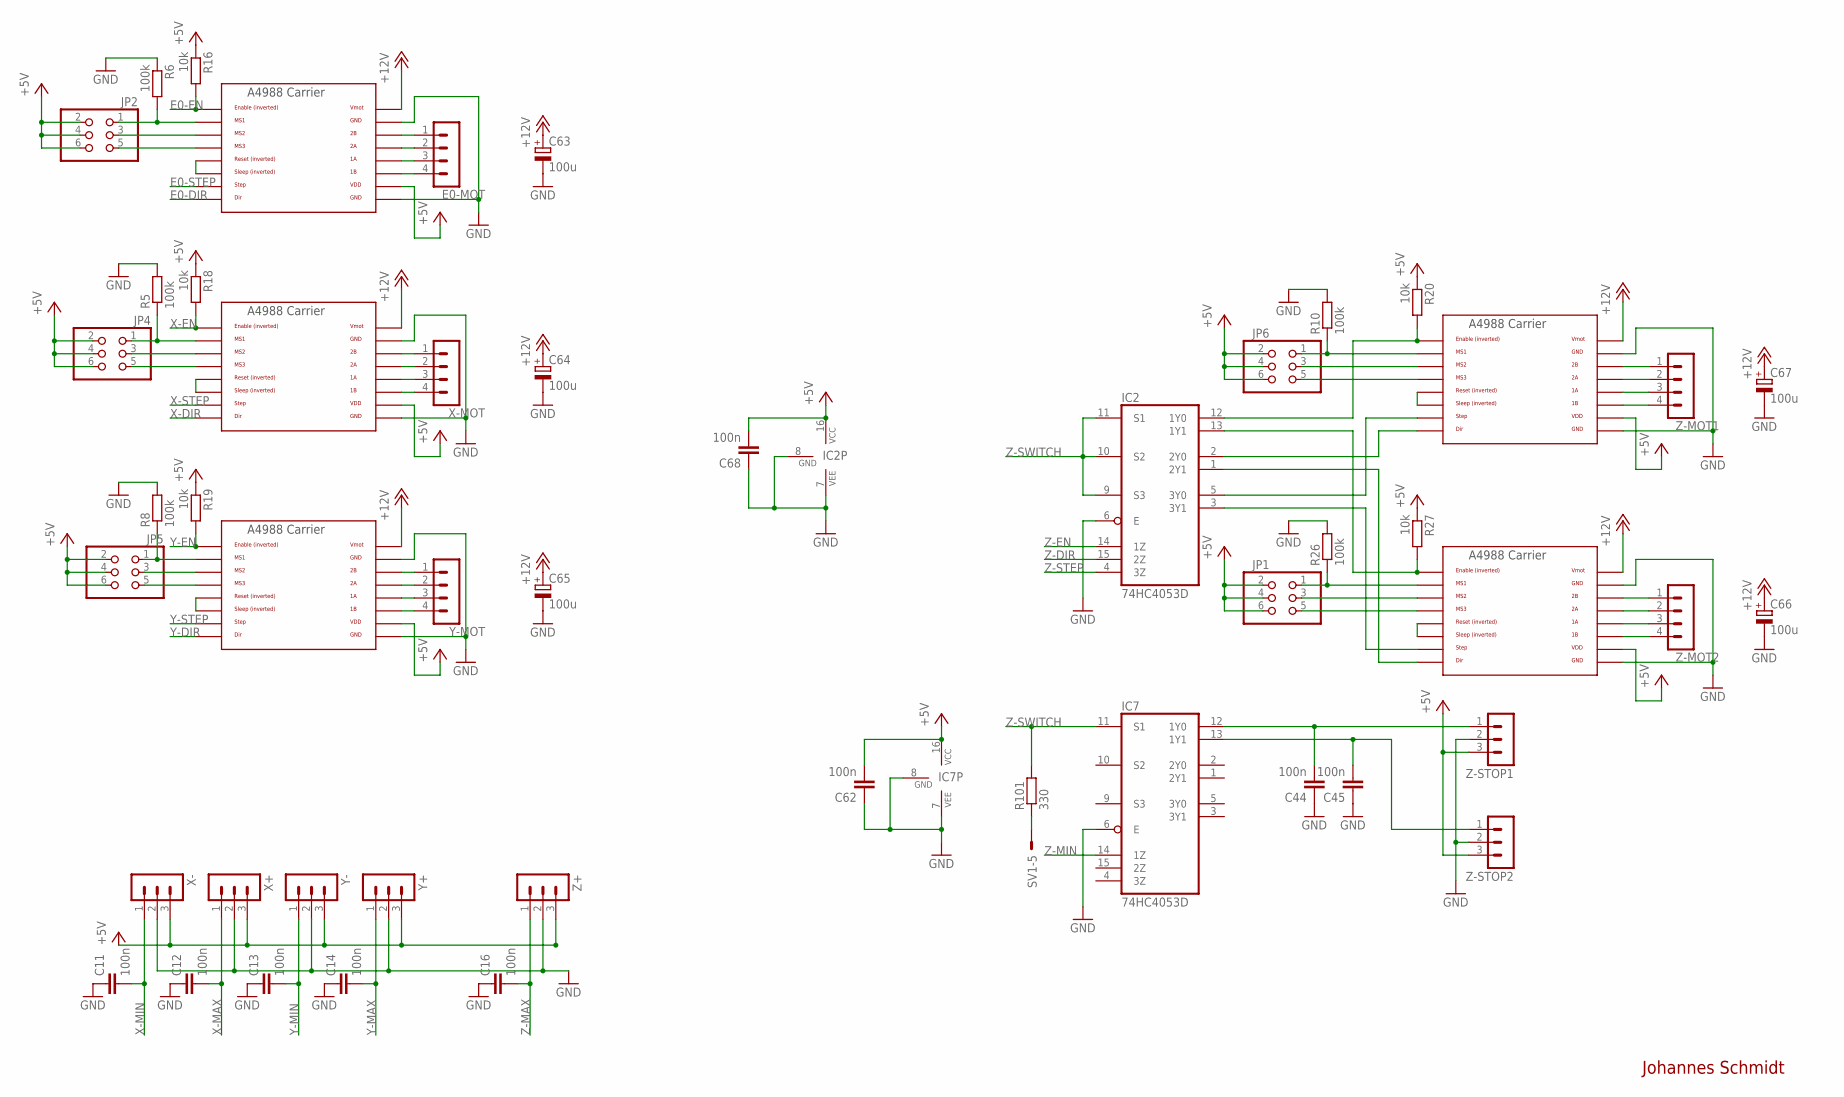
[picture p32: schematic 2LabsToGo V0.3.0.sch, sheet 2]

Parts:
C11, C12, C13, C14, C16, C44, C45, C62, C68: 100n; C0805
C63, C64, C65, C66, C67: 100u; PANASONIC_D
E0-MOT: MA04-1
IC2, IC7: 74HC4053D; SO16
JP1, JP2, JP4, JP5, JP6: PINHD-2X3; 2X03
R5, R6, R8, R10, R26: 100k; R0805
R16, R18, R19, R20, R27: 10k; R0805
R101: 330; R0805
SV1: ML14E; ML14
U$1, U$4, U$6, U$7, U$8: A4988BREAKOUT
X+: MA03-1
X-: MA03-1
X-MOT: MA04-1
Y+: MA03-1
Y-: MA03-1
Y-MOT: MA04-1
Z+: MA03-1
Z-MOT1, Z-MOT2: MA04-1
Z-STOP1, Z-STOP2: MA03-1

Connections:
+5V: C62.2, C68.2, IC2.16 (VCC), IC7.16 (VCC), JP1.2, JP1.4, JP1.6, JP2.2, JP2.4, JP2.6, JP4.2, JP4.4, JP4.6, JP5.2, JP5.4, JP5.6, JP6.2, JP6.4, JP6.6, R16.1, R18.1, R19.1, R20.1, R27.1, U$1.VDD, U$4.VDD, U$6.VDD, U$7.VDD, U$8.VDD, X+.3, X-.3, Y+.3, Y-.3, Z+.3, Z-STOP1.3, Z-STOP2.3; also elsewhere on the board
+12V: C63.+, C64.+, C65.+, C66.+, C67.+, U$1.VMOT, U$4.VMOT, U$6.VMOT, U$7.VMOT, U$8.VMOT; also elsewhere on the board
E0-DIR: U$4.DIR; also elsewhere on the board
E0-EN: R16.2, U$4.EN; also elsewhere on the board
E0-STEP: U$4.STEP; also elsewhere on the board
GND: C11.1, C12.1, C13.1, C14.1, C16.1, C44.1, C45.1, C62.1, C63.-, C64.-, C65.-, C66.-, C67.-, C68.1, IC2.6 (E), IC2.7 (VEE), IC2.8 (GND), IC7.6 (E), IC7.7 (VEE), IC7.8 (GND), R5.2, R6.1, R8.2, R10.2, R26.2, U$1.GND, U$1.GND@0 (GND), U$4.GND, U$4.GND@0 (GND), U$6.GND, U$6.GND@0 (GND), U$7.GND, U$7.GND@0 (GND), U$8.GND, U$8.GND@0 (GND), X+.2, X-.2, Y+.2, Y-.2, Z+.2, Z-STOP1.2, Z-STOP2.2; also elsewhere on the board
unnamed: JP1.3, U$1.MS2
unnamed: E0-MOT.1, U$4.2B
unnamed: E0-MOT.2, U$4.2A
unnamed: JP2.1, R6.2, U$4.MS1
unnamed: JP2.5, U$4.MS3
unnamed: U$4.RST, U$4.SLP (SLEEP)
unnamed: JP2.3, U$4.MS2
unnamed: E0-MOT.3, U$4.1A
unnamed: E0-MOT.4, U$4.1B
unnamed: U$1.RST, U$1.SLP (SLEEP)
unnamed: JP1.5, U$1.MS3
unnamed: JP4.1, R5.1, U$6.MS1
unnamed: JP4.3, U$6.MS2
unnamed: JP1.1, R26.1, U$1.MS1
unnamed: JP5.3, U$7.MS2
unnamed: U$1.2B, Z-MOT2.1
unnamed: JP4.5, U$6.MS3
unnamed: U$6.RST, U$6.SLP (SLEEP)
unnamed: U$6.2B, X-MOT.1
unnamed: U$6.2A, X-MOT.2
unnamed: U$7.RST, U$7.SLP (SLEEP)
unnamed: U$1.2A, Z-MOT2.2
unnamed: U$1.1A, Z-MOT2.3
unnamed: U$6.1A, X-MOT.3
unnamed: U$6.1B, X-MOT.4
unnamed: U$7.2B, Y-MOT.1
unnamed: U$7.2A, Y-MOT.2
unnamed: U$7.1A, Y-MOT.3
unnamed: JP5.5, U$7.MS3
unnamed: JP5.1, R8.1, U$7.MS1
unnamed: U$1.1B, Z-MOT2.4
unnamed: IC2.13 (1Y1), R27.2, U$1.EN
unnamed: U$7.1B, Y-MOT.4
unnamed: JP6.3, U$8.MS2
unnamed: U$8.RST, U$8.SLP (SLEEP)
unnamed: JP6.5, U$8.MS3
unnamed: JP6.1, R10.1, U$8.MS1
unnamed: U$8.2B, Z-MOT1.1
unnamed: U$8.2A, Z-MOT1.2
unnamed: U$8.1A, Z-MOT1.3
unnamed: U$8.1B, Z-MOT1.4
unnamed: IC2.12 (1Y0), R20.2, U$8.EN
unnamed: IC2.5 (3Y0), U$8.STEP
unnamed: IC2.3 (3Y1), U$1.STEP
unnamed: IC2.2 (2Y0), U$8.DIR
unnamed: IC2.1 (2Y1), U$1.DIR
unnamed: R101.1, SV1.5
unnamed: C44.2, IC7.12 (1Y0), Z-STOP1.1
unnamed: C45.2, IC7.13 (1Y1), Z-STOP2.1
X-DIR: U$6.DIR; also elsewhere on the board
X-EN: R18.2, U$6.EN; also elsewhere on the board
X-MAX: C12.2, X+.1; also elsewhere on the board
X-MIN: C11.2, X-.1; also elsewhere on the board
X-STEP: U$6.STEP; also elsewhere on the board
Y-DIR: U$7.DIR; also elsewhere on the board
Y-EN: R19.2, U$7.EN; also elsewhere on the board
Y-MAX: C14.2, Y+.1; also elsewhere on the board
Y-MIN: C13.2, Y-.1; also elsewhere on the board
Y-STEP: U$7.STEP; also elsewhere on the board
Z-DIR: IC2.15 (2Z); also elsewhere on the board
Z-EN: IC2.14 (1Z); also elsewhere on the board
Z-MAX: C16.2, Z+.1; also elsewhere on the board
Z-MIN: IC7.14 (1Z); also elsewhere on the board
Z-STEP: IC2.4 (3Z); also elsewhere on the board
Z-SWITCH: IC2.9 (S3), IC2.10 (S2), IC2.11 (S1), IC7.11 (S1), R101.2; also elsewhere on the board

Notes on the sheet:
Johannes Schmidt

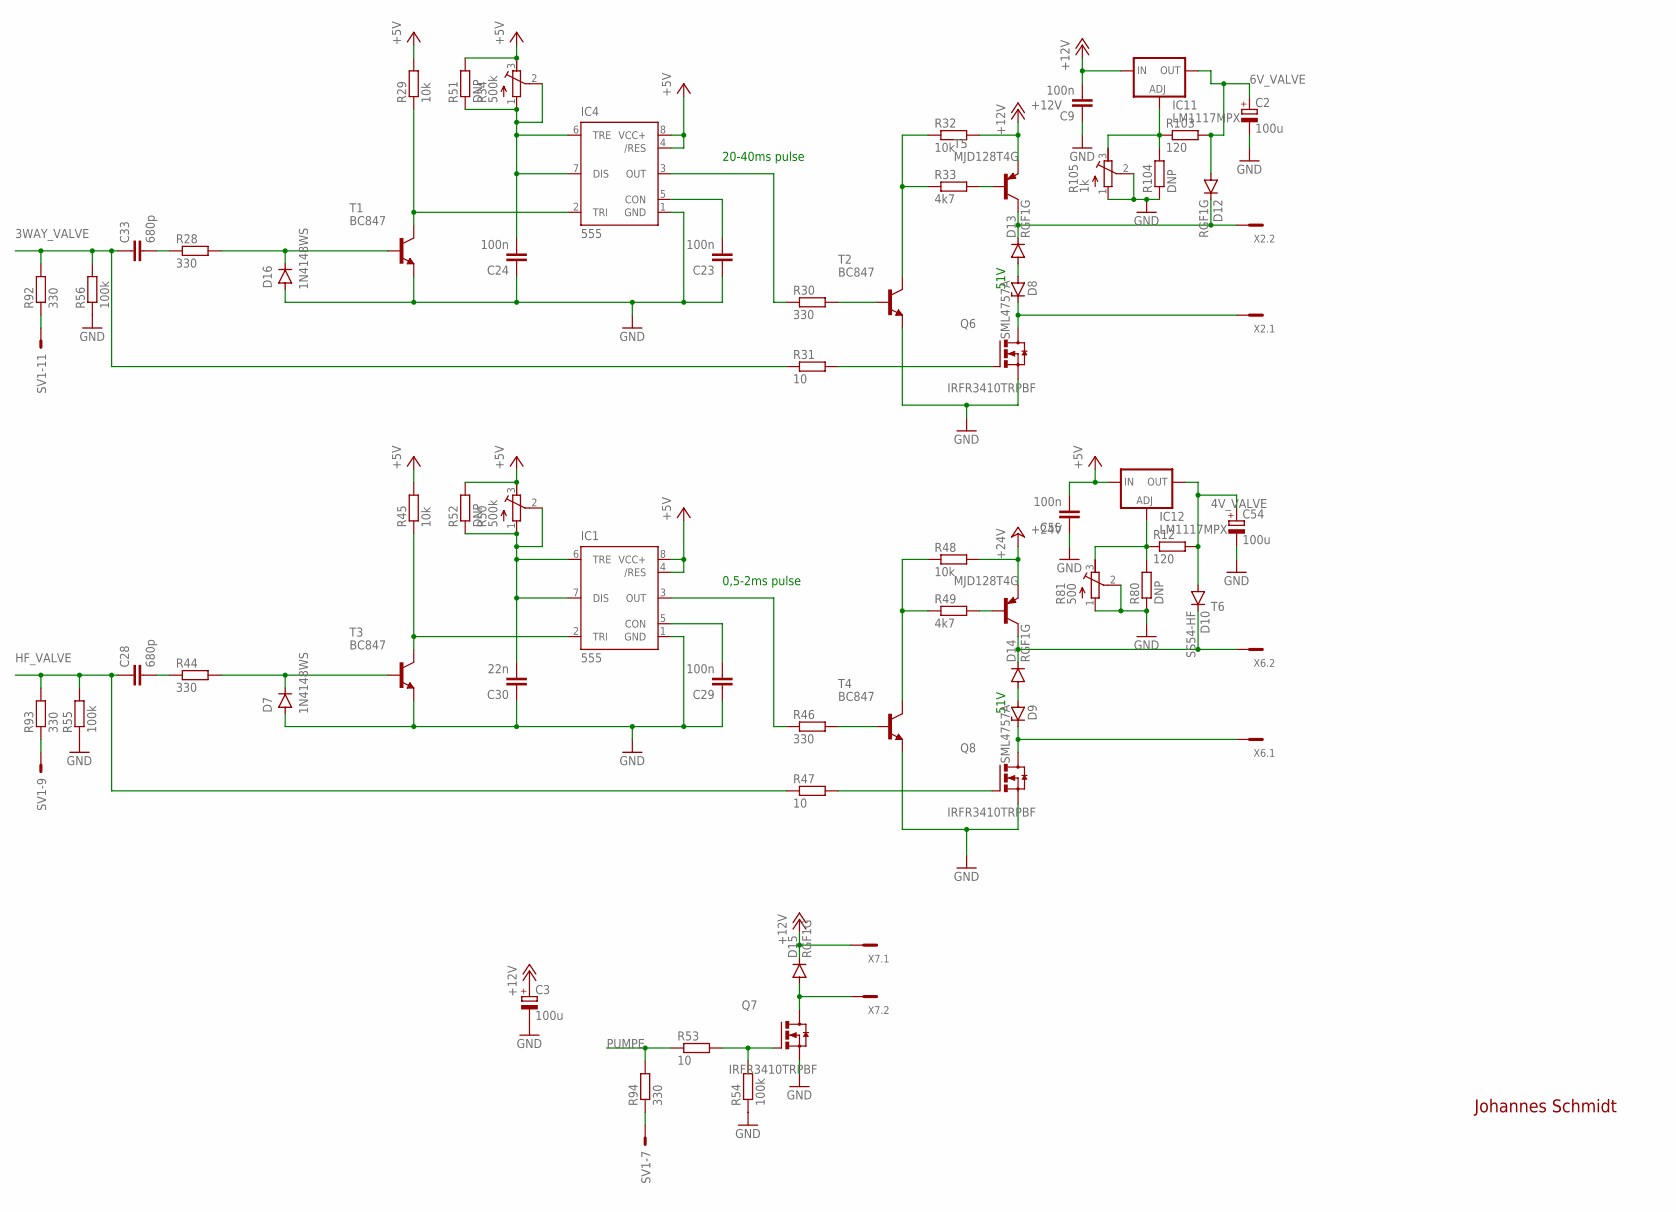
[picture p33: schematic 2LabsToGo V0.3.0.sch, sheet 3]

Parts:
C2, C3, C54: 100u; PANASONIC_D
C9, C23, C24, C29, C55: 100n; C0805
C28, C33: 680p; C0805
C30: 22n; C0805
D7, D16: 1N4148WS; SOD-323
D8, D9: SML4757A; SMB
D10: SS54-HF; DO214AC
D12, D13, D14, D15: RGF1G; DO214AC
IC1, IC4: 555; SO08
IC11, IC12: LM1117MPX; SOT223
Q6, Q7, Q8: IRFR3410TRPBF; DPAK
R12, R103: 120; R0805
R28, R30, R44, R46, R92, R93, R94: 330; R0805
R29, R32, R45, R48: 10k; R0805
R31, R47, R53: 10; R0805
R33, R49: 4k7; R0805
R34, R50: 500k; RTRIM3296W
R51, R52, R80, R104: DNP; R0805
R54, R55, R56: 100k; R0805
R81: 500; RTRIM3296W
R105: 1k; RTRIM3296W
SV1: ML14E; ML14
T1, T2, T3, T4: BC847; SOT23
T5, T6: MJD128T4G; DPAK
X2, X6, X7: MCV2

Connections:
3WAY_VALVE: C33.1, R31.1, R56.2, R92.2; also elsewhere on the board
4V_VALVE: C54.+, D10.A, IC12.4 (OUT), R12.2
6V_VALVE: C2.+, D12.A, IC11.4 (OUT), R103.2
+5V: C55.2, IC1.4 (/RES), IC1.8 (VCC+), IC4.4 (/RES), IC4.8 (VCC+), IC12.3 (IN), R29.2, R34.3 (E), R45.2, R50.3 (E), R51.2, R52.2; also elsewhere on the board
+12V: C3.+, C9.2, D15.C, IC11.3 (IN), R32.2, T5.3 (E), X7.1; also elsewhere on the board
+24V: R48.2, T6.3 (E); also elsewhere on the board
GND: C2.-, C3.-, C9.1, C23.1, C24.1, C29.1, C30.1, C54.-, C55.1, D7.A, D16.A, IC1.1 (GND), IC4.1 (GND), Q6.3 (S), Q7.3 (S), Q8.3 (S), R54.1, R55.1, R56.1, R80.1, R81.1 (A), R81.2 (S), R104.1, R105.1 (A), R105.2 (S), T1.2 (E), T2.2 (E), T3.2 (E), T4.2 (E); also elsewhere on the board
HF_VALVE: C28.1, R47.1, R55.2, R93.2; also elsewhere on the board
unnamed: D8.C, Q6.4 (D), X2.1
unnamed: D8.A, D13.A
unnamed: D12.C, D13.C, T5.4 (C), X2.2
unnamed: R32.1, R33.1, T2.3 (C)
unnamed: R33.2, T5.1 (B)
unnamed: Q6.1 (G), R31.2
unnamed: R30.2, T2.1 (B)
unnamed: C33.2, R28.1
unnamed: D16.C, R28.2, T1.1 (B)
unnamed: IC4.2 (TRI), R29.1, T1.3 (C)
unnamed: C23.2, IC4.5 (CON)
unnamed: C24.2, IC4.6 (TRE), IC4.7 (DIS), R34.1 (A), R34.2 (S), R51.1
unnamed: IC4.3 (OUT), R30.1
unnamed: D9.C, Q8.4 (D), X6.1
unnamed: D9.A, D14.A
unnamed: D10.C, D14.C, T6.4 (C), X6.2
unnamed: R48.1, R49.1, T4.3 (C)
unnamed: R49.2, T6.1 (B)
unnamed: Q8.1 (G), R47.2
unnamed: R46.2, T4.1 (B)
unnamed: C28.2, R44.1
unnamed: D7.C, R44.2, T3.1 (B)
unnamed: IC1.2 (TRI), R45.1, T3.3 (C)
unnamed: C29.2, IC1.5 (CON)
unnamed: C30.2, IC1.6 (TRE), IC1.7 (DIS), R50.1 (A), R50.2 (S), R52.1
unnamed: IC1.3 (OUT), R46.1
unnamed: Q7.1 (G), R53.2, R54.2
unnamed: D15.A, Q7.4 (D), X7.2
unnamed: IC12.1 (ADJ), R12.1, R80.2, R81.3 (E)
unnamed: R92.1, SV1.11
unnamed: R93.1, SV1.9
unnamed: R94.1, SV1.7
unnamed: IC11.1 (ADJ), R103.1, R104.2, R105.3 (E)
PUMPE: R53.1, R94.2; also elsewhere on the board

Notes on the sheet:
0,5-2ms pulse
20-40ms pulse
51V
Johannes Schmidt

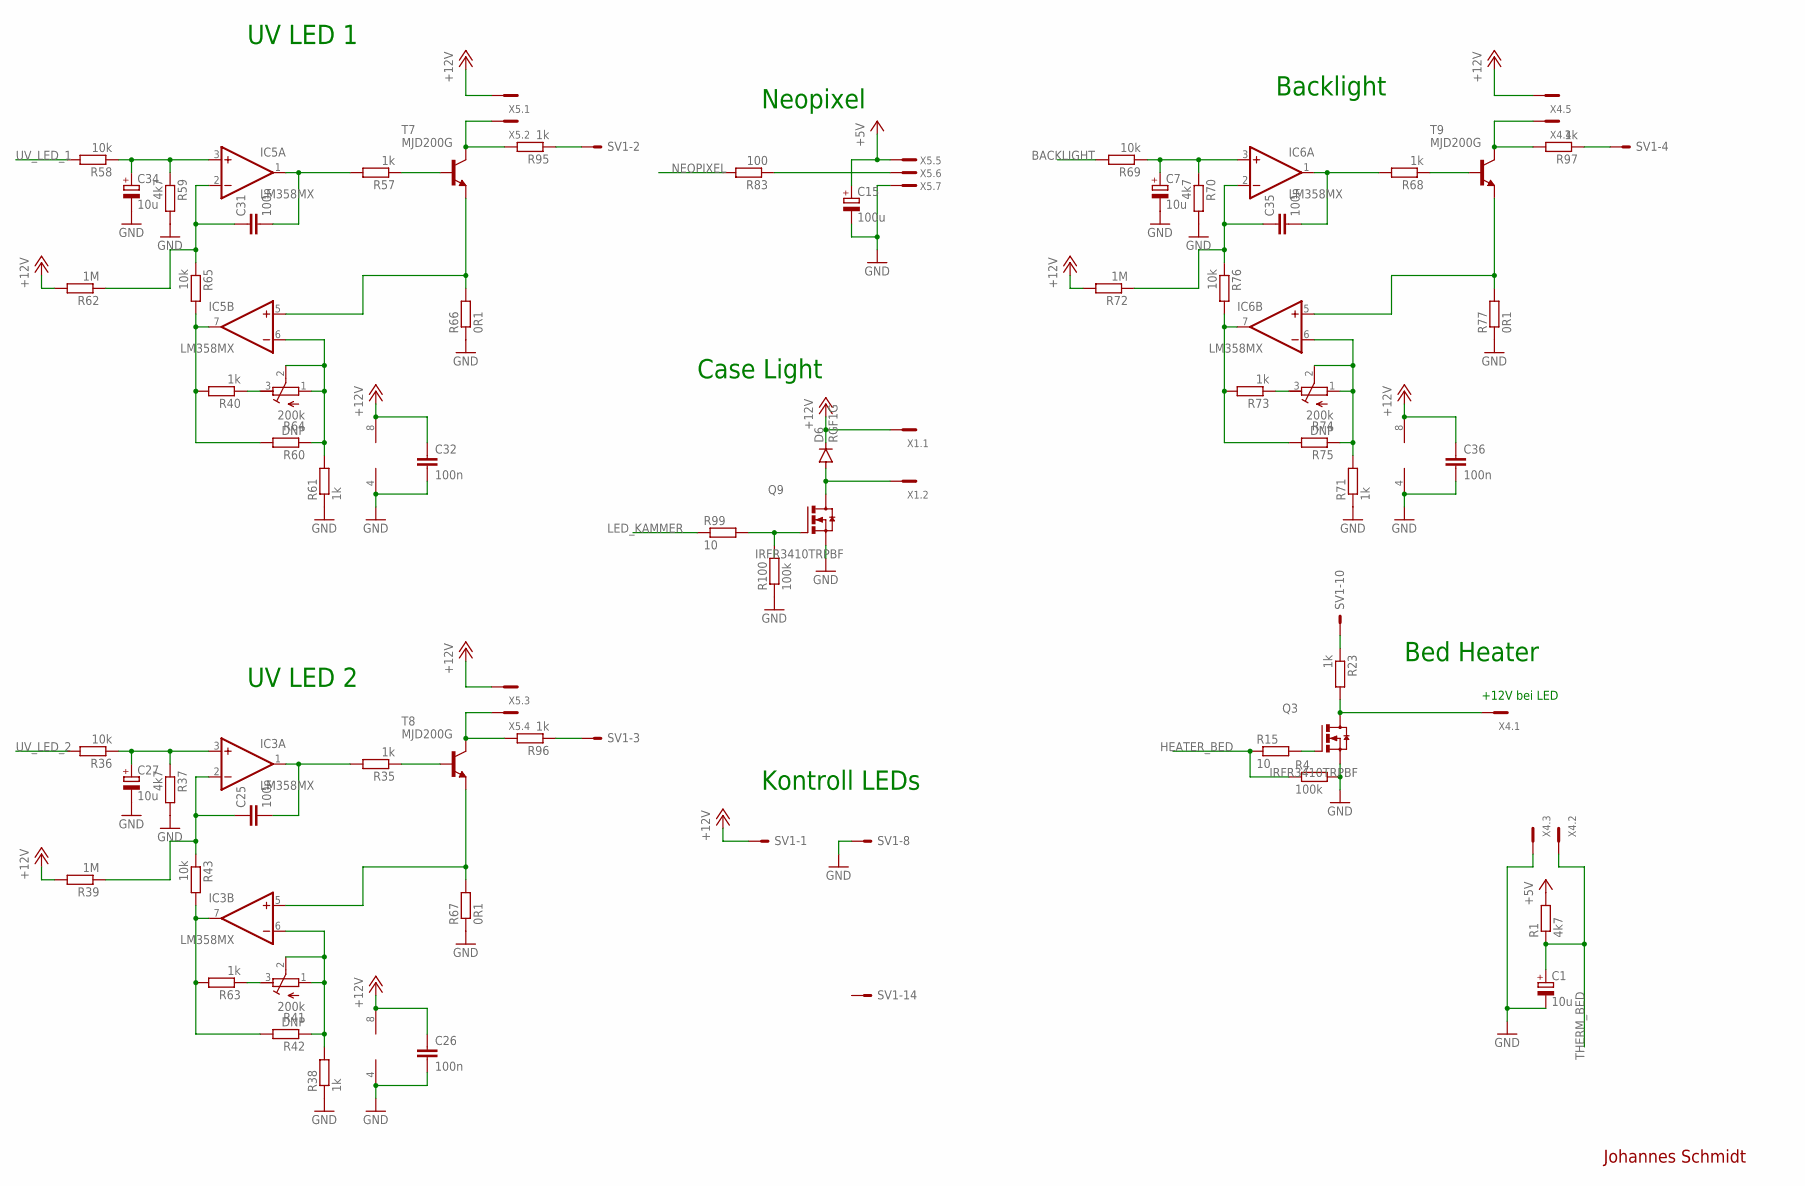
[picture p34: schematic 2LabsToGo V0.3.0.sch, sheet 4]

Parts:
C1, C7, C27, C34: 10u; PANASONIC_B
C15: 100u; PANASONIC_D
C25, C26, C31, C32, C35, C36: 100n; C0805
D6: RGF1G; DO214AC
IC3, IC5, IC6: LM358MX; SO08
Q3, Q9: IRFR3410TRPBF; DPAK
R1, R37, R59, R70: 4k7; R0805
R4, R100: 100k; R0805
R15, R99: 10; R0805
R23, R35, R38, R40, R57, R61, R63, R68, R71, R73, R95, R96, R97: 1k; R0805
R36, R43, R58, R65, R69, R76: 10k; R0805
R39, R62, R72: 1M; R0805
R41, R64, R74: 200k; RTRIM3296W
R42, R60, R75: DNP; R0805
R66, R67, R77: 0R1; R1206
R83: 100; R0805
SV1: ML14E; ML14
T7, T8, T9: MJD200G; DPAK
X1: MCV2
X4: MCV5
X5: MCV7

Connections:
+5V: C15.+, R1.2, X5.5; also elsewhere on the board
+12V: C26.1, C32.1, C36.1, D6.C, IC3.8 (V+), IC5.8 (V+), IC6.8 (V+), R39.2, R62.2, R72.2, SV1.1, X1.1, X4.5, X5.1, X5.3; also elsewhere on the board
BACKLIGHT: R69.2; also elsewhere on the board
GND: C1.-, C7.-, C15.-, C26.2, C27.-, C32.2, C34.-, C36.2, IC3.4 (V-), IC5.4 (V-), IC6.4 (V-), Q3.3 (S), Q9.3 (S), R4.2, R37.2, R38.1, R59.2, R61.1, R66.1, R67.1, R70.2, R71.1, R77.1, R100.1, SV1.8, X4.3, X5.7; also elsewhere on the board
HEATER_BED: R4.1, R15.1; also elsewhere on the board
LED_KAMMER: R99.1; also elsewhere on the board
unnamed: R23.1, SV1.10
unnamed: Q3.1 (G), R15.2
unnamed: Q3.4 (D), R23.2, X4.1
unnamed: IC3.6 (-IN), R38.2, R41.1 (A), R41.2 (S), R42.1
unnamed: IC3.7 (OUT), R42.2, R43.2, R63.2
unnamed: C25.1, IC3.2 (-IN), R39.1, R43.1
unnamed: C25.2, IC3.1 (OUT), R35.2
unnamed: C27.+, IC3.3 (+IN), R36.1, R37.1
unnamed: IC3.5 (+IN), R67.2, T8.3 (E)
unnamed: R35.1, T8.1 (B)
unnamed: R96.2, T8.4 (C), X5.4
unnamed: IC6.6 (-IN), R71.2, R74.1 (A), R74.2 (S), R75.1
unnamed: IC5.6 (-IN), R60.1, R61.2, R64.1 (A), R64.2 (S)
unnamed: IC5.7 (OUT), R40.2, R60.2, R65.2
unnamed: C31.1, IC5.2 (-IN), R62.1, R65.1
unnamed: C34.+, IC5.3 (+IN), R58.1, R59.1
unnamed: C31.2, IC5.1 (OUT), R57.2
unnamed: IC5.5 (+IN), R66.2, T7.3 (E)
unnamed: R57.1, T7.1 (B)
unnamed: R95.2, T7.4 (C), X5.2
unnamed: IC6.7 (OUT), R73.2, R75.2, R76.2
unnamed: C35.1, IC6.2 (-IN), R72.1, R76.1
unnamed: C35.2, IC6.1 (OUT), R68.2
unnamed: C7.+, IC6.3 (+IN), R69.1, R70.1
unnamed: IC6.5 (+IN), R77.2, T9.3 (E)
unnamed: R68.1, T9.1 (B)
unnamed: R97.2, T9.4 (C), X4.4
unnamed: R40.1, R64.3 (E)
unnamed: R83.1, X5.6
unnamed: Q9.1 (G), R99.2, R100.2
unnamed: D6.A, Q9.4 (D), X1.2
unnamed: R97.1, SV1.4
unnamed: R95.1, SV1.2
unnamed: R96.1, SV1.3
unnamed: R41.3 (E), R63.1
unnamed: R73.1, R74.3 (E)
NEOPIXEL: R83.2; also elsewhere on the board
THERM_BED: C1.+, R1.1, X4.2; also elsewhere on the board
UV_LED_1: R58.2; also elsewhere on the board
UV_LED_2: R36.2; also elsewhere on the board

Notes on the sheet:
UV LED 1
UV LED 2
Backlight
Neopixel
Case Light
Kontroll LEDs
+12V bei LED
Bed Heater
Johannes Schmidt

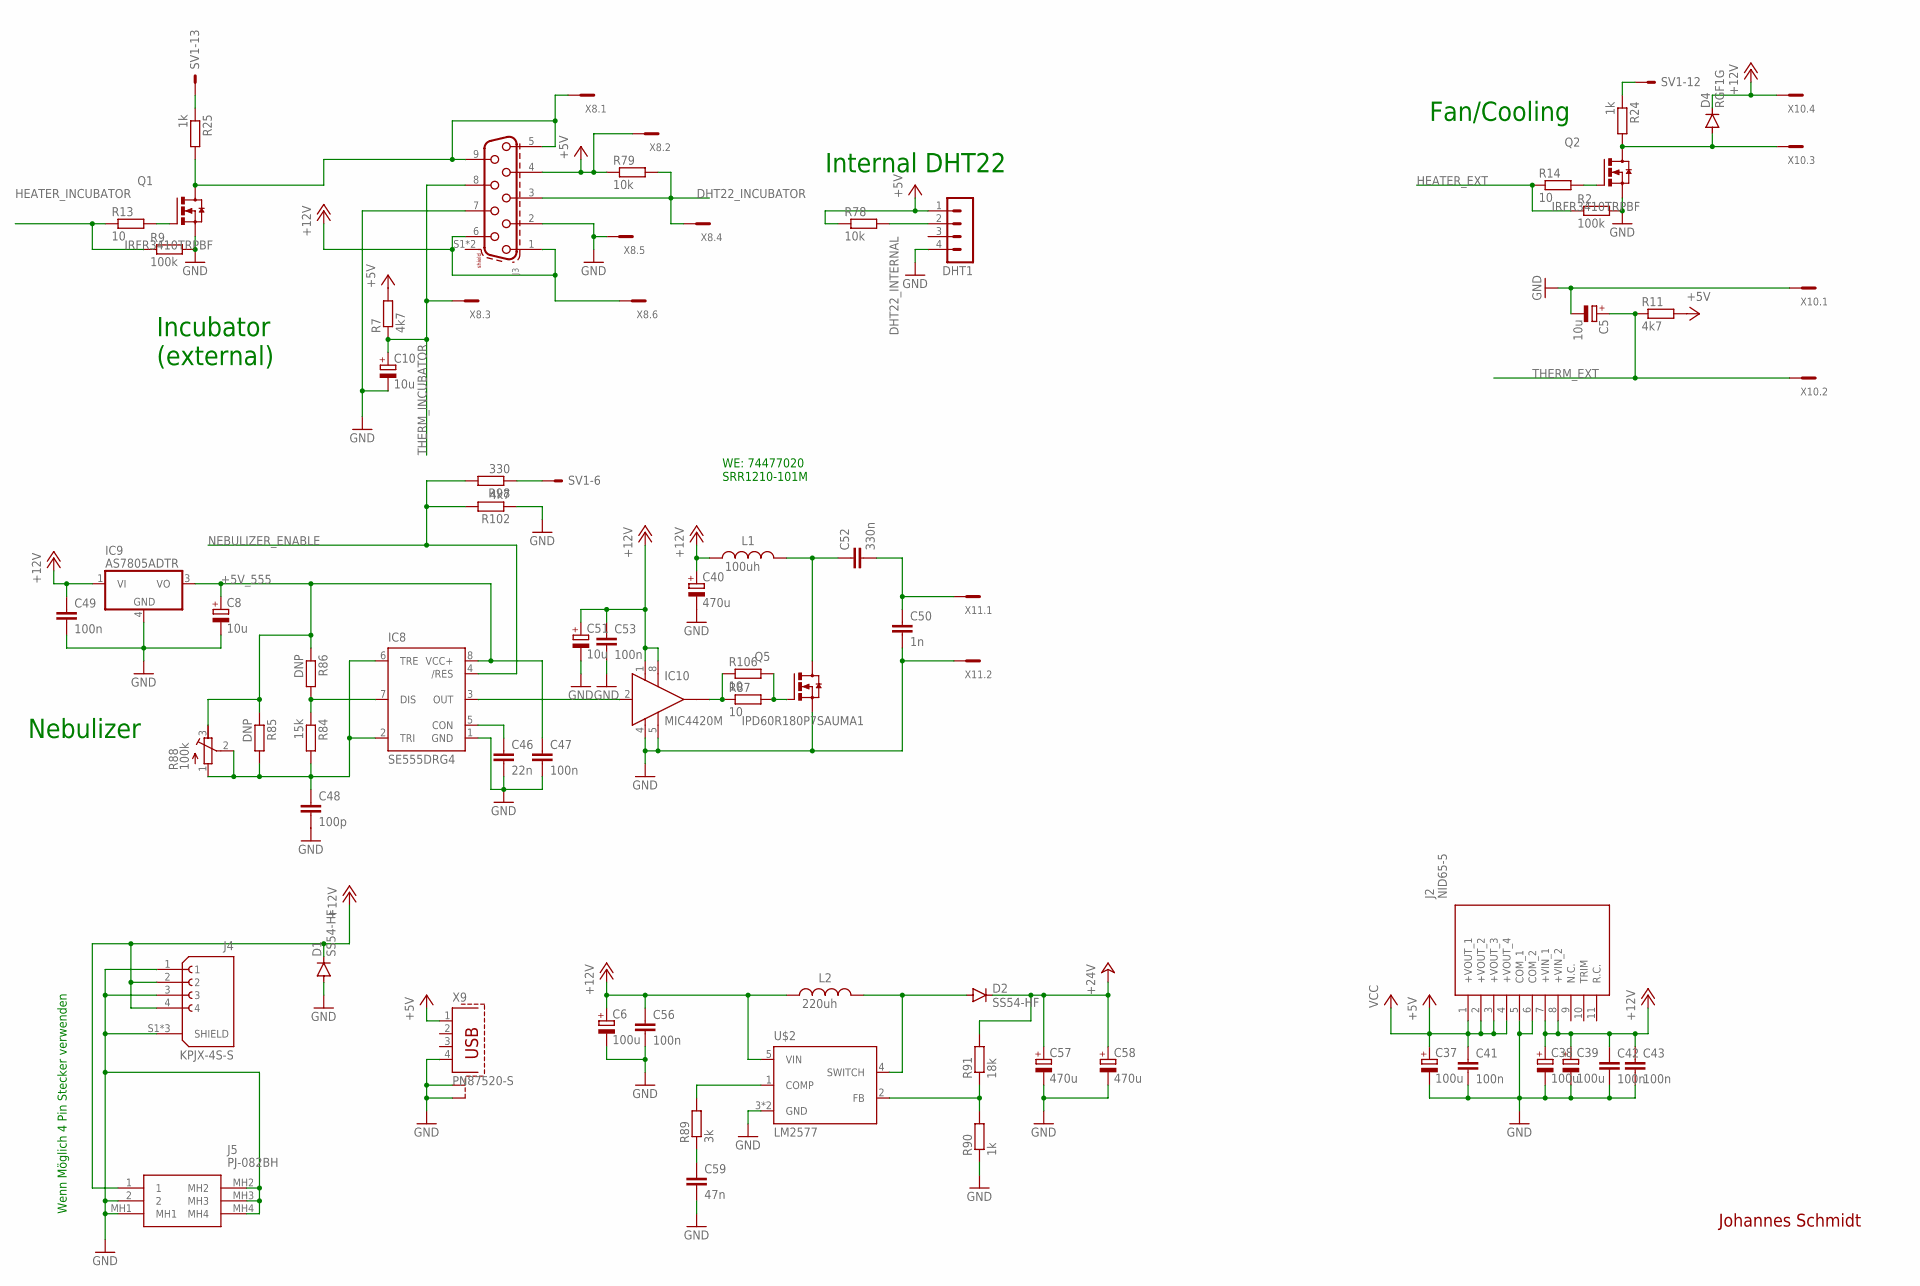
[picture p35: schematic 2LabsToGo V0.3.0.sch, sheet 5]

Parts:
C5, C8, C10, C51: 10u; PANASONIC_B
C6, C37, C38, C39: 100u; PANASONIC_D
C40, C57, C58: 470u; E5-10,5
C41, C42, C43, C47, C49, C53, C56: 100n; C0805
C46: 22n; C0805
C48: 100p; C0805
C50: 1n; C1812
C52: 330n; C1812
C59: 47n; C0805
D1, D2: SS54-HF; DO214AC
D4: RGF1G; DO214AC
DHT1: MA04-1
IC8: SE555DRG4; SO08
IC9: AS7805ADTR; DPAC_NEU
IC10: MIC4420M; SO-08
J2: NID65-5; NID655
J3: 6180XX211821_618009211821; 618009211821
J4: KPJX-4S-S; KYCON_KPJX-4S-S
J5: PJ-082BH; PJ082BH
L1: 100uh; WE-CHSA_1212
L2: 220uh; WE-CHSA_1212
Q1, Q2: IRFR3410TRPBF; DPAK
Q5: IPD60R180P7SAUMA1; DPAK
R2, R9: 100k; R0805
R7, R11, R102: 4k7; R0805
R13, R14, R87, R106: 10; R0805
R24, R25, R90: 1k; R0805
R78, R79: 10k; R0805
R84: 15k; R0805
R85, R86: DNP; R0805
R88: 100k; RTRIM3296W
R89: 3k; R0805
R91: 18k; R0805
R98: 330; R0805
SV1: ML14E; ML14
U$2: LM2577; TO263-5
X8: MC6
X9: PN87520-S
X10: MCV4
X11: MCV2

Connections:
+5V: C37.+, C41.1, DHT1.1, J2.1 (+VOUT_1), J2.2 (+VOUT_2), J2.3 (+VOUT_3), J2.4 (+VOUT_4), J3.4, R7.2, R11.2, R78.1, R79.1, X8.2, X9.1; also elsewhere on the board
+5V_555: C8.+, C47.1, IC8.8 (VCC+), IC9.3 (VO), R85.1, R86.1, R88.3 (E)
+12V: C6.+, C38.+, C39.+, C40.+, C42.1, C43.1, C49.1, C51.+, C53.1, C56.1, D1.C, D4.C, IC9.1 (VI), IC10.1 (VS), IC10.8 (VS1), J2.7 (+VIN_1), J2.8 (+VIN_2), J3.1, J3.6, J4.2, J4.4, J5.1, L1.1, L2.1, U$2.5 (VIN), X8.6, X10.4; also elsewhere on the board
+24V: C57.+, C58.+, D2.C, R91.2; also elsewhere on the board
DHT22_INCUBATOR: J3.3, R79.2, X8.4; also elsewhere on the board
DHT22_INTERNAL: DHT1.2, R78.2; also elsewhere on the board
GND: C5.-, C6.-, C8.-, C10.-, C37.-, C38.-, C39.-, C40.-, C41.2, C42.2, C43.2, C46.2, C47.2, C48.2, C49.2, C50.2, C51.-, C53.2, C56.2, C57.-, C58.-, C59.2, D1.A, DHT1.4, IC8.1 (GND), IC9.4 (GND), IC10.4 (GND), IC10.5 (GND1), J2.5 (COM_1), J2.6 (COM_2), J3.2, J3.7, J4.1, J4.3, J4.S1 (SHIELD), J4.S2 (SHIELD), J4.S3 (SHIELD), J5.2, J5.MH1, J5.MH2, J5.MH3, J5.MH4, Q1.3 (S), Q2.3 (S), Q5.3 (S), R2.2, R9.2, R90.1, R102.1, U$2.3 (GND), U$2.6 (GND), X8.5, X9.4, X9.S1, X9.S2, X10.1, X11.2; also elsewhere on the board
HEATER_EXT: R2.1, R14.1; also elsewhere on the board
HEATER_INCUBATOR: R9.1, R13.1; also elsewhere on the board
unnamed: D4.A, Q2.4 (D), R24.2, X10.3
unnamed: J3.5, J3.9, Q1.4 (D), R25.2, X8.1
unnamed: R24.1, SV1.12
unnamed: Q2.1 (G), R14.2
unnamed: Q1.1 (G), R13.2
unnamed: R25.1, SV1.13
unnamed: IC8.7 (DIS), R84.1, R86.2
unnamed: R98.1, SV1.6
unnamed: IC8.3 (OUT), IC10.2 (IN)
unnamed: IC10.6 (OUT), R87.1, R106.1
unnamed: C48.1, IC8.2 (TRI), IC8.6 (TRE), R84.2, R85.2, R88.1 (A), R88.2 (S)
unnamed: C46.1, IC8.5 (CON)
unnamed: Q5.1 (G), R87.2, R106.2
unnamed: C52.1, L1.2, Q5.4 (D)
unnamed: D2.A, L2.2, U$2.4 (SWITCH)
unnamed: C50.1, C52.2, X11.1
unnamed: R89.2, U$2.1 (COMP)
unnamed: C59.1, R89.1
unnamed: R90.2, R91.1, U$2.2 (FB)
NEBULIZER_ENABLE: IC8.4 (/RES), R98.2, R102.2; also elsewhere on the board
THERM_EXT: C5.+, R11.1, X10.2; also elsewhere on the board
THERM_INCUBATOR: C10.+, J3.8, R7.1, X8.3; also elsewhere on the board

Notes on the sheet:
WE: 74477020 SRR1210-101M
Incubator (external)
Nebulizer
Fan/Cooling
Internal DHT22
Wenn Möglich 4 Pin Stecker verwenden
Johannes Schmidt

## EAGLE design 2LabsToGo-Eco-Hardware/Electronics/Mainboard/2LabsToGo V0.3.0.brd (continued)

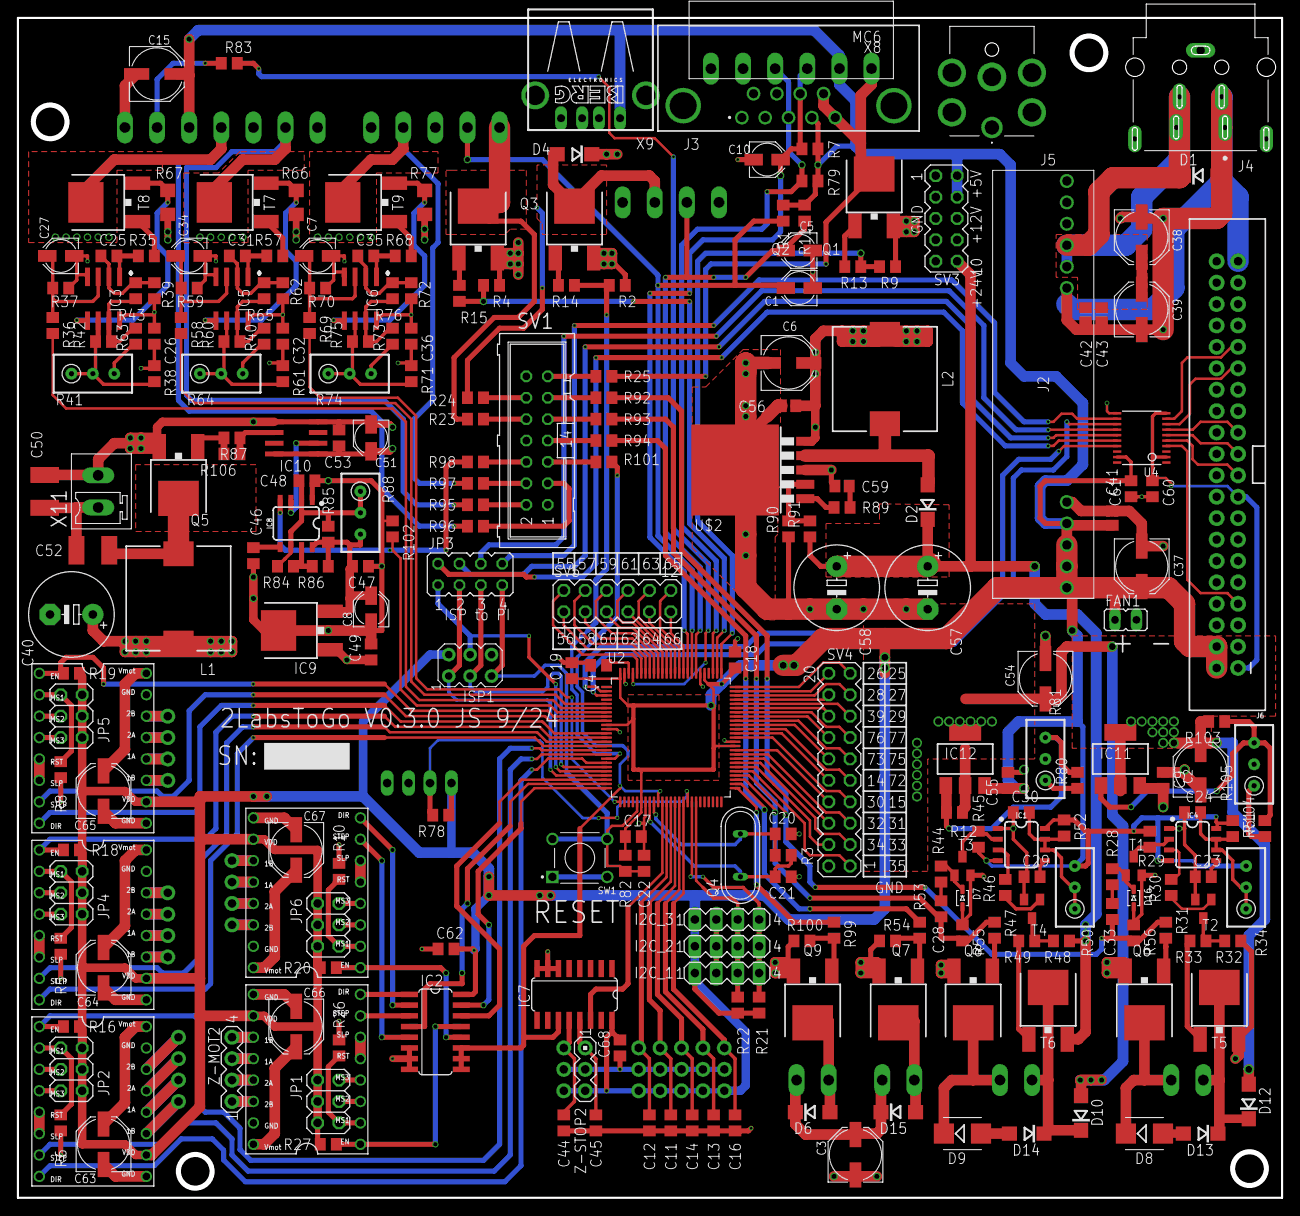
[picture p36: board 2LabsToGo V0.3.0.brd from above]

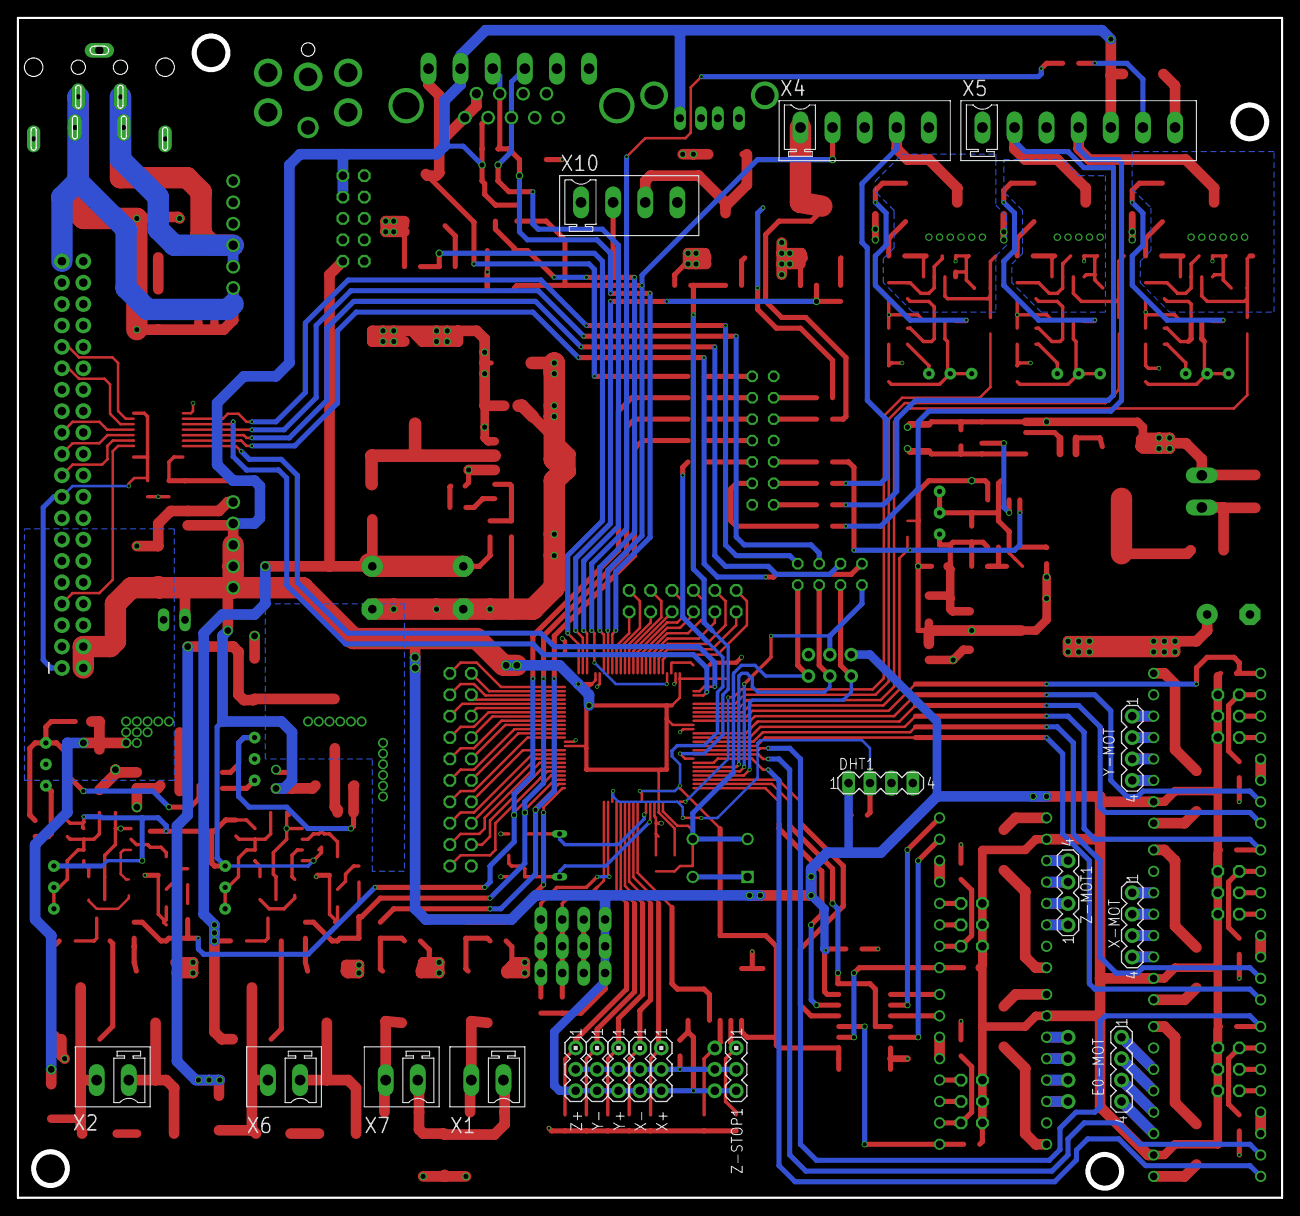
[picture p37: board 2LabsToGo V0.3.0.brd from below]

Board: 4 copper layers, 150.0 x 140.0 mm, 270 parts (18 on the bottom side), 233 nets.

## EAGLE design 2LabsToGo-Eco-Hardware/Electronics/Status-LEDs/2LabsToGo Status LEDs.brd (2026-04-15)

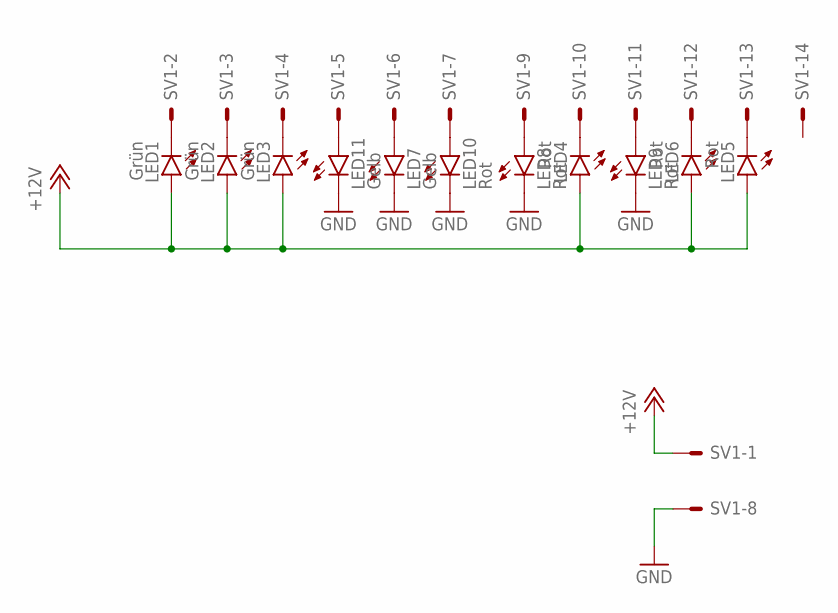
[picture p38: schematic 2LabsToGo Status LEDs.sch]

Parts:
LED1, LED2, LED3: Grün; CHIP-LED0805
LED4, LED5, LED6, LED8, LED9, LED10: Rot; CHIP-LED0805
LED7, LED11: Gelb; CHIP-LED0805
SV1: ML14E; ML14

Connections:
+12V: LED1.A, LED2.A, LED3.A, LED4.A, LED5.A, LED6.A, SV1.1
GND: LED7.C, LED8.C, LED9.C, LED10.C, LED11.C, SV1.8
unnamed: LED1.C, SV1.2
unnamed: LED2.C, SV1.3
unnamed: LED3.C, SV1.4
unnamed: LED4.C, SV1.10
unnamed: LED5.C, SV1.13
unnamed: LED6.C, SV1.12
unnamed: LED7.A, SV1.6
unnamed: LED8.A, SV1.9
unnamed: LED9.A, SV1.11
unnamed: LED10.A, SV1.7
unnamed: LED11.A, SV1.5

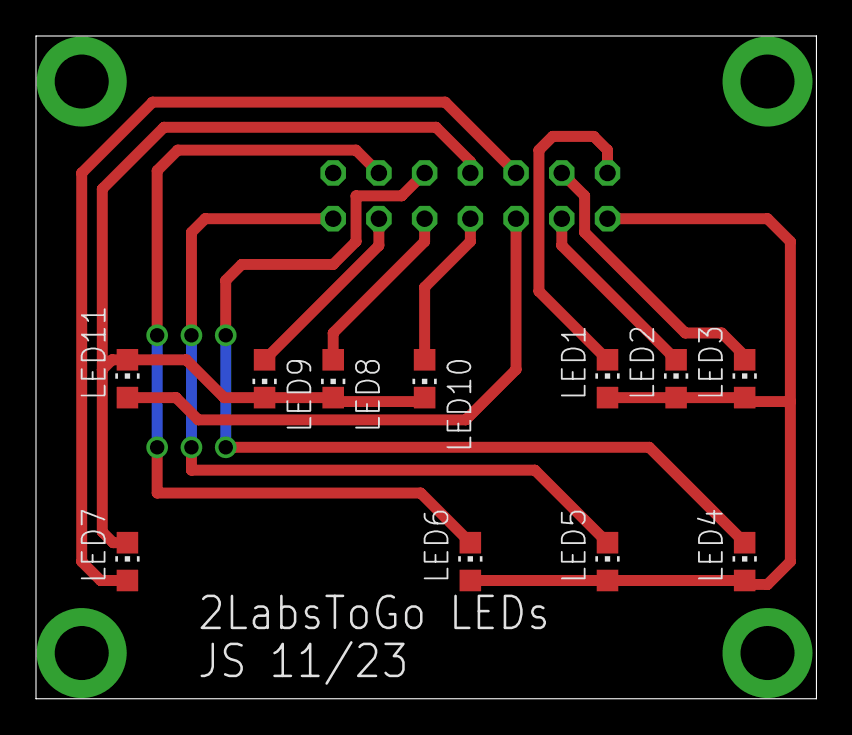
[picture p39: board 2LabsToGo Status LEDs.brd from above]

Board: 2 copper layers, 43.4 x 36.8 mm, 12 parts (1 on the bottom side), 13 nets.

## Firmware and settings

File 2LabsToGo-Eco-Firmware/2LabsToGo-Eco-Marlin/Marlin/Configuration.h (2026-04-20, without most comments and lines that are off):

#pragma once
#define CONFIGURATION_H_VERSION 020005
#define HUMIDITY_CONTROL_GCODE_DOWN  //turn on drying box fan for drying
#define HUMIDITY_CONTROL_GCODE_UP  //turn on drying box fan for humidifyling
#define STRING_CONFIG_H_AUTHOR "(none, default config)" // Who made the changes.
#define SHOW_BOOTSCREEN
#define SERIAL_PORT 0
#define BAUDRATE 115200
  #define MOTHERBOARD BOARD_RAMPS_14_EFB
#define EXTRUDERS 1
#define DEFAULT_NOMINAL_FILAMENT_DIA 3.0
#define TEMP_SENSOR_0 1
#define TEMP_SENSOR_1 0
#define TEMP_SENSOR_2 0
#define TEMP_SENSOR_3 0
#define TEMP_SENSOR_4 0
#define TEMP_SENSOR_5 0
#define TEMP_SENSOR_6 0
#define TEMP_SENSOR_7 0
#define TEMP_SENSOR_BED 11
#define TEMP_SENSOR_PROBE 0
#define TEMP_SENSOR_CHAMBER 0
#define DUMMY_THERMISTOR_998_VALUE 25
#define DUMMY_THERMISTOR_999_VALUE 100
#define MAX_REDUNDANT_TEMP_SENSOR_DIFF 10
#define TEMP_RESIDENCY_TIME     10  // (seconds) Time to wait for hotend to "settle" in M109
#define TEMP_WINDOW              1  // (°C) Temperature proximity for the "temperature reached" timer
#define TEMP_HYSTERESIS          3  // (°C) Temperature proximity considered "close enough" to the target
#define TEMP_BED_RESIDENCY_TIME 10  // (seconds) Time to wait for bed to "settle" in M190
#define TEMP_BED_WINDOW          1  // (°C) Temperature proximity for the "temperature reached" timer
#define TEMP_BED_HYSTERESIS      3  // (°C) Temperature proximity considered "close enough" to the target
#define HEATER_0_MINTEMP   -20
#define HEATER_1_MINTEMP   -20
#define HEATER_2_MINTEMP   -20
#define HEATER_3_MINTEMP   -20
#define HEATER_4_MINTEMP   -20
#define HEATER_5_MINTEMP   -20
#define HEATER_6_MINTEMP   -20
#define HEATER_7_MINTEMP   -20
#define BED_MINTEMP        5
#define HEATER_0_MAXTEMP 275
#define HEATER_1_MAXTEMP 275
#define HEATER_2_MAXTEMP 275
#define HEATER_3_MAXTEMP 275
#define HEATER_4_MAXTEMP 275
#define HEATER_5_MAXTEMP 275
#define HEATER_6_MAXTEMP 275
#define HEATER_7_MAXTEMP 275
#define BED_MAXTEMP      130
#define PIDTEMP
#define BANG_MAX 255     // Limits current to nozzle while in bang-bang mode; 255=full current
#define PID_MAX BANG_MAX // Limits current to nozzle while PID is active (see PID_FUNCTIONAL_RANGE below); 255=full current
#define PID_K1 0.95      // Smoothing factor within any PID loop
  #define PID_FUNCTIONAL_RANGE 10 // If the temperature difference between the target temperature and the actual temperature
  #define DEFAULT_Kp 22.2
  #define DEFAULT_Ki 1.08
  #define DEFAULT_Kd 114
#define PIDTEMPBED
  #define DEFAULT_bedKp 67.41
  #define DEFAULT_bedKi 6.53
  #define DEFAULT_bedKd 463.90
#define EXTRUDE_MINTEMP 170
#define PREVENT_LENGTHY_EXTRUDE
#define EXTRUDE_MAXLENGTH 200
#define USE_YMIN_PLUG
#define USE_XMAX_PLUG
#define USE_ZMAX_PLUG
#define X_MIN_ENDSTOP_INVERTING true // Set to true to invert the logic of the endstop.
#define Y_MIN_ENDSTOP_INVERTING true // Set to true to invert the logic of the endstop.
#define Z_MIN_ENDSTOP_INVERTING false // Set to true to invert the logic of the endstop.
#define X_MAX_ENDSTOP_INVERTING true // Set to true to invert the logic of the endstop.
#define Y_MAX_ENDSTOP_INVERTING false // Set to true to invert the logic of the endstop.
#define Z_MAX_ENDSTOP_INVERTING false // Set to true to invert the logic of the endstop.
#define X_DRIVER_TYPE A4988
#define Y_DRIVER_TYPE A4988
#define Z_DRIVER_TYPE  A4988
#define E0_DRIVER_TYPE A4988
#define DEFAULT_AXIS_STEPS_PER_UNIT   { 100, 100, 400, 1600 }  //GT2 16 teeth, for 20 teeth: {80, 80, ...}
#define DEFAULT_MAX_FEEDRATE          { 300, 300, 5, 5 }
#define DEFAULT_MAX_ACCELERATION      { 3000, 3000, 300, 10000 }
#define DEFAULT_ACCELERATION          300    // X, Y, Z and E acceleration for printing moves
#define DEFAULT_RETRACT_ACCELERATION  300    // E acceleration for retracts
#define DEFAULT_TRAVEL_ACCELERATION   300    // X, Y, Z acceleration for travel (non printing) moves
#define DEFAULT_EJERK    5.0  // May be used by Linear Advance
  #define JUNCTION_DEVIATION_MM 0.013 // (mm) Distance from real junction edge
#define NOZZLE_TO_PROBE_OFFSET { 10, 10, 0 }
#define MIN_PROBE_EDGE 10
#define XY_PROBE_SPEED 8000
#define Z_PROBE_SPEED_FAST HOMING_FEEDRATE_Z
#define Z_PROBE_SPEED_SLOW (Z_PROBE_SPEED_FAST / 2)
#define Z_CLEARANCE_DEPLOY_PROBE   10 // Z Clearance for Deploy/Stow
#define Z_CLEARANCE_BETWEEN_PROBES  5 // Z Clearance between probe points
#define Z_CLEARANCE_MULTI_PROBE     5 // Z Clearance between multiple probes
#define Z_PROBE_LOW_POINT          -2 // Farthest distance below the trigger-point to go before stopping
#define Z_PROBE_OFFSET_RANGE_MIN -20
#define Z_PROBE_OFFSET_RANGE_MAX 20
#define X_ENABLE_ON 0
#define Y_ENABLE_ON 0
#define Z_ENABLE_ON 0
#define E_ENABLE_ON 0 // For all extruders
#define DISABLE_X false
#define DISABLE_Y false
#define DISABLE_Z false
#define DISABLE_E false             // For all extruders
#define DISABLE_INACTIVE_EXTRUDER   // Keep only the active extruder enabled
#define INVERT_X_DIR false
#define INVERT_Y_DIR false
#define INVERT_Z_DIR true
#define INVERT_E0_DIR true
#define INVERT_E1_DIR false
#define INVERT_E2_DIR false
#define INVERT_E3_DIR false
#define INVERT_E4_DIR false
#define INVERT_E5_DIR false
#define INVERT_E6_DIR false
#define INVERT_E7_DIR false
#define Z_HOMING_HEIGHT  0      // (mm) Minimal Z height before homing (G28) for Z clearance above the bed, clamps, ...
#define Z_AFTER_HOMING  0      // (mm) Height to move to after homing Z
#define X_HOME_DIR 1
#define Y_HOME_DIR -1
#define Z_HOME_DIR 1
#define X_BED_SIZE 130
#define Y_BED_SIZE 200
#define X_MIN_POS 0
#define Y_MIN_POS 0
#define Z_MIN_POS 0
#define X_MAX_POS X_BED_SIZE
#define Y_MAX_POS Y_BED_SIZE
#define Z_MAX_POS 300  //For syringe length (scale length) 60 mm, but AS needs 300 mm
#define MIN_SOFTWARE_ENDSTOPS
  #define MIN_SOFTWARE_ENDSTOP_X
  #define MIN_SOFTWARE_ENDSTOP_Y
  #define MIN_SOFTWARE_ENDSTOP_Z
#define MAX_SOFTWARE_ENDSTOPS
  #define MAX_SOFTWARE_ENDSTOP_X
  #define MAX_SOFTWARE_ENDSTOP_Y
  #define MAX_SOFTWARE_ENDSTOP_Z
#define HOMING_FEEDRATE_XY (5000)
#define HOMING_FEEDRATE_Z  (1000)
#define VALIDATE_HOMING_ENDSTOPS
#define EEPROM_CHITCHAT       // Give feedback on EEPROM commands. Disable to save PROGMEM.
#define EEPROM_BOOT_SILENT    // Keep M503 quiet and only give errors during first load
#define HOST_KEEPALIVE_FEATURE        // Disable this if your host doesn't like keepalive messages
#define DEFAULT_KEEPALIVE_INTERVAL 2  // Number of seconds between "busy" messages. Set with M113.
#define BUSY_WHILE_HEATING            // Some hosts require "busy" messages even during heating
#define PREHEAT_1_LABEL       "PLA"
#define PREHEAT_1_TEMP_HOTEND 180
#define PREHEAT_1_TEMP_BED     70
#define PREHEAT_1_FAN_SPEED     0 // Value from 0 to 255
#define PREHEAT_2_LABEL       "ABS"
#define PREHEAT_2_TEMP_HOTEND 240
#define PREHEAT_2_TEMP_BED    110
#define PREHEAT_2_FAN_SPEED     0 // Value from 0 to 255
#define NOZZLE_PARK_FEATURE
  #define NOZZLE_PARK_POINT { (X_MIN_POS + 10), (Y_MAX_POS - 10), 20 }
  #define NOZZLE_PARK_XY_FEEDRATE 100   // (mm/s) X and Y axes feedrate (also used for delta Z axis)
  #define NOZZLE_PARK_Z_FEEDRATE 5      // (mm/s) Z axis feedrate (not used for delta printers)
#define PRINTJOB_TIMER_AUTOSTART
#define LCD_LANGUAGE en
#define DISPLAY_CHARSET_HD44780 JAPANESE
#define LCD_INFO_SCREEN_STYLE 0
#define SOFT_PWM_SCALE 0
#define SERVO_DELAY { 300 }

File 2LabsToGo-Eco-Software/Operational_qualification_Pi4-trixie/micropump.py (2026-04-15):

#!/usr/bin/env python3

#file micropump.py

import serial
import time
import os


def command(ser, command):
  ser.write(str.encode(command)) 
  time.sleep(1)

ser = serial.Serial('/dev/ttyAMA3', 115200)
time.sleep(1)

#Marlin settings for autosampler
command(ser, "M92Z400\r\n")   #Set Axis Steps-per-unit
command(ser, "M203Z15\r\n")   #Set Max Feedrate
command(ser, "M42P36S0\r\n")  #Switch 3way-valve
command(ser, "M42P49S0\r\n")  #Switch Z-motor and Z-endstop
command(ser, "G28Z\r\n")      #Homing Z
command(ser, "G28X\r\n")      #Homing X
command(ser, "G0X1F3000\r\n")      #x-cart to 1eft
command(ser, "G0Z145\r\n")    #Rinsing vial

print("First the system will be rinsed, followed by a pressure test.")
print("")
os.system("aplay --quiet BusinessEcho.wav")
print("In case of problems, terminate the program immediately with Ctrl+c and press the RESET button on the mainboard!")
print("")
os.system("aplay --quiet BusinessEcho.wav")
input("Start the rinsing process? (ENTER)")
os.system("aplay --quiet BusinessEcho.wav")
print("")
print("Now the needle is moving into the rinsing vial, and the micropump system will be rinsed. Solvent will be ejected from the dispensing valve into the waste bottle.")
print("")
command(ser, "G0E44\r\n")  #Needle moves down! 44 okay!!
command(ser, "M400\r\n")   #Wait for needle!
command(ser, "G41\r\n")  #open dispensing valve

try:
    for x in range(14):      #rinse system, 15 x pump = 500 µL
        command(ser, "M42P40S255\r\n")  #activate pump
        time.sleep(0.1)
        command(ser, "M42P40S0\r\n")  #deactivate pump
        time.sleep(0.5)
except KeyboardInterrupt:  #Ctrl+c
    os.system("aplay --quiet BusinessEcho.wav")
    print("Program terminated manually!")
    command(ser, "G0E0\r\n")  #Needle moves up!
    command(ser, "M400\r\n")  #Wait for neddle
    command(ser, "G28Z\r\n")  #Homing vial rack
    raise SystemExit 

os.system("aplay --quiet BusinessEcho.wav")
print("Now the dispensing valve will be closed and the micropump builds-up pressure.")
print("")
command(ser, "G40\r\n")  #Close dispensing valve

try:
    for x in range(3):      #build-up pressure, 4 x pump
        command(ser, "M42P40S255\r\n")
        time.sleep(0.1)
        command(ser, "M42P40S0\r\n")
        time.sleep(0.5)
except KeyboardInterrupt:  #Ctrl+c
    os.system("aplay --quiet BusinessEcho.wav")
    print("Program terminated manually!")
    command(ser, "G0E0\r\n")  #Needle moves up!
    command(ser, "M400\r\n") 
    raise SystemExit 

print("Now the dispensing valve will be opened. Solvent will be ejected from the dispensing valve into the waste bottle.")
print("")
command(ser, "G40\r\n")  #open valve
time.sleep(1)

print("The dispensing valve was closed again and the needle is moving up.")
print("")
command(ser, "G0E0\r\n")  #Needle moves up!
command(ser, "M400\r\n")  #Wait for needle!
command(ser, "G28Z\r\n")  #Homing z!

print("Congratulations, the micropump test was successfully passed!!")
print("If there were leakages, tighten the fittings.").

time.sleep(1)
ser.close()

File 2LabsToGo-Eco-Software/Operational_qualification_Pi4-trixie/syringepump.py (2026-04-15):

#!/usr/bin/env python3

#file syringepump.py

import serial
import time
import os

def command(ser, command):
  ser.write(str.encode(command)) 
  time.sleep(1)

ser = serial.Serial('/dev/ttyAMA3', 115200)
#time.sleep(1)

#Marlin settings for syringe pump
command(ser, "M92Z1600\r\n")   #Set Axis Steps-per-unit
command(ser, "M203Z5\r\n")     #Set Max Feedrate
#z-switch
command(ser, "M42P36S255\r\n") #Switch 3way-valve
command(ser, "M42P49S255\r\n") #Switch Z-motor and Z-endstop
command(ser, "G28Z\r\n")       #Homing syringe pump

command(ser, "G28X\r\n")       #Homing X
command(ser, "G0X1F3000\r\n")  #x-axis to waste bottle

os.system("aplay --quiet BusinessEcho.wav")
print("Fill a 2-mL syringe with 2 mL ethanol, connect the Luer-lock adapter to the tip, and insert it into the syringe pump.")
print("")
command(ser, "G0Z274.67F200\r\n") #Move to position for syringe 2 mL

print("Connect the PTFE tube to the Luer-lock adapter and tighten it with the Lee torque wrench (min. torque).")
print("")
print("First the system will be rinsed, followed by a pressure test.")
print("")
os.system("aplay --quiet BusinessEcho.wav")
print("In case of problems, terminate the program immediately with Ctrl+c!")
print("")

input("Ready to start the rinsing process? (ENTER)")
#time.sleep(1)
print("")
os.system("aplay --quiet BusinessEcho.wav")
print("Now the fluidic system will be rinsed with 500 µL. The solvent will be ejected from the dispensing valve into the waste bottle.")
print("")

try:
    command(ser, "G41\r\n") #open dispensing valve
    command(ser, "G0Z281.34F200\r\n") #Move to position to rinse 500 µL (+6.67 mm)
    command(ser, "G40\r\n") #close dispensing valve
    os.system("aplay --quiet BusinessEcho.wav")
    print("Now the dispensing valve was closed, and the syringe pump will build-up a pressure of 5 psi.")
    print("")
    command(ser, "G97P5\r\n") #5 psi
    command(ser, "M400\r\n")  #Wait for pressure    command(ser, "G95P\r\n")  #Report pressure, is not possible
    time.sleep(1)
    
    os.system("aplay --quiet BusinessEcho.wav")
    print("The pressure will be increased to 10 psi. Also check the 3-way valve!")
    print("")
    command(ser, "G97P10\r\n") #10 psi
    command(ser, "GM400\r\n")  #Wait for pressure
    command(ser, "G95P\r\n")  #Report pressure.
    time.sleep(1)
    
    os.system("aplay --quiet BusinessEcho.wav")
    #print("The pressure will be increased to 15 psi.")
    print("")
    command(ser, "G97P15\r\n") #15 psi
    command(ser, "GM400\r\n")  #Wait for pressure
    command(ser, "G95P\r\n")  #Report pressure
    time.sleep(1)
    
    os.system("aplay --quiet BusinessEcho.wav")
    print("Now the pressure will be increased to 20 psi.")
    print("")
    command(ser, "G97P20\r\n") #20 psi
    command(ser, "GM400\r\n")  #Wait for pressure
    command(ser, "G95P\r\n")  #Report pressure
    time.sleep(1)
    os.system("aplay --quiet BusinessEcho.wav")
    print("The dispensing valve will be opened to leave the pressure. Solvent will be ejected from the dispensing valve into the waste bottle.")
    print("")
    command(ser, "G40\r\n")  #Open valve
    time.sleep(1)
except KeyboardInterrupt:  #Ctrl+c
    os.system("aplay --quiet BusinessEcho.wav")
    print("Program terminated manually!")
    command(ser, "G40\r\n")  #Open valve to leave the pressure!
    command(ser, "M400\r\n") 
    raise SystemExit 
    
#Marlin re-settings for autosampler
command(ser, "M92Z400\r\n")   #Set Axis Steps-per-unit
command(ser, "M203Z15\r\n")   #Set Max Feedrate
command(ser, "M42P36S0\r\n")  #Switch 3way-valve
command(ser, "M42P49S0\r\n")  #Switch Z-motor and Z-endstop

os.system("aplay --quiet BusinessEcho.wav")
print("Congratulations, the syringe pump test was successfully passed!!")
print("If there were leakages, tighten the fittings.")

time.sleep(1)
ser.close()

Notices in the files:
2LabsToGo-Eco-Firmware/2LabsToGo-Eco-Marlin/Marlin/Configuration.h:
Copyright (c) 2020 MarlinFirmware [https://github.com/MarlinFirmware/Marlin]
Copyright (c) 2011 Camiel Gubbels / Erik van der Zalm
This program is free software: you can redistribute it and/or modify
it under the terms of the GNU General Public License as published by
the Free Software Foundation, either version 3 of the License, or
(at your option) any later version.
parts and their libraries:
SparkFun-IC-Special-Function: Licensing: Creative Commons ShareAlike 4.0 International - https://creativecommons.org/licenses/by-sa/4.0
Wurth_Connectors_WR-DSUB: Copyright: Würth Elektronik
